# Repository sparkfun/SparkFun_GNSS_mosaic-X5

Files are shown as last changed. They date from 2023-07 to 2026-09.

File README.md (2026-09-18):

SparkFun Tri-band GNSS RTK Breakout - mosaic-X5
========================================

SparkFun Tri-band GNSS RTK Breakout - mosaic-X5 (https://www.sparkfun.com/sparkfun-triband-gnss-rtk-breakout-mosaic-x5.html)

[*SparkFun Tri-band GNSS RTK Breakout - mosaic-X5 (GPS-23088)*](https://www.sparkfun.com/sparkfun-triband-gnss-rtk-breakout-mosaic-x5.html)

At the heart of the Triband GNSS RTK Breakout is [Septentrio](https://www.septentrio.com/en)'s mosaic-X5, a compact, low power, multi-band, multi-constellation, high-precision GNSS receiver. The receiver supports the GPS (USA), GLONASS (Russia), Beidou (China), Galileo (Europe), and NavIC (India) constellations, including regional systems *(i.e. SBAS and QZSS)*. With its [**Real Time Kinematics**](https://learn.sparkfun.com/tutorials/813) (RTK) capabilities, the module can achieve a horizontal accuracy of 6mm (~0.25in), vertical accuracy of 1cm (~0.4in) using RTK, and timing precision of 5ns (5 billionths of a second). It also features Septentrio's unique [AIM+ technology](https://www.septentrio.com/en/learn-more/advanced-positioning-technology/aim-jamming-protection) for interference mitigation and anti-spoofing, ensuring best-in-class reliability and scalable position accuracy.

The mosaic-X5 is a sophisticated chip running an internal web server that can be accessed through the USB interface with a standard browser using a Linux/Windows computer. Septentrio also provides dozens of [video tutorials](https://www.youtube.com/@SeptentrioGNSS/videos) to guide users through the configuration settings of their GNSS receivers utilizing the web interface.

Beyond the capabilities of the mosaic-X5 module, this board is seamless to operate with no programming skills required. Gone are the times when a microcontroller was required to interface with the GNSS receiver and log data to an SD card and when users had to carry around an SD card reader to extract the data from the SD card. The mosaic-X5 Triband GNSS RTK Breakout can start/stop logging data or mount/unmount the SD card, without a single line of code, just utilizing a simple button. For the users who prefer a command-line interface, Septentrio has you covered. Users can still control and configure the mosaic-X5 module through a CLI, which is useful for scenarios such as production line testing *(in fact, that is how we tested this board)*.

This breakout board is a perfect middle ground for users who would like to integrate the mosaic-X5 module into a project/enclosure with access to a majority of the module's available pins, similar to Septentrio's developer kit, but in the smaller form factor of their evaluation kit. Or maybe... you just needed a PPS output at a 3.3V logic level. *Please, check out our [hookup guide](https://docs.sparkfun.com/SparkFun_GNSS_mosaic-X5) for more details on the capabilities of this board (that we couldn't fit in this product description).*

Documentation
--------------

- **[Hookup Guide (mkdocs)](http://docs.sparkfun.com/SparkFun_GNSS_mosaic-X5/)** - Hookup guide for the mosaic-X5 GNSS Breakout hosted by GitHub pages.<br>
   

Repository Contents
-------------------

- **[/docs](/docs/)** - Online documentation files
  - [assets](/docs/assets/) - Assets files
    - [board_files](/docs/assets/board_files/) - Files for the product design
      - [Eagle design files](/docs/assets/board_files/eagle_files.zip) (.zip)
      - [Schematic](/docs/assets/board_files/schematic.pdf) (.pdf)
      - [Dimensions](/docs/assets/board_files/dimensions.pdf) (.pdf)
    - [component_documentation](/docs/assets/component_documentation/) - Datasheets for hardware components
    - [img/hookup_guide/](/docs/assets/img/hookup_guide/) - Images for hookup guide documentation
- **[/Hardware](/Hardware/)** - Eagle design files (.brd, .sch)
  - **[/Production](/Production/)** - Production files

Product Variants
----------------

- mosaic-X5:
  - [GPS-23088](https://www.sparkfun.com/sparkfun-triband-gnss-rtk-breakout-mosaic-x5.html) - Triband GNSS RTK Breakout - mosaic-X5
  - [SXM-E](https://www.sparkpnt.com/products/sparkpnt-sxm-e-cors) - RTK mosaic-X5
  - [GPS-24903](https://www.sparkfun.com/sparkpnt-rtk-facet-mosaic-l-band.html) - SparkPNT RTK Facet mosaic L-Band
  - Flex Modules:
    - [GPS-28138](https://www.sparkfun.com/sparkpnt-gnss-flex-module-mosaic-x5.html) - GNSS Flex module - mosaic-X5
    - [GPS-29457](https://www.sparkfun.com/sparkpnt-gnss-flex-module-mosaic-x5-im19-imu.html) - GNSS Flex module - mosaic-X5 & IM19
    - [GPS-28766](https://www.sparkfun.com/sparkfun-gnss-flex-phat-mosaic-x5.html) - GNSS Flex pHAT w/ the mosaic-X5 GNSS Flex module
    - [GPS-29889](https://www.sparkfun.com/sparkfun-gnss-flex-phat-mosaic-x5-im19-imu.html) - GNSS Flex pHAT w/ the mosaic-X5 & IM19 GNSS Flex module
- mosaic-G5 P3:
  - [GPS-29208]( - GNSS RTK Breakout - mosaic-G5 P3
  - Flex Modules:
    - [GPS-29209](https://www.sparkfun.com/sparkpnt-gnss-flex-module-mosaic-g5-p3.html) - GNSS Flex module - mosaic-G5 P3
    - [GPS-29363](https://www.sparkfun.com/sparkpnt-gnss-flex-module-mosaic-g5-p3-im19-imu.html) - GNSS Flex module - mosaic-G5 P3 & IM19
    - [GPS-](https://www.sparkfun.com/sparkfun-gnss-flex-phat-mosaic-g5-p3.html) - GNSS Flex pHAT w/ the mosaic-G5 P3 GNSS Flex module
    - [GPS-](https://www.sparkfun.com/sparkfun-gnss-flex-phat-mosaic-g5-p3-im19-imu.html) - GNSS Flex pHAT w/ the mosaic-G5 P3 & IM19 GNSS Flex module
- mosaic-T:
  - [GPS-28731](https://www.sparkfun.com/sparkfun-timing-gnss-breakout-mosaic-t.html) - mosaic-T Timing GNSS Breakout
  - [SXT](https://www.sparkpnt.com/products/sxt-gnssdo) - GNSS Disciplined Oscillator

Version History
---------------

- [v10](https://github.com/sparkfun/SparkFun_GNSS_mosaic-X5/releases/tag/v10) - Initial Release

License Information
-------------------

This product is ***open source***!

Please review the [`LICENSE.md`](./LICENSE.md) file for license information.

If you have any questions or concerns about licensing, please contact technical support on our [SparkFun forums](https://community.sparkfun.com/).

Distributed as-is; no warranty is given.

- Your friends at SparkFun.

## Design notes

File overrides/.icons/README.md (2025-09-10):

.icons directory
====================
This folder should contain branding logos for the product documentation

## General Images
- `sfe.svg` - SparkFun flame logo
- `kicad-primary.svg` - Full KiCad logo

## Directory
- `logo` - Other available logos

## SVG Optimizer
- [Remove meta data from svg](https://jakearchibald.github.io/svgomg/)

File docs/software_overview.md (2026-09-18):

---
icon: fontawesome/solid/computer
---

!!! danger "Important: Read Before Use!"
	!!! warning "ESD Sensitivity"
		The mosaic-X5 module is sensitive to [ESD](https://en.wikipedia.org/wiki/Electrostatic_discharge "Electrostatic Discharge"). Use a proper grounding system to make sure that the working surface and the components are at the same electric potential.

		??? info "ESD Precaution"
			As recommended by the manufacturer, we highly recommend that users take the necessary precautions to avoid damaging their module.

			- The Tri-band GNSS RTK breakout board features ESD protection on the USB-C connector and breakout's I/O:
				- USB data lines
				- I/O PTH pads
				- JST connector's pins
			- The mosaic-X5 module features internal ESD protection to the `ANT_1` antenna input.

			<div class="grid cards" markdown>

			<div markdown>

			<article class="video-500px" style="margin: auto;" markdown>
			<iframe src="https://www.youtube.com/embed/hrL5J6Q5gX8?si=jOPBat8rzMnL7Uz4&amp;start=26;&amp;end=35;" title="Septentrio: Getting Started Video (playback starts at ESD warning)" frameborder="0" allow="accelerometer; autoplay; clipboard-write; encrypted-media; gyroscope; picture-in-picture" allowfullscreen></iframe>
			</article>

			</div>

			-   <a href="https://www.sparkfun.com/ifixit-anti-static-wrist-strap.html">
				<figure markdown>
				Product Thumbnail
				</figure>		

				---

				**iFixit Anti-Static Wrist Strap**<br>
				TOL-25572</a>

			</div>

!!! note
	The mosaic-X5 module has numerous capabilities and a multitude of ways to configure and interface with them. Without regurgitating all the information that is documented in Septentrio's user manuals and videos, we have tried to highlight a good majority of the module's aspects.

	With that said, please feel free to [file an issue](../github/file_issue/#discrepancies-in-the-documentation) if you feel we have missed something that may benefit other users. *(Don't forget to provide us with a link to the documentation and what section the information is located.)*

## RxTools Software Suite

!!! tip
	Even if you aren't necessarily interested it, we highly recommend that users install the [RXTools software suite](https://www.septentrio.com/en/products/gps-gnss-receiver-software/rxtools) before plugging in their board. For Windows PCs, it also includes the USB driver for the module that enables the Ethernet-over-USB support and virtual `COM` ports.

Users should install the [RXTools software suite](https://www.septentrio.com/en/products/gps-gnss-receiver-software/rxtools) on their computer to interact with the mosaic-X5 module through the USB interface. The software package includes the USB-IP driver[^1] necessary to recognize the board as an ethernet device on Windows PCs (1).
{ .annotate }

1. On Linux, the standard Linux CDC-ACM driver is suitable.

[^1]: On Linux, the standard Linux CDC-ACM driver is suitable.

<article style="text-align: center;" markdown>
[:octicons-download-16:{ .heart } Download the RxTools Software from Septentrio](https://www.septentrio.com/en/products/gps-gnss-receiver-software/rxtools){ .md-button .md-button--primary target="blank" }
</article>

??? info "System Requirements[^2]"

	=== "Operating Systems"
	
		* Windows 7
		* Windows 8
		* Windows 10
		* Fedora 23 *(or later)* using Qt technology.
			* The standalone tools (except `bin2asc`) will run on older distributions.
	
	=== "Hardware Requirements"
		The minimal hardware requirements *(1Hz update[^3])*:
	
		* CPU: 1 GHz processor
		* RAM: 1 GB RAM
		* Screen Resolution: 1024×768 or higher resolution

	[^2]: The system requirements and installation instructions are from the RxTools *v22.1.0* user manual. This information may change in later iterations of the software suite. Please refer to the user manual *(of the version you are utilizing)* for the most accurate information.
	[^3]: Higher data rates will require higher CPU speed and more memory capacity.

??? info "Installation Instructions[^2]"

	=== "Windows"
		Users can install RxTools software suite by running the installation executable[^4](1), located in the `RxTools\windows` directory of the downloaded `*.zip` file[^5]. During the installation process, users will be notified if a previous version of RxTools is already installed then that the previous version will be uninstalled. Next, users will need to provide an installation directory for the RxTools software suite. Users will then select which of the following applications[^6] are installed:
		{ .annotate }

		1. For RxTools v22.1.0, the installation filename is `RxTools_22_1_0_Installer.exe` for Windows PCs.

		<!-- Create Break from Annotation (list won't render without comment)-->

		<div class="grid" markdown>

		<div markdown>

		* RxControl
		* SBF Converter
		* SBF Analyzer
		* RxLogger

		</div>

		<div markdown>

		* RxUpgrade
		* RxDownload
		* RxPlanner

		</div>

		<div markdown>

		* Data Link
		* RxAssistant
		* RxLauncher

		</div>

		</div>

	=== "Linux[^1]"
		!!! warning
			It is recommended that users **<span style="color:red">NOT</span>** install RxControl as `root`, for security reasons and to avoid installation overwrites of other system settings. To make RxTools available to more than one user, provide a shared installation directory.

		Users can install RxTools software suite by running the installation binary[^4](1), located in the `RxTools/linux-i386/` directory of the downloaded `*.zip` file[^5]. During the installation, users will be prompted for an installation directory. If there are any previous installations of RxControl, please use a different directory to avoid conflicts.
		{ .annotate }

		1. For RxTools v22.1.0, the installation filename is `RxTools_22_1_0_Installer.bin` for Linux.

		??? info "Permission Settings"
			Once installed, users may need to reconfigure their permission settings:

			<div class="annotate" markdown>

			* RxTools will need rights to access the `/dev/ttyS*` serial ports.

				* To access the serial ports, users must be part of the `uucp` and `lock` groups (1). This can be configured by editing the `/etc/group`[^7] file and adding the username to the lines defining the `uucp` group and the `lock` group.

					For example, when adding the user `jsmith` to the `uucp` group, users would modify the `/etc/group` file as shown below:

					```bash
					{--uucp:x:14:uucp--} # (2)!
					{++uucp:x:14:uucp,jsmith++} # (3)!
					```

				* On Linux machine administered centrally on a local network, ask your system administrator to be included in the `uucp` and `lock` groups.
			* RxTools also needs read/write (`rw`) access(4) to the `/dev/ttyS*` serial ports.

				* Users can change the permissions with the `chmod`[^8] command:

					```bash
					chmod 660 /dev/ttyS<add port> # (5)!>
					```

			</div>

			1. On most Linux operating systems, the `/dev/ttyS*` devices are owned by `root` and belong to the `uucp` group with read/write (`rw`) access. Additionally, the devices are normally locked by writing a file in the `/var/lock/` directory, with the same permissions.
			2. Remove
			3. Replace with this line
			4. By default, users will normally have read/write (`rw`) access to the `/dev/ttyS*` serial ports.
			5. where users must specify the port number<br>*e.g. `/dev/ttyS0` might be port `COM1`*

			!!! note
				In order for these changes to take effect, users must update their environment by logging out and back in.

				Be aware that the X-session has to be restarted as well. On most systems, this can be done by pressing the key combination ++ctrl++ + ++alt++ + ++backspace++

		??? info "64-bit OS"
			In order to run the RxTools on a 64-bit Linux operating system, users might to install the 32-bit version of the `C` standard library.

			* For Fedora installations, this is the `glibc.i686` package.
			* The equivalent for Debian(/Ubuntu) installations is the `ia32-libs` package.

	[^4]: Users will need administrative privileges to install the RxTools software.
	[^5]: Users may need to extract the RxTools installation files from the downloaded, compressed file.
	[^6]: Please see the release notes for the issues and limitations of the RxTools applications.
	[^7]: Requires c privileges.
	[^8]: Changing these permissions also requires `root` privileges.

## USB Driver
=== "Windows"
	If users haven't already installed the [RxTools software suite](https://www.septentrio.com/en/products/gps-gnss-receiver-software/rxtools) on their Windows PC, they will need to install the USB driver[^1] necessary to recognize and interact with the mosaic-X5 module through the USB interface.

	A Windows USB driver for the mosaic-X5 can be installed through two methods:

	<div class="annotate" markdown>

	* RxTools Software Suite (1)
	* mosaic-X5 GNSS Receiver Module (2)

	</div>

	1. The driver is installed during the installation process.
	2. The installation file for the Windows USB driver will be available from the mass-storage device when the board is initially connected to the computer.

	Once installed, the driver emulates two virtual serial ports, which can be accessed as standard `COM` ports to the receiver.

	??? tip "Terminal Emulators"
		Most [terminal emulation programs](https://learn.sparkfun.com/tutorials/112) will not make a distinction between virtual or native COM ports. However, for virtual serial ports, the port settings *(i.e. baudrate, etc.)* are not relevant and the default configuration be used in the terminal emulation program. However, for the physical/native `COM` ports will have the following default setting:

		* Baudrate: 115200bps
		* Data Bits: 8
		* Parity: No
		* Stop Bits: 1
		* Flow Control: None

	??? tip "Having Trouble?"
		For users who are having trouble installing the USB driver, we have an archived version *(v3.0.2[^9])* of the installation file. Users can download [**version 3.0.2**](./assets/component_documentation/driver/USB_driver_3_0_2_Installer.exe) of the driver, by clicking on the button below.

		[^9]:
			For the latest USB driver from Septentrio, please install their driver through the [RxTools software suite](../rxtools).<br>
			*This is driver version, was archived at the time that this guide was written. Please do not request for the file to be updated.*

		<article style="text-align: center;" markdown>
		[:octicons-download-16:{ .heart } Download USB Driver *(v3.0.2)*](./assets/component_documentation/driver/USB_driver_3_0_2_Installer.exe){ .md-button .md-button--primary target="blank" }
		</article>

=== "Linux"
	On Linux, the standard Linux CDC-ACM driver is suitable.

## Web Interface
With the USB driver installed, the mosaic-X5 module supports Ethernet-over-USB. The default IP address allocated for the Ethernet-over-USB interface is `192.168.3.1`. This IP can be entered in any browser to open a connection to the receiver's Web Interface as shown below.

<div class="grid" markdown>

<div markdown>

<figure markdown>
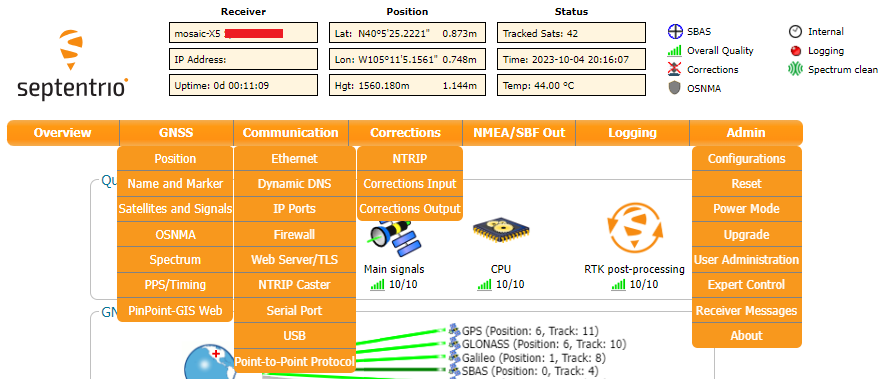
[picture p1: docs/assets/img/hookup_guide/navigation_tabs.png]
navigation tabs in the web interface

<figcaption markdown>All the drop-down navigation tabs in the web interface.</figcaption>
</figure>

</div>

<div markdown>

<article class="video-500px" style="margin: auto;" markdown>
<iframe src="https://www.youtube.com/embed/hrL5J6Q5gX8" title="Septentrio: Getting started with the Septentrio mosaic receiver module" frameborder="0" allow="accelerometer; autoplay; clipboard-write; encrypted-media; gyroscope; picture-in-picture" allowfullscreen></iframe>
</article>

</div>

</div>

!!! info
	The default IP address cannot be changed; this feature is only to be used when a single receiver is connected to your computer.

??? failure "Invalid IP Address *(WiFi Only)*"
	[One of the documentation pages on Septentrio's website](https://customersupport.septentrio.com/s/article/What-is-the-default-IP-address-to-connect-via-WiFi), specifies a default IP address of `192.168.20.1` for the web interface. However, that address is for a WiFi enabled product and cannot be used with this product.

## Arduino Library
The [Eridano-Septentrio Arduino Library](https://github.com/septentrio-gnss/Eridano) can be installed from the library manager in the Arduino IDE by searching for:

	Eridano-Septentrio Arduino Library

<div class="grid" markdown>

<div markdown>

<figure markdown>
Library listed in the library manager of the Arduino IDE Click to enlarge
<figcaption markdown>Eridano-Septentrio Arduino Library in the library manager of the Arduino IDE.</figcaption>
</figure>

</div>

<div markdown>

!!! tip "Manually Download the Arduino Library"
	For users who would like to manually download and install the library, the `*.zip` file can be accessed from the [GitHub repository](https://github.com/septentrio-gnss/Eridano) or downloaded by clicking the button below.

	<article style="text-align: center;" markdown>
	[:octicons-download-16:{ .heart } Download the Arduino Library](https://github.com/septentrio-gnss/Eridano/archive/refs/heads/main.zip){ .md-button .md-button--primary }
	</article>

</div>

</div>

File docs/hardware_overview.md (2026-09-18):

---
icon: material/cog
---

!!! danger "Important: Read Before Use!"
	!!! warning "ESD Sensitivity"
		The mosaic-X5 module is sensitive to [ESD](https://en.wikipedia.org/wiki/Electrostatic_discharge "Electrostatic Discharge"). Use a proper grounding system to make sure that the working surface and the components are at the same electric potential.

		??? info "ESD Precaution"
			As recommended by the manufacturer, we highly recommend that users take the necessary precautions to avoid damaging their module.

			- The Tri-band GNSS RTK breakout board features ESD protection on the USB-C connector and breakout's I/O:
				- USB data lines
				- I/O PTH pads
				- JST connector's pins
			- The mosaic-X5 module features internal ESD protection to the `ANT_1` antenna input.

			<div class="grid cards" markdown>

			<div markdown>

			<article class="video-500px" style="margin: auto;" markdown>
			<iframe src="https://www.youtube.com/embed/hrL5J6Q5gX8?si=jOPBat8rzMnL7Uz4&amp;start=26;&amp;end=35;" title="Septentrio: Getting Started Video (playback starts at ESD warning)" frameborder="0" allow="accelerometer; autoplay; clipboard-write; encrypted-media; gyroscope; picture-in-picture" allowfullscreen></iframe>
			</article>

			</div>

			-   <a href="https://www.sparkfun.com/ifixit-anti-static-wrist-strap.html">
				<figure markdown>
				Product Thumbnail
				</figure>		

				---

				**iFixit Anti-Static Wrist Strap**<br>
				TOL-25572</a>

			</div>

	!!! warning "Active Antenna"
		Never inject an external DC voltage into the SMA connector for the GPS antenna, as it may damage the mosaic-X5 module. For instance, when using a splitter to distribute the antenna signal to several GNSS receivers, make sure that no more than one output of the splitter passes DC. Use [DC-blocks](https://en.wikipedia.org/wiki/DC_block) otherwise.

		??? info
			A 3 - 5.5V DC voltage can be applied to the main antenna from the `VANT` pin, obviating the need for an external antenna supply or [bias-tee](https://en.wikipedia.org/wiki/Bias_tee).

## Board Dimensions
The board dimensions are illustrated in the drawing below; the listed measurements are in inches.

<figure markdown>
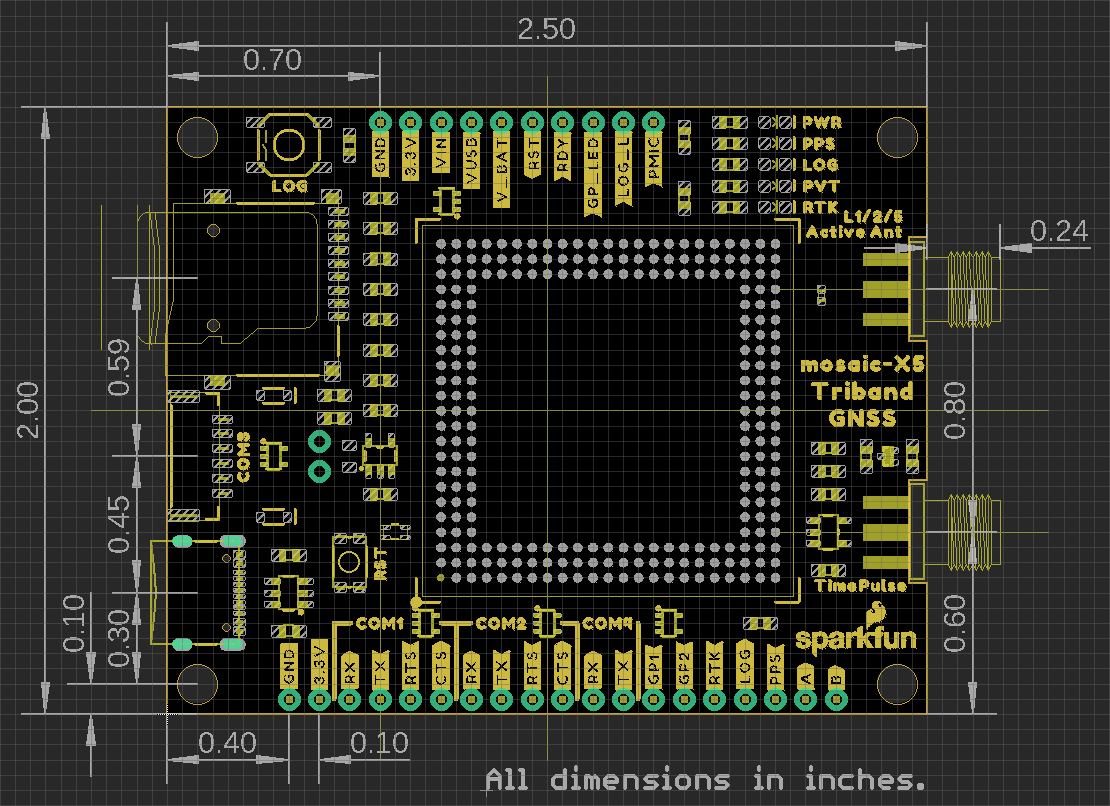
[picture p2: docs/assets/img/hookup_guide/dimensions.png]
Board Dimensions

<figcaption markdown>[Board dimensions (PDF)](./assets/board_files/dimensions.pdf) for the Tri-band GNSS RTK breakout board, in inches.</figcaption>
</figure>

??? tip "Need more measurements?"
	For more information about the board's dimensions, users can download the [eagle files](./assets/board_files/eagle_files.zip) for the board. These files can be opened in Eagle and additional measurements can be made with the dimensions tool.

	??? info ":octicons-download-16:{ .heart } Eagle - Free Download!"
		Eagle is a [CAD]("computer-aided design") program for electronics that is free to use for hobbyists and students. However, it does require an account registration to utilize the software.

		<article style="text-align: center;" markdown>
		[Download from<br>:autodesk-primary:{ .autodesk }](https://www.autodesk.com/products/eagle/free-download "Go to downloads page"){ .md-button .md-button--primary width="250px" }
		</article>
	
	??? info ":straight_ruler: Dimensions Tool"
		This video from Autodesk demonstrates how to utilize the dimensions tool in Eagle, to include additional measurements:

		<article style="text-align: center;" markdown>
		<div class="video-500px" style="margin: auto;" markdown>
		<iframe src="https://www.youtube.com/embed/dZLNd1FtNB8" title="EAGLE Dimension Tool" frameborder="0" allow="accelerometer; autoplay; clipboard-write; encrypted-media; gyroscope; picture-in-picture" allowfullscreen></iframe>
		</div>
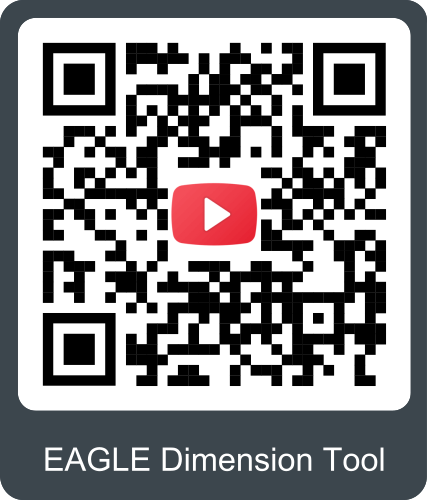
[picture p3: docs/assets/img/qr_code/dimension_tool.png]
QR code to play video
		
		</article>

## USB-C Connector
The USB connector is provided to power and interface with the mosaic-X5 GNSS receiver. For most users, it will be the primary method for communicating with the mosaic-X5 module.

<div class="grid" markdown>

<figure markdown>
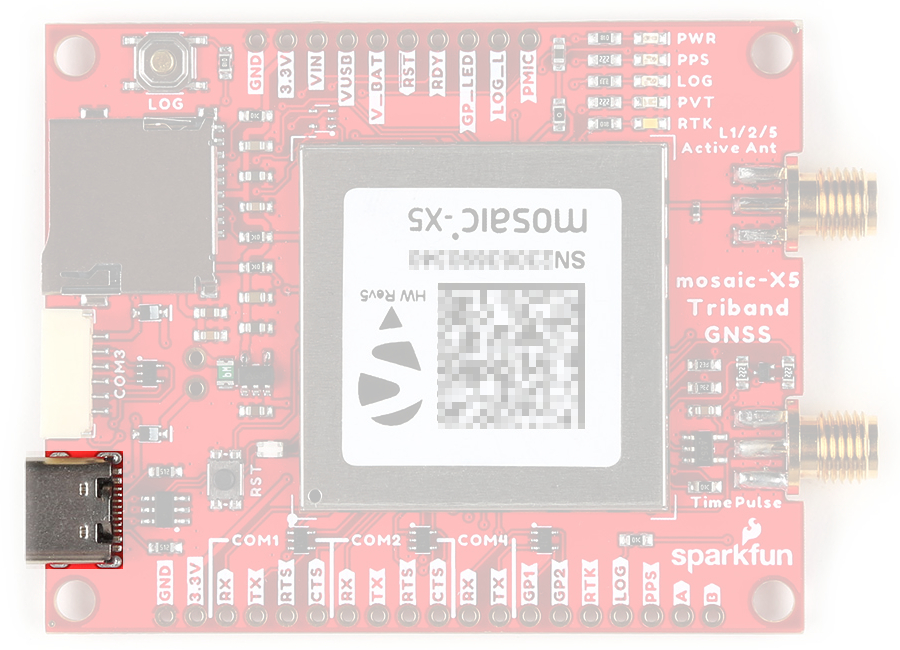
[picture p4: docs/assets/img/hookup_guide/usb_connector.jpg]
USB-C Connector

<figcaption markdown>USB-C connector on the Tri-band GNSS RTK breakout board.</figcaption>
</figure>

<div markdown>

!!! bug "Test Pads"
	We accidentally mislabeled the test pads underneath the USB-C connector. The silkscreen for the `D+` and `D-` signal lines are reversed.

	<figure markdown>
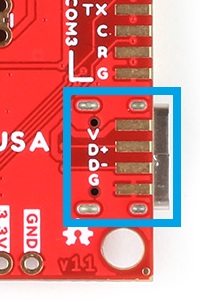
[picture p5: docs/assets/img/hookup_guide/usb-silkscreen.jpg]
USB Silkscreen
	
	<figcaption markdown>The silkscreen for the USB interface on the Tri-band GNSS RTK breakout board.</figcaption>
	</figure>

</div>

</div>

## Power
The Tri-band GNSS RTK breakout board only requires **5V** to power all of the board's components. The simplest method to power the board is through the USB-C connector. Alternatively, the board can be converted to utilize **3.3V** for low power applications.

<figure markdown>
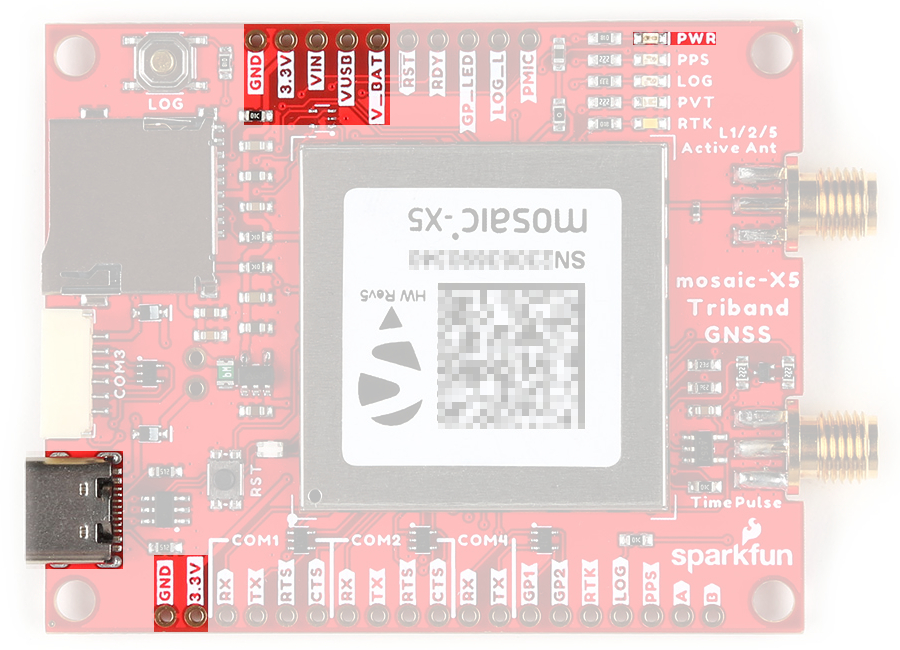
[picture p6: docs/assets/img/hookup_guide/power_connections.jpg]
Power connections

<figcaption markdown>Tri-band GNSS RTK breakout board's power connections.</figcaption>
</figure>

Below, is a general summary of the power circuitry on the board, broken out as [PTH](https://en.wikipedia.org/wiki/Through-hole_technology "Plated Through Holes") pins:

<div class="annotate" markdown>

* **`VUSB`** - The voltage from the USB-C connector, usually **5V**.
	* Input Voltage Range: 4.4 - 5.5 V
	* Power source for the entire board.
		* Powers the 3.3V voltage regulator (AP2112) and the active antenna preamplifier for the mosaic-X5 module. (1)
		* This pin powers the integrated PHY of the mosaic-X5 module's USB interface.
	* Features ESD protection	and a thermal fuse.
* **`VIN`** - Alternate input supply voltage for the board.
	* Alternative power supply input for the board, excluding the integrated PHY of the USB interface.
	* Power source for the entire board.
		* Powers the 3.3V voltage regulator (AP2112) and the active antenna preamplifier for the mosaic-X5 module. (2)
	* Features a thermal fuse.
* **`3.3V`** - Provides a regulated 3.3V from [AP2112](./assets/component_documentation/AP2112.pdf) using the power from the `VIN` or `VUSB` (5V) inputs.
	* Input Voltage Range: 3.135 - 3.465 V
	* The **3.3V** AP2112 LDO regulator can source up to 600mA.
		* Used to power the mosaic-X5 module, SD card slot, and the power LED.
		* The active antenna preamplifier (3) for the mosaic-X5 module can be alternatively powered with 3.3V *(see the **[Jumpers](#jumpers)** and **[mosaic-X5](#mosaic-X5)** sections)*.
* **`V_BATT`** - *Always-on* power supply
	* Input Voltage Range: 3.135 - 3.465 V
	* Tied to `3.3V` *(see the **[Jumpers](#jumpers)** section)*.
		* Used to power the module in **Standby** mode.
* **`GND`** - The common ground or the 0V reference for the voltage supplies.

</div>

1. * While the [AP2112](./assets/component_documentation/AP2112.pdf) LDO regulator has an input voltage range of 2.5 - 6V, a minimum supply voltage of **3.5V** is recommended for a 3.3V output.
	* A 3 - 5.5V DC voltage can be applied to the main antenna from the `VANT` pin, obviating the need for an external antenna supply or [bias-tee](https://en.wikipedia.org/wiki/Bias_tee).
2. * While the [AP2112](./assets/component_documentation/AP2112.pdf) LDO regulator has an input voltage range of 2.5 - 6V, users should supply:

		* A minimum of **3.5V** for a 3.3V output from the regulator
		* A maximum of **5.5V** as not to exceed the electrical limitations of the mosaic-X5 module

	* A 3 - 5.5V DC voltage can be applied to the main antenna from the `VANT` pin, obviating the need for an external antenna supply or [bias-tee](https://en.wikipedia.org/wiki/Bias_tee).

3. A 3 - 5.5V DC voltage can be applied to the main antenna from the `VANT` pin, obviating the need for an external antenna supply or [bias-tee](https://en.wikipedia.org/wiki/Bias_tee).

??? tip "`VIN` Input Voltage"
	While the [AP2112](./assets/component_documentation/AP2112.pdf) LDO regulator has an input voltage range of 2.5 - 6V, users should supply:

	* A minimum of **3.5V** for a 3.3V output from the regulator
	* A maximum of **5.5V** as not to exceed the electrical limitations of the mosaic-X5 module

	However, users are able to bypass the electrical limitations of the mosaic-X5 module and power the board with up to 6V. Users just need to modify the `ANT_V` jumper *(see the **[Jumpers](#jumpers)** section)* to the `3V3` pad.

??? tip "`MEAS` Pins"
	These pins can be used to measure the current being drawn through the USB connector or `VUSB`/`VIN` pins *(see the **[Jumpers](#jumpers)** section)*.

??? tip "JST Connector"
	The `V` pin of the JST connector is designed for an input voltage to `VIN`. By default, it does not operate as a voltage output.
	
	!!! warning "Bypass - Reverse Current Protection Diode"
		!!! danger "Danger - Proceed at Your Own Risk!"
			By bypassing the reverse current protection diode, users should take precautions to ensure that they do not provide an input voltage to the JST connector, when the board is connected to their computer. Otherwise, it may result in damage to the computer's USB bus.

		To enable an output voltage on the JST connector, users will need to bypass the protection diode that prevents reverse current to the USB-C connector. This can be done by jumping the `VUSB` and `VIN` pins together.

		Once jumpered, when the board is powered through the USB-C connector, the `V` pin of the JST connector will provide an output voltage from the USB-C connector.

!!! info
	For more details, users can reference the [schematic](./assets/board_files/schematic.pdf) and the datasheets of the individual components on the board.

### Power Modes
The mosaic-X5 module operates in three different power states.

<div class="annotate" markdown>

* Off - The module is completely turned off
	* When transitioning to the **Off** state from **Active**, recent data may not be lost and not logged to the external SD card
* Standby - The module is in a low-power consumption mode (1)
	* The module power consumption in standby is <5mW
	* The `PMIC_ON_REQ` pin is driven `LOW`
	* The `MODULE_RDY` pin is in a `LOW`
	* Monitors the state of the `ONOFF` pin *(Not available)*
* Active - The module is operating with all functions active
	* On power up, the module restarts in the configuration stored in the boot configuration file
	* The `PMIC_ON_REQ` pin is driven `HIGH`
	* The `MODULE_RDY` pin is in a `HIGH` (2)

</div>

1. Essentially, the same state as **Off**; except in the transition to the **Standby** mode, before the module shuts down:
	* All logging tasks are terminated
	* The SD card is unmounted
	* The `PMIC_ON_REQ` pin is driven `LOW`
1. Level becomes `HIGH` about 300ms after powering up, reset, or waking up from standby

!!! info
	By default, the board is hardwired to operate only in the **Active** and **Off** modes.

	*For more information on the power management of the mosaic-X5 module, please refer to sections **3.4**, **3.5**, **4.1**, and **4.13** of the [hardware manual](./assets/component_documentation/mosaic_hardware_manual_v1.11.0.pdf).*

??? Tip "Enabling **Standby** Mode"
	Users can enable **Standby** mode on the mosaic-X5, by modifying the `V_BATT` jumper *(see the **[Jumpers](#jumpers)** section)* and providing an external power source for the `V_BATT` pin *(3.3V)*. However, because the `ONOFF` pin isn't exposed users will need to power cycle the board to return to the **Active** state.

??? tip "Drive Current - `PMIC_ON_REQ`/`MODULE_RDY`"
	The drive current on the `PMIC_ON_REQ` and `MODULE_RDY` pins is low. Enough to be read by a digital pin on a microcontroller, but not high enough to drive an LED.

### Power Consumption
The power consumption of the mosaic-X5 module depends on the GNSS signals enabled and the positioning mode. The table below, lists the average power consumption for common configurations. The current listed, is based on a supply voltage of 3.3V.

<article style="text-align: center;" markdown>

| GNSS Signals | Positioning Mode | Power (mW) | Current (mA) |
| :--- | :--- | :---: | :---: |
| GPS L1 C/A | Stand-Alone (1Hz) | 550 | 167 |
| GPS L1/L2 | RTK (1Hz) | 670 | 203 |
| GPS/GLONASS L1/L2 | RTK (1Hz) | 695 | 211 |
| GPS/GLONASS L1/L2+GALILEO L1/E5a +BeiDou B1C/B2a | RTK (1Hz) | 850 | 258 |
| GPS/GLONASS L1/L2+GALILEO L1/E5a +BeiDou B1C/B2a | RTK (100 Hz) | 930 | 282 |
| GPS/GLONASS L1/L2 + L-band | PPP (1Hz) | 760 | 230 |
| All signals from all GNSS constellations | Static (1Hz) | 910 | 276 |
| All signals from all GNSS constellations +L-band | Static(1Hz) | 980 | 297 |
| All signals from all GNSS constellations +L-band | Static (100Hz) | 1080 | 327 |

*Source: [mosaic-X5 Hardware Manual](./assets/component_documentation/mosaic_hardware_manual_v1.11.0.pdf)*
</article>

## :fontawesome-solid-microchip:&nbsp; mosaic-X5
The centerpiece of the Tri-band GNSS RTK breakout board, is the [mosaic-X5 module](./assets/component_documentation/mosaic_hardware_manual_v1.11.0.pdf) from [Septentrio](https://www.septentrio.com/en). Their mosaic modules are low-power, multi-band, multi-constellation GNSS receivers capable of delivering centimeter-level precision at high update rates. The modules also feature Septentrio's unique [AIM+ technology](https://www.septentrio.com/en/learn-more/advanced-positioning-technology/aim-resilient-and-secure-gnss/gps-receivers) for interference mitigation and anti-spoofing, which ensures their best-in-class reliability and scalable position accuracy.

<div class="grid cards" markdown>

<div markdown>

<article class="video-500px" style="margin: auto;" markdown>
<iframe src="https://www.youtube.com/embed/Co8hrVeklAA" title="Septentrio: Mosaic - GNSS / GPS module receiver range" frameborder="0" allow="accelerometer; autoplay; clipboard-write; encrypted-media; gyroscope; picture-in-picture" allowfullscreen></iframe>
</article>

</div>

-   <figure markdown>
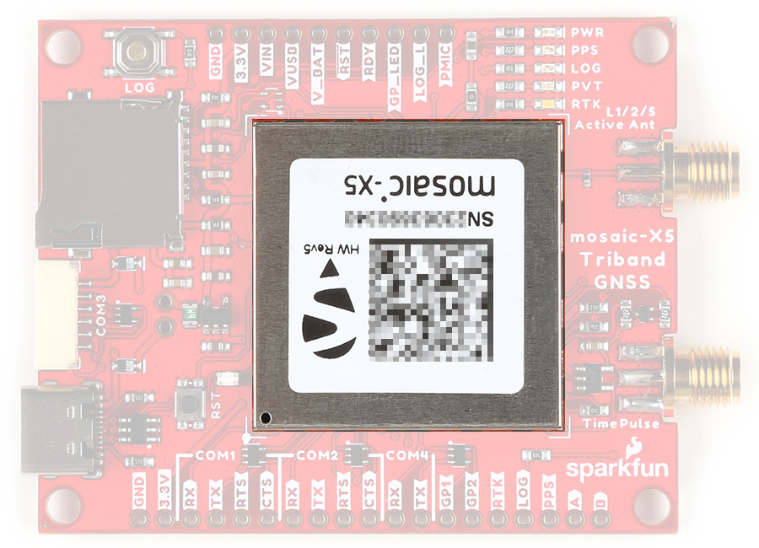
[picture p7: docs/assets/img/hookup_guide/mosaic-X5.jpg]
mosaic-X5 module
	
	<figcaption markdown>The mosaic-X5 module on the Tri-band GNSS RTK breakout board.</figcaption>
	</figure>

</div>

<div class="grid" markdown>

<div markdown>

**Features:**

* Operating Voltage: **3.135 - 3.465V**
* Operating Temperature: -40 - 85&deg;C
* GNSS Support
	* GPS: L1C/A, L1PY, L2C, L2P, L5
	* GLONASS: L1CA, L2CA, L2P, L3 CDMA
	* Beidou: B1I, B1C, B2a, B2b, B2I, B3
	* Galileo: E1, E5a, E5b, E5 AltBoc, E6
	* QZSS: L1C/A, L1 C/B, L2C, L5
	* Navic: L5
	* SBAS: Egnos, WA
* Antenna Specifications
	* Preamplification Range: 15-50dB
	* Bias Voltage: 3.0 - 5.5V
	* 448 Hardware Channels
* Update Rate: 100Hz
* Latency: < 10ms

</div>

<div markdown>

<br>

* Time to Fix
	* Cold Start: < 45s
	* Warm: < 20s
	* Reacquisition: 1s
* Timing Precision: 5ns
* Position Accuracy

	<article style="text-align: center;" markdown>

	| Correction | Horizontal                             | Vertical                     |
	| :--------- | :------------------------------------: | :--------------------------: |
	| RTK        | **0.6cm** *(&plusmn;0.5ppm)*<br>~0.25" | 1cm *(&plusmn;1ppm)*<br>~.4" |
	| DGNSS      | 40cm<br>~1.3'                          | 70cm<br>~2.3'                |
	| SBAS       | 60cm<br>~2'                            | 80cm<br>~2.6'                |
	| Standalone | 1.2m<br>~4'                            | 1.9m<br>~6.2'                |

	</article>

</div>

</div>

!!! info
	The mosaic-X5 has three power modes: **Active**, **Standby**, and **Off** *(see the **[Power Modes](#power-modes)** section)*.

### Frequency Bands
The mosaic modules are multi-band, multi-constellation GNSS receivers. Below, are charts illustrating the frequency bands utilized by all the global navigation satellite systems and the ones supported by the mosaic-X5 module.

<figure markdown>
Supported frequency bands
<figcaption markdown>The frequency bands supported by the mosaic-X5 GNSS receiver.</figcaption>
</figure>

<figure markdown>
GNSS frequency bands (https://www.tallysman.com/app/uploads/2021/07/Tallysman-GNSS-Frequencies-v8.0_Chart-1-1024x425.png "Click to enlarge")
<figcaption markdown>Frequency bands of the global navigation satellite systems. (Source: [Tallysman](https://www.tallysman.com/gnss-constellations-radio-frequencies-and-signals/))</figcaption>
</figure>

!!! info
	For a comparison of the frequency bands supported by the mosaic modules, refer to section **3.1** of the [hardware manual](./assets/component_documentation/mosaic_hardware_manual_v1.11.0.pdf).

	??? info "What are Frequency Bands?"
		A [frequency band](https://en.wikipedia.org/wiki/Frequency_band) is a section of the [electromagnetic spectrum](https://en.wikipedia.org/wiki/Electromagnetic_spectrum), usually denoted by the range of its upper and lower limits. In the [radio spectrum](https://en.wikipedia.org/wiki/Radio_spectrum), these frequency bands are usually regulated by region, often through a government entity. This regulation prevents the interference of RF communication; and often includes major penalties for any interference with critical infrastructure systems and emergency services.

		<figure markdown>
		GNSS frequency bands (https://gssc.esa.int/navipedia/images/c/cf/GNSS_All_Signals.png "Click to enlarge")
		<figcaption markdown>Frequency bands of the global navigation satellite systems. (Source: [ESA](https://gssc.esa.int/navipedia/index.php?title=File:GNSS_All_Signals.png "European Space Agency"))</figcaption>
		</figure>

		However, if the various GNSS constellations share similar frequency bands, then how do they avoid interfering with one another? Without going too far into detail, the image above illustrates the frequency bands of each system with a few characteristics specific to their signals. Wit these characteristics in mind, along with other factors, the chart can help users to visualize how multiple GNSS constellations might co-exist with each other.

		For more information, users may find these articles of interest:

		* [GNSS signal](https://gssc.esa.int/navipedia/index.php/GNSS_signal)
		* [GPS Signal Plan](https://gssc.esa.int/navipedia/index.php?title=GPS_Signal_Plan)
		* [GLONASS Signal Plan](https://gssc.esa.int/navipedia/index.php?title=GLONASS_Signal_Plan)
		* [GALILEO Signal Plan](https://gssc.esa.int/navipedia/index.php?title=GALILEO_Signal_Plan)

### Position Accuracy
<div class="grid" markdown>

<div markdown>

The accuracy of the position reported from the mosaic-X5 module, can be improved based upon the correction method being employed. Currently, [RTK](https://en.wikipedia.org/wiki/Real-time_kinematic_positioning "Real-Time Kinematic") corrections provide the highest level of accuracy; however, users should be aware of certain limitations of the system:

* RTK technique requires real-time correction data from a reference station or network of base stations.
	* RTK corrections are signal specific *(i.e. an RTK network might provide corrections on only `E5b` and not `E5a`)*.
* The range of the base stations will vary based upon the RTK method being employed.
* The reliability of RTK corrections are inherently reduced in [multipath environments](https://en.wikipedia.org/wiki/Multipath_propagation). However, with Septentrio's multipath mitigation technology ([APME+](https://www.septentrio.com/en/learn-more/Advanced-positioning-technology/gnss-technology/multipath-mitigation-technology "A-Posteriori Multipath Estimation")) on the mosaic-X5, these errors are significantly reduced when compared to multipath mitigation techniques that modify the correlators in the tracking channels.

</div>

<div markdown>

<article style="text-align: center;" markdown>

| Correction | Horizontal | Vertical |
| :--- | :---: | :---: |
| [RTK](https://en.wikipedia.org/wiki/Real-time_kinematic_positioning "Real-Time Kinematic") | **0.6cm** *(&plusmn;0.5ppm)*<br>~0.25" | 1cm *(&plusmn;1ppm)*<br>~.4" |
| [DGNSS](https://en.wikipedia.org/wiki/Differential_GPS "Differential GNSS") | 40cm<br>~1.3' | 70cm<br>~2.3' |
| [SBAS](https://en.wikipedia.org/wiki/GNSS_augmentation "Satellite-Based Augmentation System") | 60cm<br>~2' | 80cm<br>~2.6' |
| Standalone | 1.2m<br>~4' | 1.9m<br>~6.2' |

</article>

</div>

</div>

??? info "RTK Corrections"
	To understand how RTK works, users will need a more fundamental understanding of the signal error sources.

	<div class="grid cards" markdown align="center">

	-   <a href="https://www.sparkfun.com/news/7533">
		<figure markdown>
		Tutorial Thumbnail
		</figure>

		---

		**Real-Time Kinematics Explained**</a>

	-   <a href="https://www.sparkfun.com/news/7138">
		<figure markdown>
		Tutorial Thumbnail
		</figure>

		---

		**What is Correction Data?**</a>

	-   <a href="https://www.septentrio.com/en/learn-more/insights/gnss-corrections-demystified">
		<figure markdown>
		Tutorial Thumbnail
		</figure>

		---

		**GNSS Corrections Demystified**</a>

	</div>

!!! tip
	For the best performance, we highly recommend that users configure the module to utilize/provide RTK corrections with a compatible L1/L2/L5 (tri-band) GNSS antenna and utilize a low-loss cable.

### Peripherals and I/O Pins
The mosaic-X5 features several peripherals and I/O pins. Some of these are broken out as pins on the Tri-band GNSS RTK breakout board; whereas, others are broken out to their specific interface *(i.e. &micro;SD Card slot, USB connector, etc.)*. Additionally, some of their connections are tied to other components on the board.

<div class="grid" markdown>

<div markdown>

<figure markdown>
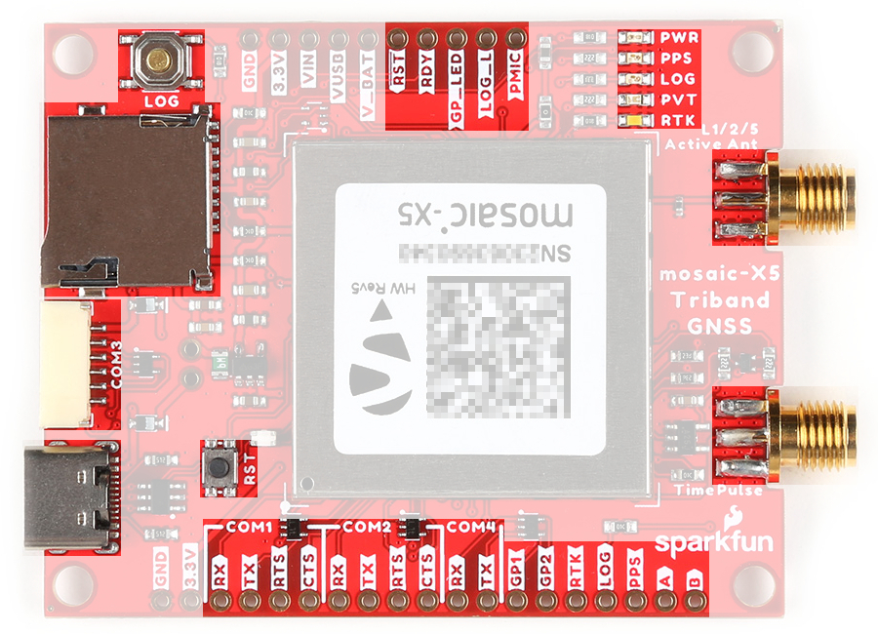
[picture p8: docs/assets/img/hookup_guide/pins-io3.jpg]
Peripherals and I/O pins

<figcaption markdown>The peripherals and I/O pins on the Tri-band GNSS RTK breakout board.</figcaption>
</figure>

</div>

<article class="annotate" markdown>
**Interfaces:**

- 4x UART (LVTTL, up to 4 Mbps)
- ~~Ethernet (RMII/MDIO), 10/100 Mbps~~(1)
- USB device (2.0, HS)
- SDIO (mass storage)
- 2x GPIO user programmable
- 2x Event markers
- 1x Configurable PPS out

</article>

1. Not available on the Tri-band GNSS RTK breakout board.

</div>

=== "USB"
	For most users, this will be the primary interface for the mosaic-X5 module.

	<figure markdown>
	USB interface
	<figcaption markdown>USB-C connector on the Tri-band GNSS RTK breakout board.</figcaption>
	</figure>

	<div class="annotate" markdown>

	* When a module is initially connected to a computer, the board will initialize as a USB mass storage device.
		* For Windows PCs, the USB driver (1) can be installed from the mass storage device or the RxTools software suite.
		* When the SD card is mounted, this drive will contain the contents of the SD card that is inserted on the board.
	* Once the USB driver is installed:
		* Two virtual `COM` ports are emulated, which can be used as standard `COM` ports to access the receiver.
		* This interface will support Ethernet-over-USB.
			* By default, the receiver is not allowed to access the Internet over USB.
			* The IP address allocated to the Ethernet-over-USB interface is `192.168.3.1`.
				* The IP address cannot be changed; therefore, only single receiver should be connected to your computer at a time.

	</div>

	1. On Linux, the standard Linux CDC-ACM driver is suitable.

=== "UARTs"
	The mosaic-X5 has four UARTs that are organized into separate `COM` ports. The operation for each of these ports can be configured separately.

	<figure markdown>
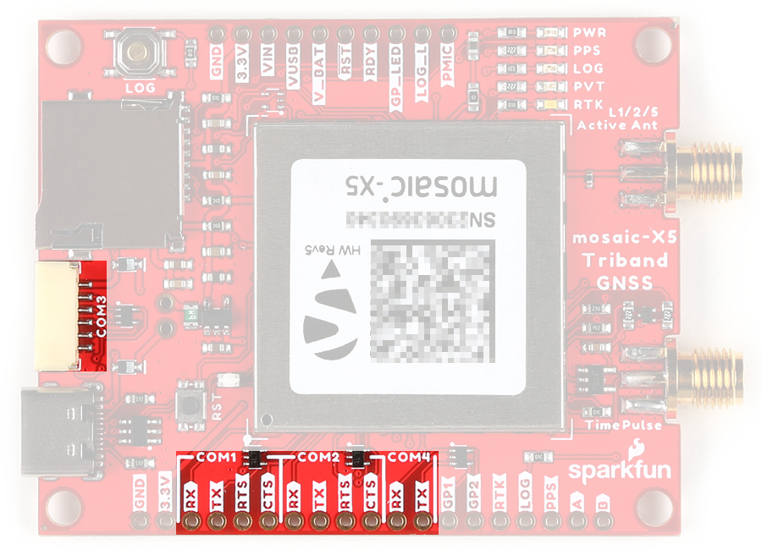
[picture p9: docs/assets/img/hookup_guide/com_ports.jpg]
UART interface
	
	<figcaption markdown>The `COM` ports on the Tri-band GNSS RTK breakout board.</figcaption>
	</figure>

	<div class="annotate" markdown>
	
	* `COM` ports 1-3 feature flow control pins, which are disabled by default.
	* `COM3` is available through the JST connector(1), but the pins can also be accessed from the pads on the bottom of the board.
	* These ports also support a point-to-point protocol server, by which it can accept TCP/IP connections over a serial link.

	</div>

	1. <div class="grid" markdown>

		<a href="https://www.sparkfun.com/breadboard-to-jst-ghr-06v-cable-6-pin-x-1-25mm-pitch.html">
		<figure markdown>
		Product Thumbnail
		</figure>

		---

		**Breadboard to JST-GHR-06V Cable - 6-Pin x 1.25mm Pitch**<br>
		CAB-18079</a>

		</div>

	!!! info
		By default, the `COM` ports will be configured with the following settings:

		* Baudrate: 115200bps
		* Data Bits: 8
		* Parity: No
		* Stop Bits: 1
		* Flow Control: None

	??? tip "Pin Connections"
		When connecting to the board's UART pins, the pins should be connected based upon the flow of their data. For example, when utilizing the [Telemetry Radio](https://www.sparkfun.com/sik-telemetry-radio-v3-915mhz-100mw.html) or the [LoRaSerial Kit](https://www.sparkfun.com/sparkfun-loraserial-kit-915mhz-enclosed.html):

		<figure markdown>
		Flow Control (https://docs.sparkfun.com/SparkFun_LoRaSerial/img/SAMD21%20Flow%20control.png "Click to enlarge")
		<figcaption markdown>Connection of the UART pins from the [LoRaSerial radio](https://www.sparkfun.com/sparkfun-loraserial-kit-915mhz-enclosed.html) to a host system, like the Tri-band GNSS RTK breakout board.</figcaption>
		</figure>

=== "Antenna"
	Users will need to connect a compatible GPS antenna to the `L1/2/5 ActiveAnt` SMA connector. The type of antenna used with the mosaic-X5 module affects the overall accuracy of the positions calculated by the GNSS receiver.

	* An active antenna often features a [LNA](https://en.wikipedia.org/wiki/Low-noise_amplifier "low-noise amplifier"). This allows the module to boost the signal received by the GNSS module without degrading the [SNR](https://en.wikipedia.org/wiki/Signal-to-noise_ratio Signal-to-noise ratio).
	* The more bands an antenna supports, the greater the performance.
		* Faster acquisition time.
		* Access and support for the `L5` GPS band can potentially mitigate multi-path errors.
		* Supporting more frequency bands, allows a GNSS receiver to be less susceptible to jamming and spoofing.

	!!! tip
		For the best performance, we recommend users choose a compatible L1/L2/L5 (tri-band) GNSS antenna and utilize a low-loss cable.

	There are some key parameters related to an antenna that can make or break the signal reception from the satellites. These include the operation frequency, gain, polarization, efficiency and overall loss.

	<figure markdown>
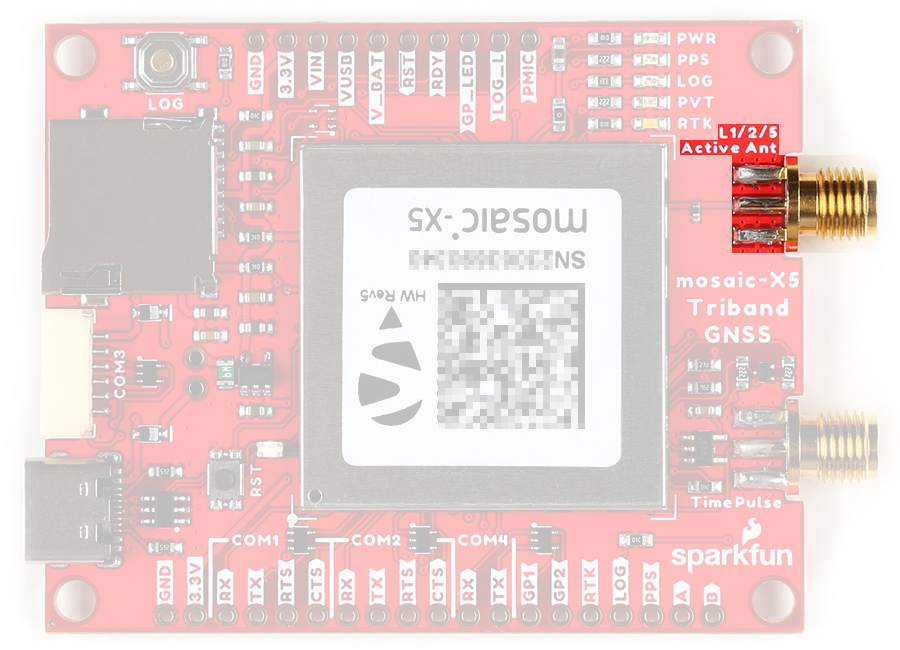
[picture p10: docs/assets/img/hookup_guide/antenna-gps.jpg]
GPS antenna input
	
	<figcaption markdown>The SMA connector to attach a GPS antenna to the Tri-band GNSS RTK breakout board.</figcaption>
	</figure>

	!!! info
		The `VANT` pin provides external power for an active antenna. By default, this supply voltage is configured at **5V** *(see the **[Jumpers](#jumpers)** section)*.

		!!! danger
			Never inject an external DC voltage into the SMA connector for the GPS antenna, as it may damage the mosaic-X5 module. For instance, when using a splitter to distribute the antenna signal to several GNSS receivers, make sure that no more than one output of the splitter passes DC. Use [DC-blocks](https://en.wikipedia.org/wiki/DC_block) otherwise.

=== "PPS Output"
	From the module, the [PPS](https://en.wikipedia.org/wiki/Pulse-per-second_signal "Pulse Per Second") output signal's logic-level is 1.8V. However, for the convenience of users, we have added a buffer and bumped up the signal's logic-level to 3.3V on the Tri-band GNSS RTK breakout. This 3.3V signal output can be access through the SMA connector and the `PPS` pin. The signal is also connected to the `PPS` LED, to be used as a visual indicator.

	<figure markdown>
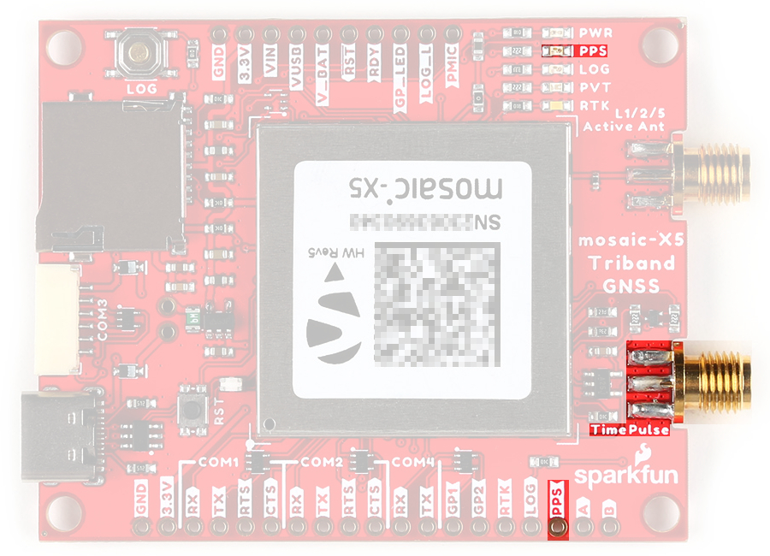
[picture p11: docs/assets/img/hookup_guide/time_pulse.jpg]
I/O for PPS signal
	
	<figcaption markdown>The `PPS` signal's outputs on the Tri-band GNSS RTK breakout board.</figcaption>
	</figure>

	??? tip "Jumpers"
		*See the **[Jumpers](#jumpers)** section for more details.*

		* There is a jumper attached to the `PPS` pin. When cut, it disconnects the pin from the PPS signal.
		* There is a jumper attaches to the `PPS` LED. For low power applications, the jumper can be cut to disable the `PPS` LED.

	??? tip "Use Case"
		* Users could use this signal in conjunction with the event pins to synchronize two mosaic-X5 modules with each other.
		* Users could use this signal to create their own **Stratum 0** source for the [NTP](https://en.wikipedia.org/wiki/Network_Time_Protocol "Network Time Protocol") on a primary time server.

=== "Data Logging"
	The data logging functionality of the board can be configured through the software/web interfaces or through the use of the ++"LOG"++ button or `LOG` pin (1). Data logging activity will be indicated by the `LOG` status LED (2).
	{ .annotate }

	1.	The ++"LOG"++ button and `LOG` pin are connected to the same active-high, input of the mosaic-X5. Pressing the button or pulling the pin low will toggle the data logging feature. Whereas, holding them for more than 5 seconds will mount/unmount the SD card *(see the [**Log Button**](#log-button) section)*.
	2.	See the [**SD Card Slot**](#sd-card-slot) section

	<div class="grid" markdown>

	<div markdown>
	
	<figure markdown>
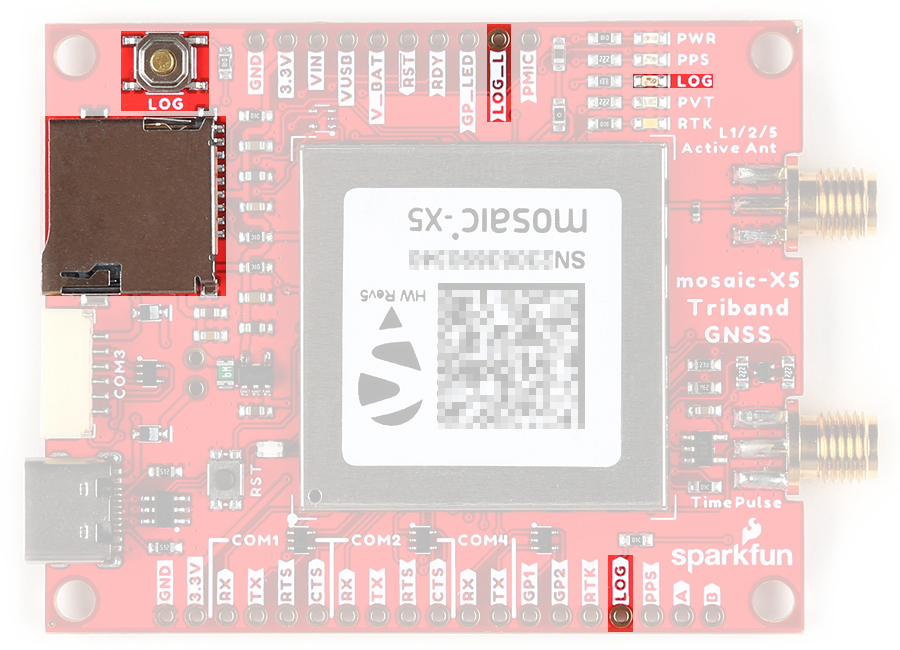
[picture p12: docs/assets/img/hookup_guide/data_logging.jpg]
Data logging components
	
	<figcaption markdown>The data logging peripherals on the Tri-band GNSS RTK breakout board.</figcaption>
	</figure>

	</div>

	<div markdown>

	* Button
		* ++"LOG"++ - Connected to the `LOG` pin
	* Pins
		* `LOG` - Connected to the ++"LOG"++ button
		* `LOG_L` - Connected to the `LOG` LED
		* &micro;SD Card Slot - Connected to the SDIO pins
	* LED
		* `LOG` - Connected to the `LOG_L` pin

	</div>

	</div>

=== "LED Pins"
	The mosaic-X5 module features two general purpose, output LED pins. These pins have a maximum output current of 10 mA and output impedance of 20&ohm;. In addition, to these pins, there are several status LEDs on the board *(see the [**Status LEDs**](#status-leds) section)*.

	* The general purpose LED pins are connected to the `RTK` and `PVT` LEDs; and respectively, the `RTK` and `GP_LED` pins.
	* The PPS output signal is connected to the `PPS` pin, `PPS` LED, and `TimePulse` SMA connector.
	* The `LOG_L` pin is connected to the `LOG` LED.

	<figure markdown>
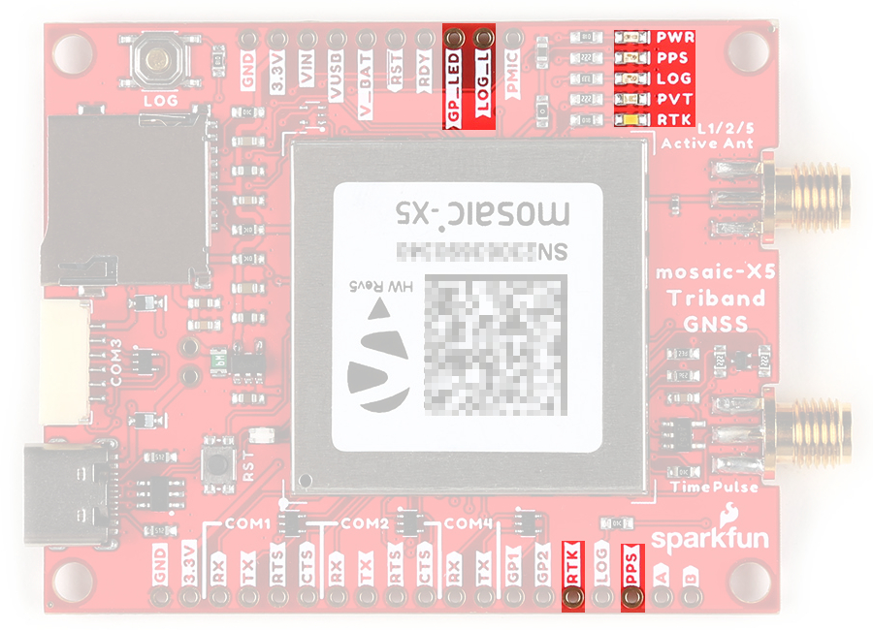
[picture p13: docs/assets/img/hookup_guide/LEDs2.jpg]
LED pins
	
	<figcaption markdown>The LED pins on the Tri-band GNSS RTK breakout board.</figcaption>
	</figure>

	!!! info
		See the [**Status LEDs**](#status-leds) section.

=== "GPx Pins"
	The mosaic-X5 module features two general purpose, output pins. These pins can drive a maximum current of 10mA.

	<figure markdown>
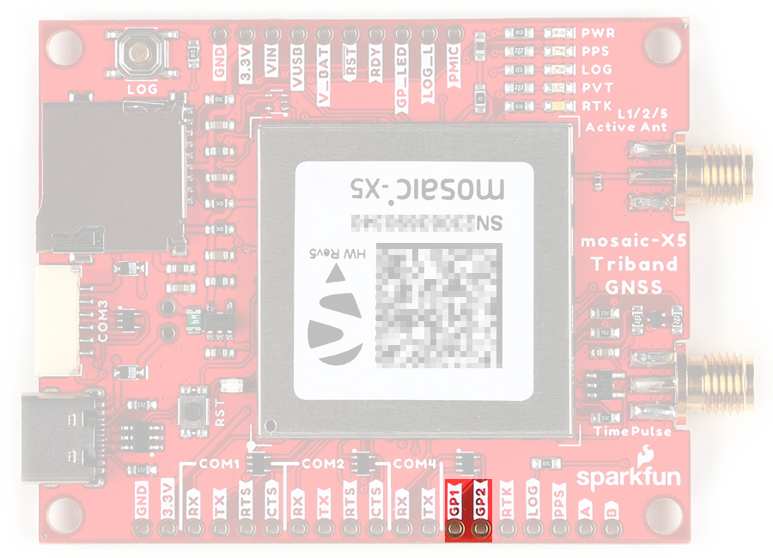
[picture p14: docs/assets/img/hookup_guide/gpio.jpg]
	
	<figcaption markdown>The `GPx` pins on the Tri-band GNSS RTK breakout board.</figcaption>
	</figure>

=== "Event Pins"
	The mosaic-X5 module features two general purpose, event input pins. These pins can be used to time tag external events with a time resolution of 20ns.

	<figure markdown>
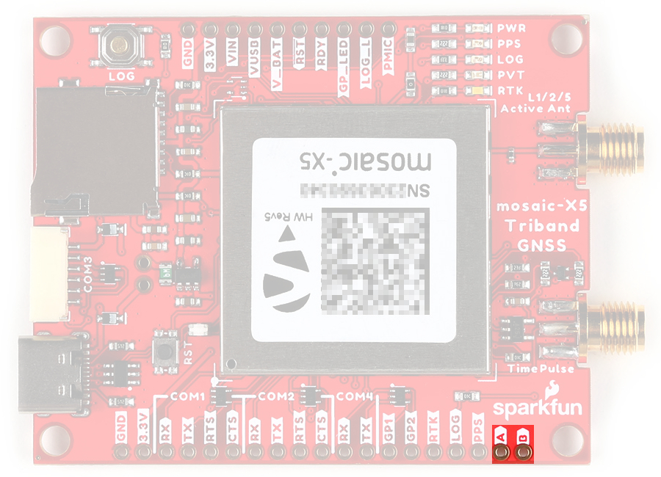
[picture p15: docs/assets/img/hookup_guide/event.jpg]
	
	<figcaption markdown>The event pins on the Tri-band GNSS RTK breakout board.</figcaption>
	</figure>

	??? tip
		For example, these pins can be used in conjunction with the PPS output signal for time syncing.

=== "Other Pins"

	<div class="grid" markdown>

	<div markdown>

	=== "`PMIC` Pin"
		The state of `PMIC` pin indicates when the subsystems are energized and ready *(see the [**Power Modes**](#power-modes) section)*. It can be used as a power switch to drive external power to the antenna (`VANT`) *(see the [**Jumpers**](#jumpers) section)*.

		<figure markdown>
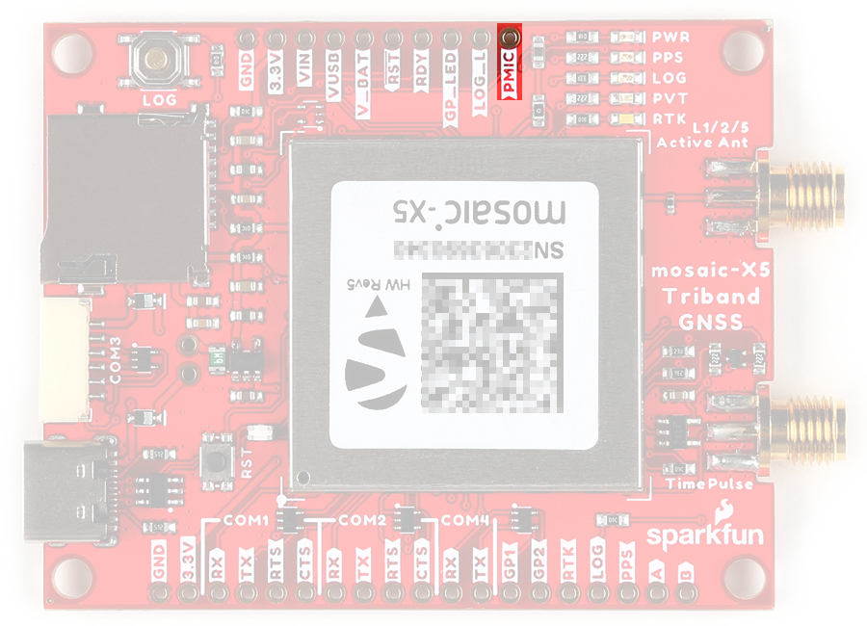
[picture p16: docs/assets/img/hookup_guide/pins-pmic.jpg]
		
		<figcaption markdown>The JST connector on the Tri-band GNSS RTK breakout board.</figcaption>
		</figure>

	</div>

	<div markdown>

	=== "`RDY` Pin"
		The `RDY` pin indicates the operational mode of the mosaic-X5 module *(see the [**Power Modes**](#power-modes) section)*. The level is high when module is operating, and low when in standby or reset.

		<figure markdown>
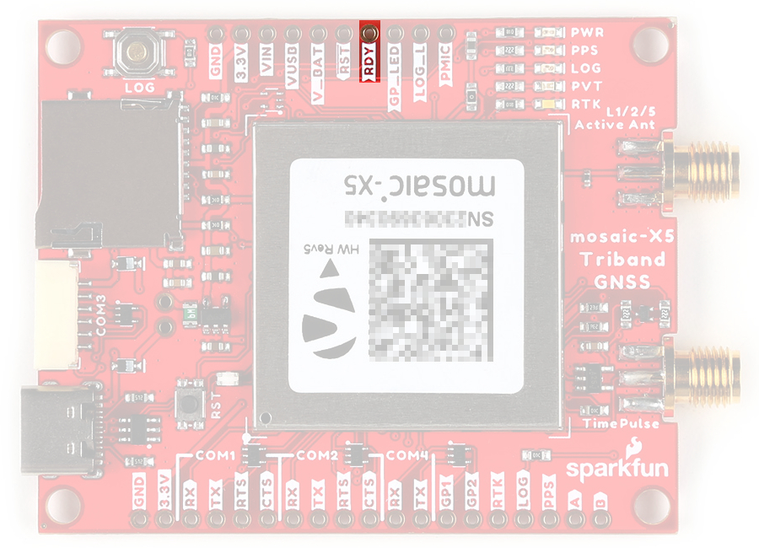
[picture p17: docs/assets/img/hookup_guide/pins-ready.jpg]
JST pins
		
		<figcaption markdown>The pin connections of the JST connector on the Tri-band GNSS RTK breakout board.</figcaption>
		</figure>

	</div>

	</div>

## SMA Connectors
There are two SMA connectors on the Tri-band GNSS RTK breakout board.

<div class="grid" markdown>

<div markdown>

=== "`L1/2/5`<br>`ActiveAnt`"

	The `L1/2/5` `ActiveAnt` connector is an input for the GPS antenna *(see the **[Antenna](#antenna)** section)*. The connector also provides active power at **5V** *(see the **[Jumpers](#jumpers)** section)*.

	<figure markdown>
	JST pins
	<figcaption markdown>The pin connections of the JST connector on the Tri-band GNSS RTK breakout board.</figcaption>
	</figure>

</div>

<div markdown>

=== "<br>`TimePulse`"

	The `TimePulse` connector provides a PPS output signal *(see the **[PPS Output](#pps-output)** section)*.

	<figure markdown>
	JST connector
	<figcaption markdown>The JST connector on the Tri-band GNSS RTK breakout board.</figcaption>
	</figure>

</div>

</div>

## JST Connector
The Tri-band GNSS RTK breakout features a 6-pin [JST GH connector](./assets/component_documentation/JST-GH_datasheet.pdf), which is polarized and locking. Users can access the `COM3` port of the mosaic-X5 module, through the JST connector with our [breadboard cable](https://www.sparkfun.com/breadboard-to-jst-ghr-06v-cable-6-pin-x-1-25mm-pitch.html)(1).
{ .annotate }

1. <div class="grid" markdown>

	<a href="https://www.sparkfun.com/breadboard-to-jst-ghr-06v-cable-6-pin-x-1-25mm-pitch.html">
	<figure markdown>
	Product Thumbnail
	</figure>

	---

	**Breadboard to JST-GHR-06V Cable - 6-Pin x 1.25mm Pitch**<br>
	CAB-18079</a>

	</div>

<div class="grid" markdown>

<figure markdown>
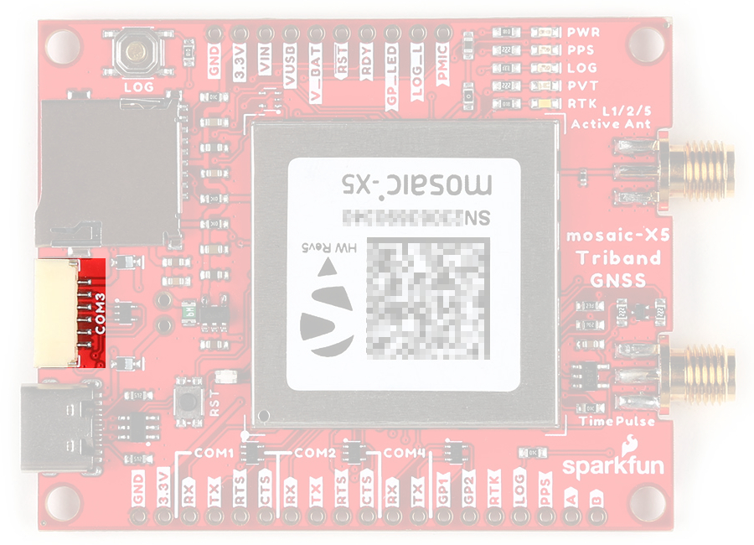
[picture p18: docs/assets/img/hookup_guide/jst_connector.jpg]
JST connector

<figcaption markdown>The JST connector on the Tri-band GNSS RTK breakout board.</figcaption>
</figure>

<figure markdown>
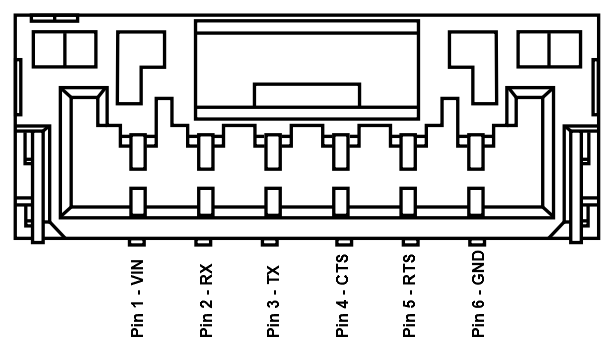
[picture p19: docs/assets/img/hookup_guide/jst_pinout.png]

<figcaption markdown>The pin connections of the JST connector on the Tri-band GNSS RTK breakout board.</figcaption>
</figure>

</div>

??? tip "Pin Connections"
	When connecting to the board's UART pins, the pins should be connected based upon the flow of their data. For example, when utilizing the [Telemetry Radio](https://www.sparkfun.com/sik-telemetry-radio-v3-915mhz-100mw.html) or the [LoRaSerial Kit](https://www.sparkfun.com/sparkfun-loraserial-kit-915mhz-enclosed.html):

	<figure markdown>
	Flow Control (https://docs.sparkfun.com/SparkFun_LoRaSerial/img/SAMD21%20Flow%20control.png "Click to enlarge")
	<figcaption markdown>Connection of the UART pins from the [LoRaSerial radio](https://www.sparkfun.com/sparkfun-loraserial-kit-915mhz-enclosed.html) to a host system, like the Tri-band GNSS RTK breakout board.</figcaption>
	</figure>

!!! warning "`V` Pin"
	By default, the power pin *(i.e. `V` or Pin 1)* of the JST connector is connected to `VIN` and configured as a power input. The board can be modified to configure that pin as a power output; however, the modification would bypass some of the safety features of the board *(see the [**Power**](#power) section)*.

## SD Card Slot
The &micro;SD card slot allows users easily log and store data on the board.

<figure markdown>
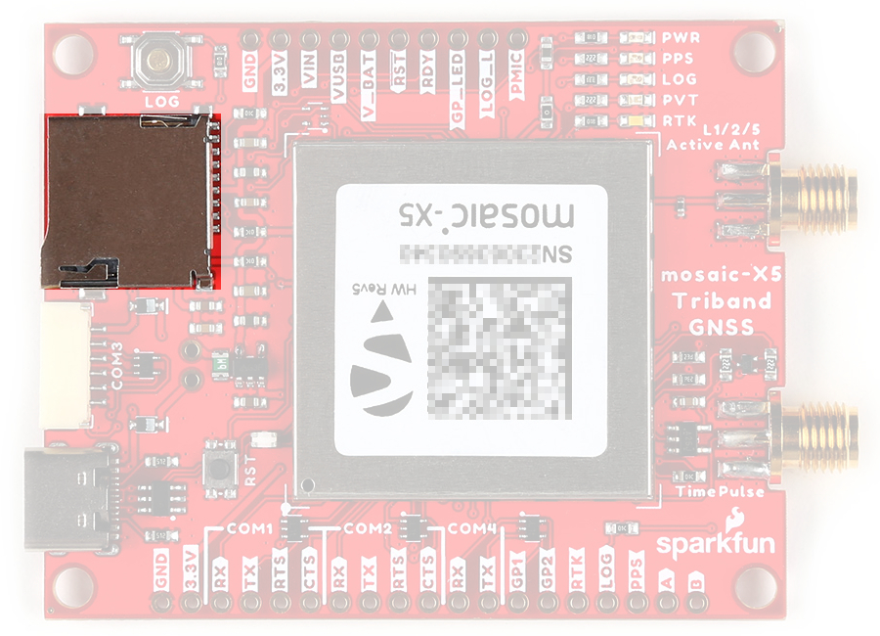
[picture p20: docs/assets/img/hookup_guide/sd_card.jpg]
SD card slot

<figcaption markdown>The &micro;SD card slot on the Tri-band GNSS RTK breakout board.</figcaption>
</figure>

!!! success "Initial Configuration"
	Before data logging can occur, it is necessary to create a *logging stream* from the **Logging** tab of the web interface or using the **RxTools** software suite. Streams can contain NMEA or SBF (Septentrio Binary Format) data; SBF can contain RTCM and/or RINEX. *(see the [Data Logging](../web_interface/#data-logging) section)*

!!! info "SD Card Specifications"
	The mosaic-X5 module is only compatible with SD cards of up to 32GB, formatted with a `FAT32` file system.

!!! info "Standby Mode"
	When Standby mode is initialized, the module terminates all running processes and unmounts the external SD card to avoid any log file corruption *(see the **[Power Modes](#power-modes)** section)*.

??? tip "++"LOG"++ Button"
	Data logging can be controlled with the ++"LOG"++ button *(see the [**Log Button**](#log-button) section)*.

	* Pressing the ++"LOG"++ button *(< 5s)* toggles data logging to the SD card on and off.
	* Holding the ++"LOG"++ button for more than 5 seconds *(> 5s)* and then releasing it, will force the board to:
		* Unmount the SD card if it was mounted
		* Mount the SD card if it was unmounted

??? tip "`LOG` Status LED"
	The SD card mount status is indicated on the `LOG` LED and`LOG_L` pin *(see the [**Status LEDs**](#status-leds) section)*.

	<article style="text-align: center;" markdown>

	| LED      | Pin    | Status                           |
	|:-------: | :----: | :------------------------------- |
	| Off      | Low    | SD card not present or unmounted |
	| On       | High   | SD card present and mounted      |
	| Blinking | Pulses | Data logging activity            |

	</article>

## Status LEDs
There are five status LEDs on the TMC6300 motor driver:

* `PWR` - Power *(Red)*
	* Turns on once power is supplied through the USB-C connector or `VIN` connections
* `PPS` - Pulse-Per-Second *(Yellow)*
	* Indicates when there is a pulse-per-second signal *(see the **[PPS Output](#pps-output)** section)*
* `LOG` - Data Logging *(Green)*
	* Indicates data logging activity *(see the **[SD Card Slot](#sd-card-slot)** section)*
		* Off - SD card not present or unmounted
		* On - SD card present and mounted
		* Blinking - Data logging activity
* `PVT` - Position/Velocity/Time Solution *(Blue)*
	* Turns on when a [PVT]("Position, Velocity, and Time") solution is available
* `RTK` - [RTK](https://en.wikipedia.org/wiki/Real-time_kinematic_positioning "Real-Time Kinematic") Mode *(White)*
	* Controlled through `GPIO 02`

<figure markdown>
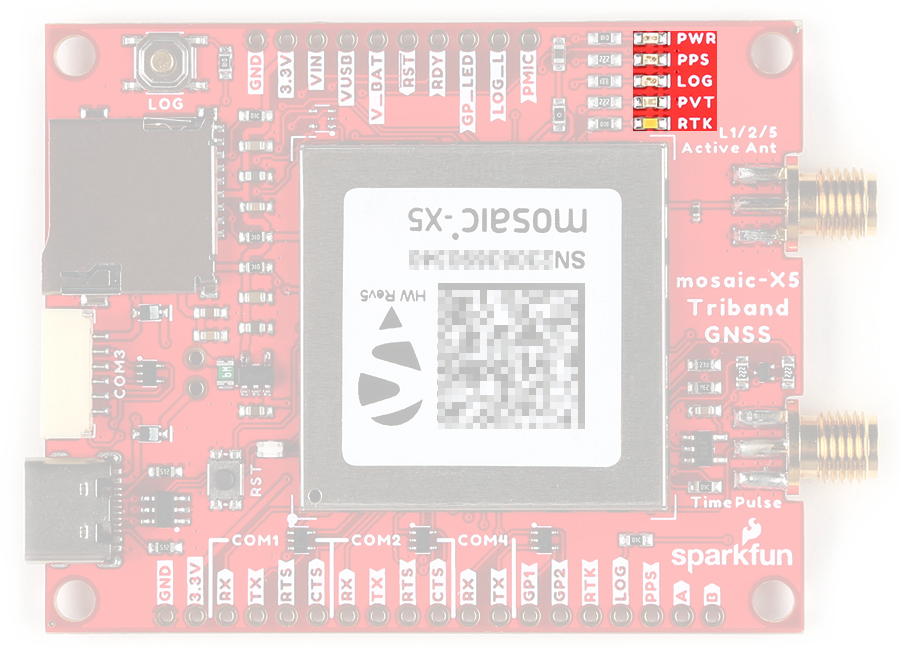
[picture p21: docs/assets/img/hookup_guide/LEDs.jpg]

<figcaption markdown>The status indicator LEDs on the Tri-band GNSS RTK breakout board.</figcaption>
</figure>

## Buttons
There are two buttons on Tri-band GNSS RTK breakout board: ++"RST"++ and ++"LOG"++ buttons.

<figure markdown>
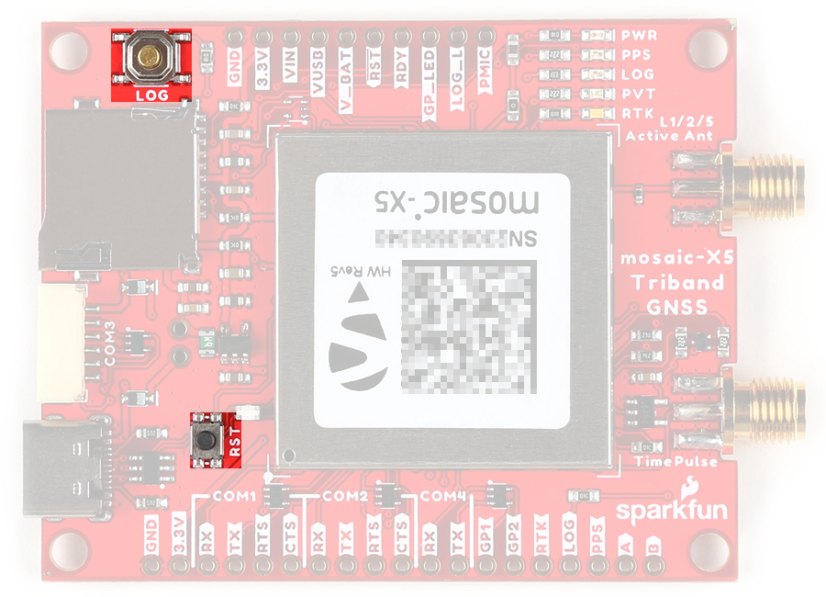
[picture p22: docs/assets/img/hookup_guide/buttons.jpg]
Buttons

<figcaption markdown>Buttons on the Tri-band GNSS RTK breakout board.</figcaption>
</figure>

### Reset Button
The ++"RST"++ *(reset)* button allows users to reset the mosaic-X5 module without unplugging the board.

<figure markdown>
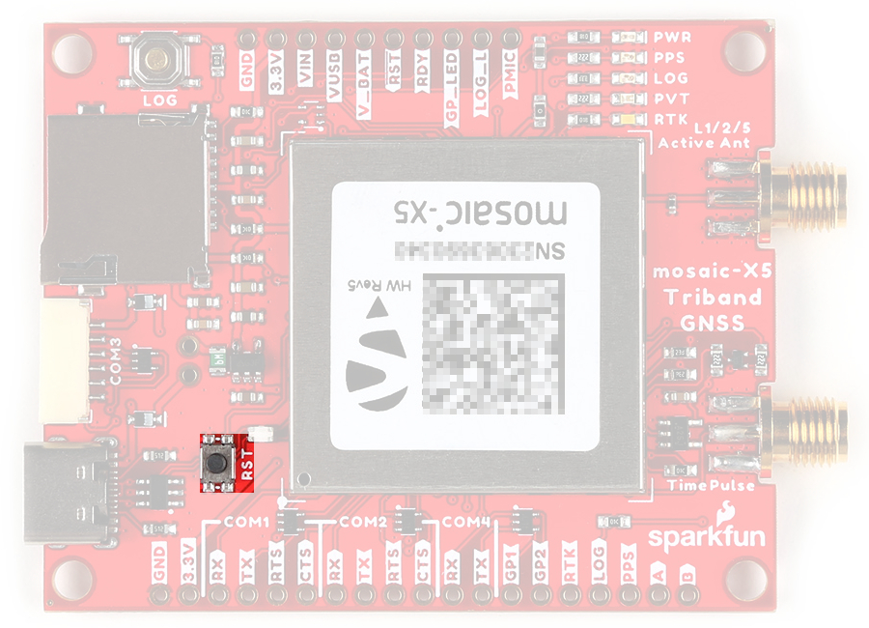
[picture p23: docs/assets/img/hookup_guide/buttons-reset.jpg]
Reset Button

<figcaption markdown>++"RST"++ button on the Tri-band GNSS RTK breakout board.</figcaption>
</figure>

### Log Button
The ++"LOG"++ button allows users easily control the data logging feature and the &micro;SD card, without having to configure the module.

* Pressing the ++"LOG"++ button *(< 5s)* toggles data logging to the SD card on and off.
* Holding the ++"LOG"++ button for more than 5 seconds *(> 5s)* and then releasing it, will force the board to:
	* Unmount the SD card if it was mounted
	* Mount the SD card if it was unmounted

??? tip "SD Card Status"
	The SD card mount status is indicated on the `LOG` LED and`LOG_L` pin *(see the [**Status LEDs**](#status-leds) section)*.

	<article style="text-align: center;" markdown>

	| LED      | Pin    | Status                           |
	|:-------: | :----: | :------------------------------- |
	| Off      | Low    | SD card not present or unmounted |
	| On       | High   | SD card present and mounted      |
	| Blinking | Pulses | Data logging activity            |

	</article>

<figure markdown>
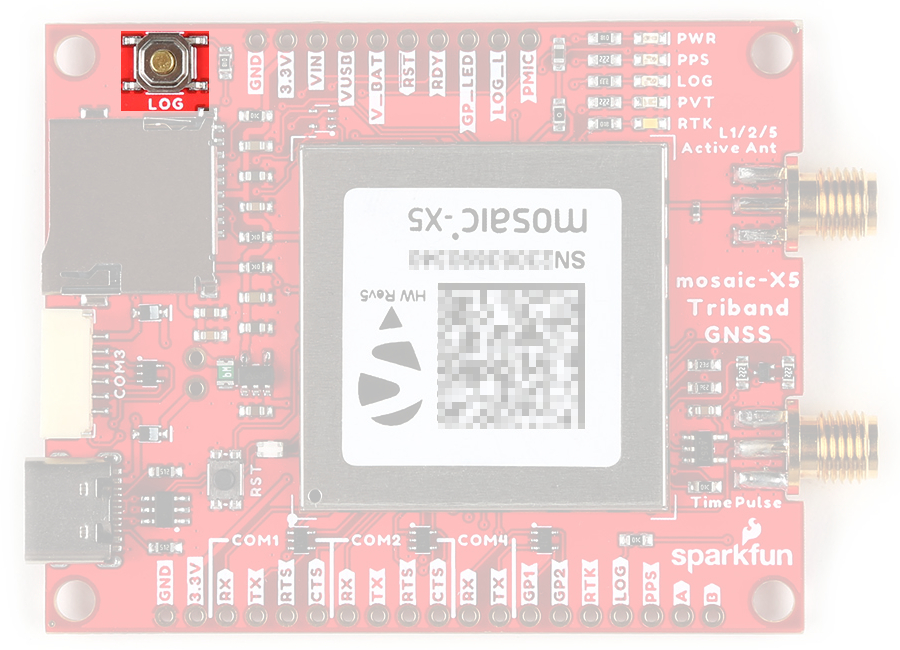
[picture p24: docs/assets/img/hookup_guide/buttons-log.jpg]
LOG button

<figcaption markdown>The ++"LOG"++ button on the Tri-band GNSS RTK breakout board.</figcaption>
</figure>

## Jumpers

??? note "Never modified a jumper before?"
	Check out our <a href="https://learn.sparkfun.com/tutorials/664">Jumper Pads and PCB Traces tutorial</a> for a quick introduction!

	<div class="grid cards" markdown align="center">

	-   <a href="https://learn.sparkfun.com/tutorials/664">
		<figure markdown>
		Tutorial thumbnail
		</figure>

		---
		
		**How to Work with Jumper Pads and PCB Traces**</a>

	</div>

There are nine jumpers on the back of the board that can be used to easily modify the hardware connections on the board.

<figure markdown>
Jumpers
<figcaption markdown>The jumpers on the back of the Tri-band GNSS RTK breakout board.</figcaption>
</figure>

=== "Power"

	**`MEAS`**

	:   This jumper can be cut and used to measure the current consumption of the board from the `VUSB` and/or `VIN` power supply inputs.

	**`V_BATT`**

	:   This jumper can be cut to disconnect the `VBATT` pin from the 3.3V output of the AP2112 LDO regulator.

		!!! info
			The `VBATT` pin is the power input for the mosaic-X5 module, when it is in **Standby** mode. Therefore, it also determines the power state of the mosaic-X5 module, when power is disconnected from the `VUSB` and `VIN` inputs.

			* By default, the jumper connected and the `VBATT` pin is powered at 3.3V. When the primary power is disconnected, the mosaic-X5 module will enter **Standby** mode.
			* If cut, the `VBATT` pin will be disconnected from the 3.3V output of the AP2112 LDO regulator. When the primary power is disconnected the `VUSB` and `VIN` inputs, the mosaic-X5 module will shut off.

	**`ANT_V`**

	:   This jumper can be modified to control the output voltage of the active antenna connection.

		!!! info
			By default, the middle pad is connected to the `5V` pad, which draws power from the `VUSB` and/or `VIN` inputs.

			Users can modify the jumper, to configure the output voltage of the active antenna connection to 3.3V, by cutting the jumper and connecting the middle pad to the `3V3` pad.

=== "LED Power"

	There are five jumpers that control power to the status LEDs on the board.

	!!! info
		By default, all the jumpers are connected, to power the status LEDs. For low power applications, users can cut the jumpers to disconnect power from each of the LEDs.

	* **`PWR_LED`** - This jumper can be cut to remove power from the red, power LED.
	* **`PPS_LED`** - This jumper can be cut to remove power from the yellow LED, which is connected to the [PPS](https://en.wikipedia.org/wiki/Pulse-per-second_signal "Pulse Per Second") signal.
	* **`LOG_LED`** - This jumper can be cut to remove power from the green LED, which indicates if data is being logged to the SD card.
	* **`GP_LED`** - This jumper can be cut to remove power from the blue LED that is connected to the general purpose pins.
	* **`RTK_LED`** - This jumper can be cut to remove power from the white LED, indicating RTK corrections.

=== "PPS Signal"

	The jumper next to the [`PPS`](https://en.wikipedia.org/wiki/Pulse-per-second_signal "Pulse Per Second") pin can be cut to disconnect the pulse per second signal from the [PTH](https://en.wikipedia.org/wiki/Through-hole_technology "Plated Through Holes") pin.

	!!! info
		By default, [PPS](https://en.wikipedia.org/wiki/Pulse-per-second_signal "Pulse Per Second") signal is connected to the `PPS` pin.

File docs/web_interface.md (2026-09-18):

---
icon: material/web
---

!!! danger "Important: Read Before Use!"
	!!! warning "ESD Sensitivity"
		The mosaic-X5 module is sensitive to [ESD](https://en.wikipedia.org/wiki/Electrostatic_discharge "Electrostatic Discharge"). Use a proper grounding system to make sure that the working surface and the components are at the same electric potential.

		??? info "ESD Precaution"
			As recommended by the manufacturer, we highly recommend that users take the necessary precautions to avoid damaging their module.

			- The Tri-band GNSS RTK breakout board features ESD protection on the USB-C connector and breakout's I/O:
				- USB data lines
				- I/O PTH pads
				- JST connector's pins
			- The mosaic-X5 module features internal ESD protection to the `ANT_1` antenna input.

			<div class="grid cards" markdown>

			<div markdown>

			<article class="video-500px" style="margin: auto;" markdown>
			<iframe src="https://www.youtube.com/embed/hrL5J6Q5gX8?si=jOPBat8rzMnL7Uz4&amp;start=26;&amp;end=35;" title="Septentrio: Getting Started Video (playback starts at ESD warning)" frameborder="0" allow="accelerometer; autoplay; clipboard-write; encrypted-media; gyroscope; picture-in-picture" allowfullscreen></iframe>
			</article>

			</div>

			-   <a href="https://www.sparkfun.com/ifixit-anti-static-wrist-strap.html">
				<figure markdown>
				Product Thumbnail
				</figure>		

				---

				**iFixit Anti-Static Wrist Strap**<br>
				TOL-25572</a>

			</div>

!!! note
	The mosaic-X5 module has numerous capabilities and a multitude of ways to configure and interface with them. Without regurgitating all the information that is documented in Septentrio's user manuals and videos, we have tried to highlight a good majority of the module's aspects.

	With that said, please feel free to [file an issue](../github/file_issue/#discrepancies-in-the-documentation) if you feel we have missed something that may benefit other users. *(Don't forget to provide us with a link to the documentation and what section the information is located.)*

## USB Driver
=== "Windows"
	If users haven't already installed the [RxTools software suite](https://www.septentrio.com/en/products/gps-gnss-receiver-software/rxtools) on their Windows PC, they will need to install the USB driver[^1] necessary to recognize and interact with the mosaic-X5 module through the USB interface.

	[^1]: On Linux, the standard Linux CDC-ACM driver is suitable.

	A Windows USB driver for the mosaic-X5 can be installed through two methods:

	<div class="annotate" markdown>

	* RxTools Software Suite (1)
	* mosaic-X5 GNSS Receiver Module (2)

	</div>

	1. The driver is installed during the installation process.
	2. The installation file for the Windows USB driver will be available from the mass-storage device when the board is initially connected to the computer.

	Once installed, the driver emulates two virtual serial ports, which can be accessed as standard `COM` ports to the receiver.

	??? tip "Terminal Emulators"
		Most [terminal emulation programs](https://learn.sparkfun.com/tutorials/112) will not make a distinction between virtual or native COM ports. However, for virtual serial ports, the port settings *(i.e. baudrate, etc.)* are not relevant and the default configuration be used in the terminal emulation program. However, for the physical/native `COM` ports will have the following default setting:

		* Baudrate: 115200bps
		* Data Bits: 8
		* Parity: No
		* Stop Bits: 1
		* Flow Control: None

	??? tip "Having Trouble?"
		For users who are having trouble installing the USB driver, we have an archived version *(v3.0.2[^2])* of the installation file. Users can download [**version 3.0.2**](./assets/component_documentation/driver/USB_driver_3_0_2_Installer.exe) of the driver, by clicking on the button below.

		[^2]:
			For the latest USB driver from Septentrio, please install their driver through the [RxTools software suite](../rxtools).<br>
			*This is driver version, was archived at the time that this guide was written. Please do not request for the file to be updated.*

		<article style="text-align: center;" markdown>
		[:octicons-download-16:{ .heart } Download USB Driver *(v3.0.2)*](./assets/component_documentation/driver/USB_driver_3_0_2_Installer.exe){ .md-button .md-button--primary target="blank" }
		</article>

=== "Linux"
	On Linux, the standard Linux CDC-ACM driver is suitable.

## Web Interface
With the USB driver installed, the mosaic-X5 module supports Ethernet-over-USB. The default IP address allocated for the Ethernet-over-USB interface is `192.168.3.1`. This IP can be entered in any browser to open a connection to the receiver's Web Interface as shown below.

<div class="grid" markdown>

<div markdown>

<figure markdown>
navigation tabs in the web interface
<figcaption markdown>All the drop-down navigation tabs in the web interface.</figcaption>
</figure>

</div>

<div markdown>

<article class="video-500px" style="margin: auto;" markdown>
<iframe src="https://www.youtube.com/embed/hrL5J6Q5gX8" title="Septentrio: Getting started with the Septentrio mosaic receiver module" frameborder="0" allow="accelerometer; autoplay; clipboard-write; encrypted-media; gyroscope; picture-in-picture" allowfullscreen></iframe>
</article>

</div>

</div>

!!! info
	The default IP address cannot be changed; this feature is only to be used when a single receiver is connected to your computer.

??? failure "Invalid IP Address *(WiFi Only)*"
	[One of the documentation pages on Septentrio's website](https://customersupport.septentrio.com/s/article/What-is-the-default-IP-address-to-connect-via-WiFi), specifies a default IP address of `192.168.20.1` for the web interface. However, that address is for a WiFi enabled product and cannot be used with this product.

### Update the Module's Firmware
!!! info "Latest Firmware"
	For the latest firmware released by Septentrio, please visit their [product page](https://www.septentrio.com/en/products/gps/gnss-receiver-modules/mosaic-x5#resources) for the mosaic-X5 module.

<div class="grid cards" markdown>

-   To check for the latest firmware published by Septentrio, please visit their [product page](https://www.septentrio.com/en/products/gps/gnss-receiver-modules/mosaic-x5#resources) for the mosaic-X5 module. Users can click on the button below, to be redirected to the latest firmware for the mosaic-X5.

	<article style="text-align: center;" markdown>
	[:septentrio-logo: Find the Latest Firmware](https://www.septentrio.com/en/products/gps/gnss-receiver-modules/mosaic-x5#resources){ .md-button .md-button--primary target="blank" }
	</article>

-   Currently, at the time that this board was released, the firmware for the mosaic-X5 module was *v4.15.0*[^4]. Users can download [**version 4.15.0**](./assets/component_documentation/firmware/mosaic-X5_fwp_4.15.0.zip) of the firmware, by clicking on the button below.

	[^4]:
		For the latest firmware published by Septentrio, please visit their [product page](https://www.septentrio.com/en/products/gps/gnss-receiver-modules/mosaic-x5#resources).<br>
		*This is firmware version, was archived at the time that this guide was written. Please do not request for the file to be updated; instead visit the product page to download the latest firmware.*

	<article style="text-align: center;" markdown>
	[:octicons-download-16:{ .heart } Download Firmware *(v4.15.0)*](./assets/component_documentation/firmware/mosaic-X5_fwp_4.15.0.zip){ .md-button .md-button--primary target="blank" }
	</article>

</div>

<div class="grid" markdown>

<div markdown>

<article class="video-500px" style="margin: auto;" markdown>
<iframe src="https://www.youtube.com/embed/bp8kNbzMl_c" title="Septentrio: How to upgrade the firmware of a Septentrio receiver" frameborder="0" allow="accelerometer; autoplay; clipboard-write; encrypted-media; gyroscope; picture-in-picture" allowfullscreen></iframe>
</article>

</div>

</div>

### GPS Data
Besides logging data with just the ++"LOG"++ button, users can configure/enable the output of data streams through the `COM` ports and data logging to the SD card through the web interface or RxTools software suite. The videos below illustrate how these features can be operated through the web interface.

<div class="grid" markdown>

<div markdown>

#### Data Logging

This video illustrates how users can configure the settings for data logging to the SD card.

<article class="video-500px" style="margin: auto;" markdown>
<iframe src="https://www.youtube.com/embed/Y9tvOebnoxk" title="Septentrio: How to log data to the SD card of the Septentrio mosaic receiver module" frameborder="0" allow="accelerometer; autoplay; clipboard-write; encrypted-media; gyroscope; picture-in-picture" allowfullscreen></iframe>
</article>

</div>

<div markdown>

#### Stream Data

This video illustrates how users can configure and enable a data stream through a TCP/IP connection.

<article class="video-500px" style="margin: auto;" markdown>
<iframe src="https://www.youtube.com/embed/ArtePkC58-o" title="Septentrio: How to output NMEA data on the Septentrio mosaic receiver module" frameborder="0" allow="accelerometer; autoplay; clipboard-write; encrypted-media; gyroscope; picture-in-picture" allowfullscreen></iframe>
</article>

</div>

</div>

??? info "Related Video"
	While this instructional video is for a different product line, the information, for the most part, is still relevant.

	<article class="video-500px" style="margin: auto;" markdown>
	<iframe src="https://www.youtube.com/embed/vU6iwJ-ac6A" title="Septentrio: How to log and stream data in NMEA OR SBF format for GNSS/INS receivers" frameborder="0" allow="accelerometer; autoplay; clipboard-write; encrypted-media; gyroscope; picture-in-picture" allowfullscreen></iframe>
	</article>

### RTK Corrections

<div class="grid" markdown>

<div markdown>
For users with multiple RTK capable GNSS receivers, users can configure their mosaic-X5 as a rover or base station.

<article class="video-500px" style="margin: auto;" markdown>
<iframe src="https://www.youtube.com/embed/UVUVXpA8rB4" title="Septentrio: How to receive corrections over an IP connection" frameborder="0" allow="accelerometer; autoplay; clipboard-write; encrypted-media; gyroscope; picture-in-picture" allowfullscreen></iframe>
</article>

</div>

<div markdown>
Without having to setup a personal base station, users can receive RTK corrections through the internet from 3rd-party services.

<article class="video-500px" style="margin: auto;" markdown>
<iframe src="https://www.youtube.com/embed/aAPoRpSR0tY" title="Septentrio: How to receive corrections via NTRIP on the Septentrio mosaic receiver module" frameborder="0" allow="accelerometer; autoplay; clipboard-write; encrypted-media; gyroscope; picture-in-picture" allowfullscreen></iframe>
</article>

</div>

</div>

#### Sharing Internet Access
By default, the mosaic-X5 GNSS receiver is not configured to access the internet through the USB interface. In order to receive or cast RTK corrections to/from a RTK network, such as NTRIP, users will need to enable capability.

* Users will need to use the web interface or RxTool software suite to enable the `Outgoing Internet Access Over USB` from the **Communication** > **USB** drop-down menu of the navigation tabs.
* This also requires users to allowing Internet sharing through on their computer as well. The procedure to do so depends on your operating system.
	* On a Windows PC, users must enable `Allow other network users to connect through this computer's Internet connection`, through the properties option of the network adapter with internet access.
	* On a Linux computer, users will likely need to configure a [network bridge](https://en.wikipedia.org/wiki/Network_bridge).

<div class="grid" markdown>

<div markdown>

<article class="video-500px" style="margin: auto;" markdown>
<iframe src="https://www.youtube.com/embed/bUt8cL9Ue1Y" title="Septentrio: Share internet connection with your GNSS / GPS receiver over USB" frameborder="0" allow="accelerometer; autoplay; clipboard-write; encrypted-media; gyroscope; picture-in-picture" allowfullscreen></iframe>
</article>

</div>

</div>

!!! info "New IP Address"
	Once a network bridge is enabled, the receiver will receive its IP address from the computer's DHCP server. Depending on the routing table, the module may no longer be reachable at its default IP address *(`192.168.3.1`)*.

### Enable the L5 Band
The mosaic-X5 is capable of utilizing the `L5` frequency band. However, within the GPS network, the `L5` service isn't completely operational and is currently marked as `unhealthy`. Users will need to configure the mosaic-X5 to enable the `L5` frequency band.

From the **Admin** tab, navigate through the drop-down menu to **Admin** > **Expert Control** > **Control Panel** > **Navigation** > **Receiver Operation** > **Masks**. Find the **Health Masks** box, and configure the `Discard unhealthy satellites` feature to `off` for both the **Tracking** and **PVT** options.

<figure markdown>
L5 Configuration - Step 1
<figcaption markdown>Configuring the `Discard unhealthy satellites` feature to `off`.</figcaption>
</figure>

!!! note
	Make sure to click ++"OK"++ button at the bottom of each page, to save and update the current configuration. Also, the save it to boot option will enable the configuration to persist through power cycles.

From the **Navigation** tab, navigate through the drop-down menu to **Navigation** > **Advance User Settings** > **Tracking** > **Signal Tracking**. Find the **Signal Tracking** box, then enable the `GPSL5` option.

<figure markdown>
L5 Configuration - Step 2
<figcaption markdown>Enabling signal tracking of the `L5` frequency band for the GPS constellation.</figcaption>
</figure>

??? tip "Click ++"OK"++"
	Don't forget to click ++"OK"++ button at the bottom of the page to save and update the current configuration.

Again in the **Navigation** tab, navigate to **Navigation** > **Advance User Settings** > **PVT** > **Signal Usage**. Enable the `GPSL5` option in both **Signals enabled in the PVT** and **Signals enabled in the navigation data decoder** sections.

<figure markdown>
L5 Configuration - Step 3
<figcaption markdown>Enabling signal usage of the `L5` frequency band for the GPS constellation.</figcaption>
</figure>

??? tip "Click ++"OK"++"
	Don't forget to click ++"OK"++ button at the bottom of the page to save and update the current configuration.

### More Videos
Users can find other instructional videos on [Septentrio's YouTube Channel](https://www.youtube.com/channel/UCrA9wMw1y1f-KeOnnhq4lrA/). Feel free to check out their playlists as well:

* [Getting Started](https://www.youtube.com/playlist?list=PLUxLg2_PvvdE0e2i2std6XyPnF6UdecAD)
* [How to *(Videos)* ](https://www.youtube.com/playlist?list=PLUxLg2_PvvdHZ73CnfhS7ZePIIIUR7bON)

??? note "Other Videos"

	<div class="grid" align="center" markdown>

	<div markdown>

	<article class="video-300px" style="margin: auto;" markdown>
	<iframe src="https://www.youtube.com/embed/j_zHbl99FsI" title="Septentrio: How to reset a receiver" frameborder="0" allow="accelerometer; autoplay; clipboard-write; encrypted-media; gyroscope; picture-in-picture" allowfullscreen></iframe>
	</article>

	</div>

	<div markdown>

	<article class="video-300px" style="margin: auto;" markdown>
	<iframe src="https://www.youtube.com/embed/D-iqzQnDbWw" title="Septentrio: How to copy the configuration from one to another receiver" frameborder="0" allow="accelerometer; autoplay; clipboard-write; encrypted-media; gyroscope; picture-in-picture" allowfullscreen></iframe>
	</article>

	</div>

	<div markdown>

	<article class="video-300px" style="margin: auto;" markdown>
	<iframe src="https://www.youtube.com/embed/2XizOW3Dzzk" title="Septentrio: How to monitor the CPU of a Septentrio receiver" frameborder="0" allow="accelerometer; autoplay; clipboard-write; encrypted-media; gyroscope; picture-in-picture" allowfullscreen></iframe>
	</article>

	</div>

	<div markdown>

	<article class="video-300px" style="margin: auto;" markdown>
	<iframe src="https://www.youtube.com/embed/9qN6b1JC3uE" title="Septentrio: How to generate and save a diagnostic report of a Septentrio receiver" frameborder="0" allow="accelerometer; autoplay; clipboard-write; encrypted-media; gyroscope; picture-in-picture" allowfullscreen></iframe>
	</article>

	</div>

	<div markdown>

	<article class="video-300px" style="margin: auto;" markdown>
	<iframe src="https://www.youtube.com/embed/WU8MYrDALsE" title="Septentrio: How to log SBF data for support for Septentrio's GNSS/ GPS receivers" frameborder="0" allow="accelerometer; autoplay; clipboard-write; encrypted-media; gyroscope; picture-in-picture" allowfullscreen></iframe>
	</article>

	</div>

	<div markdown>

	<article class="video-300px" style="margin: auto;" markdown>
	<iframe src="https://www.youtube.com/embed/lAP3TXz0ZL8" title="Septentrio: How to set up the PX4 Pixhawk and the Septentrio mosaic-go GNSS receiver Instruction video" frameborder="0" allow="accelerometer; autoplay; clipboard-write; encrypted-media; gyroscope; picture-in-picture" allowfullscreen></iframe>
	</article>

	</div>

	<div markdown>

	<article class="video-300px" style="margin: auto;" markdown>
	<iframe src="https://www.youtube.com/embed/OdGE7bXgJck" title="Septentrio: How to set up ArduPilot with Septentrio AsteRx GNSS receiver + RIB and Pixhawk" frameborder="0" allow="accelerometer; autoplay; clipboard-write; encrypted-media; gyroscope; picture-in-picture" allowfullscreen></iframe>
	</article>

	</div>

	<div markdown>

	<article class="video-300px" style="margin: auto;" markdown>
	<iframe src="https://www.youtube.com/embed/SzI0skGHKEw" title="Septentrio: Anti-jamming feature test-run" frameborder="0" allow="accelerometer; autoplay; clipboard-write; encrypted-media; gyroscope; picture-in-picture" allowfullscreen></iframe>
	</article>

	</div>

	<div markdown>

	<article class="video-300px" style="margin: auto;" markdown>
	<iframe src="https://www.youtube.com/embed/H6uVVEJ5U5w" title="Septentrio: How to activate Wideband Interference Mitigation" frameborder="0" allow="accelerometer; autoplay; clipboard-write; encrypted-media; gyroscope; picture-in-picture" allowfullscreen></iframe>
	</article>

	</div>

	<div markdown>

	<article class="video-300px" style="margin: auto;" markdown>
	<iframe src="https://www.youtube.com/embed/Ib_B_KcfmPs" title="Septentrio: How to use the spectrum plot" frameborder="0" allow="accelerometer; autoplay; clipboard-write; encrypted-media; gyroscope; picture-in-picture" allowfullscreen></iframe>
	</article>

	</div>

	</div>

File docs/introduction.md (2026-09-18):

---
icon: material/book-open-page-variant
---

!!! danger
	!!! warning "ESD Sensitivity"
		The mosaic-X5 module is sensitive to [ESD](https://en.wikipedia.org/wiki/Electrostatic_discharge "Electrostatic Discharge"). Use a proper grounding system to make sure that the working surface and the components are at the same electric potential.

		??? info "ESD Precaution"
			As recommended by the manufacturer, we highly recommend that users take the necessary precautions to avoid damaging their module.

			- The Tri-band GNSS RTK breakout board features ESD protection on the USB-C connector and breakout's I/O:
				- USB data lines
				- I/O PTH pads
				- JST connector's pins
			- The mosaic-X5 module features internal ESD protection to the `ANT_1` antenna input.

			<div class="grid cards" markdown>

			<div markdown>

			<article class="video-500px" style="margin: auto;" markdown>
			<iframe src="https://www.youtube.com/embed/hrL5J6Q5gX8?si=jOPBat8rzMnL7Uz4&amp;start=26;&amp;end=35;" title="Septentrio: Getting Started Video (playback starts at ESD warning)" frameborder="0" allow="accelerometer; autoplay; clipboard-write; encrypted-media; gyroscope; picture-in-picture" allowfullscreen></iframe>
			</article>

			</div>

			-   <a href="https://www.sparkfun.com/ifixit-anti-static-wrist-strap.html">
				<figure markdown>
				Product Thumbnail
				</figure>		

				---

				**iFixit Anti-Static Wrist Strap**<br>
				TOL-25572</a>

			</div>

	!!! warning "Active Antenna"
		Never inject an external DC voltage into the SMA connector for the GPS antenna, as it may damage the mosaic-X5 module. For instance, when using a splitter to distribute the antenna signal to several GNSS receivers, make sure that no more than one output of the splitter passes DC. Use [DC-blocks](https://en.wikipedia.org/wiki/DC_block) otherwise.

		??? info
			A 3 - 5.5V DC voltage can be applied to the main antenna from the `VANT` pin, obviating the need for an external antenna supply or [bias-tee](https://en.wikipedia.org/wiki/Bias_tee).

# Introduction
<div class="grid cards desc" markdown>

-   <a href="https://www.sparkfun.com/sparkfun-triband-gnss-rtk-breakout-mosaic-x5.html">
	**mosaic-X5 GNSS Breakout**<br>
	**SKU:** GPS-23088

	---

	<figure markdown>
	Product Thumbnail
	</figure></a>

	<article style="text-align: center;" markdown>

	<article class="video-500px" style="margin: auto;" markdown>
	<iframe src="https://www.youtube.com/embed/TSkIvtaVZc0" title="Product Showcase: SparkFun Tri-band GNSS RTK Breakout - mosaic-X5" frameborder="0" allow="accelerometer; autoplay; clipboard-write; encrypted-media; gyroscope; picture-in-picture" allowfullscreen></iframe>
	</article>
	QR code to play video

	[Purchase from SparkFun :fontawesome-solid-cart-plus:{ .heart }](https://www.sparkfun.com/sparkfun-triband-gnss-rtk-breakout-mosaic-x5.html){ .md-button .md-button--primary }
	QR code to product page
	</article>

-   At the heart of the Triband GNSS RTK Breakout is [Septentrio](https://www.septentrio.com/en)'s mosaic-X5, their most compact, ultra-low power, multi-band, multi-constellation, high-precision GNSS receiver. The receiver supports the GPS (USA), GLONASS (Russia), Beidou (China), Galileo (Europe), and NavIC (India) constellations, including regional systems *(i.e. SBAS and QZSS)*. With its [**Real Time Kinematics**](https://learn.sparkfun.com/tutorials/813) (RTK) capabilities, the module can achieve a horizontal accuracy of 6mm (~0.25in), vertical accuracy of 1cm (~0.4in) using RTK, and timing precision of 5ns (5 billionths of a second). It also features Septentrio's unique [AIM+ technology](https://www.septentrio.com/en/learn-more/advanced-positioning-technology/aim-jamming-protection) for interference mitigation and anti-spoofing, ensuring best-in-class reliability and scalable position accuracy.

	The mosaic-X5 is a sophisticated chip running an internal web server that can be accessed through the USB interface with a standard browser using a Linux/Windows computer. Septentrio also provides dozens of [video tutorials](https://www.youtube.com/@SeptentrioGNSS/videos) to guide users through the configuration settings of their GNSS receivers utilizing the web interface.

	Beyond the capabilities of the mosaic-X5 module, this board is seamless to operate with no programming skills required. Gone are the times when a microcontroller was required to interface with the GNSS receiver and log data to an SD card. The mosaic-X5 Triband GNSS RTK Breakout can start/stop logging data, without a single line of code, just utilizing a simple button.

	This breakout board is a perfect middle ground for users who would like to integrate the mosaic-X5 module into a project/enclosure with access to a majority of the module's available pins, similar to Septentrio's developer kit, but in the smaller form factor of their evaluation kit. Or maybe... you just needed a PPS output at a 3.3V logic level. *Please, check out the rest ouf our guide for more details on the capabilities of this board (that we couldn't fit in this product description).*

</div>

??? danger "Important: Read Before Use!"
	!!! warning "ESD Sensitivity"
		The mosaic-X5 module is sensitive to [ESD](https://en.wikipedia.org/wiki/Electrostatic_discharge "Electrostatic Discharge"). Use a proper grounding system to make sure that the working surface and the components are at the same electric potential.

		??? info "ESD Precaution"
			As recommended by the manufacturer, we highly recommend that users take the necessary precautions to avoid damaging their module.

			- The Tri-band GNSS RTK breakout board features ESD protection on the USB-C connector and breakout's I/O:
				- USB data lines
				- I/O PTH pads
				- JST connector's pins
			- The mosaic-X5 module features internal ESD protection to the `ANT_1` antenna input.

			<div class="grid cards" markdown>

			<div markdown>

			<article class="video-500px" style="margin: auto;" markdown>
			<iframe src="https://www.youtube.com/embed/hrL5J6Q5gX8?si=jOPBat8rzMnL7Uz4&amp;start=26;&amp;end=35;" title="Septentrio: Getting Started Video (playback starts at ESD warning)" frameborder="0" allow="accelerometer; autoplay; clipboard-write; encrypted-media; gyroscope; picture-in-picture" allowfullscreen></iframe>
			</article>

			</div>

			-   <a href="https://www.sparkfun.com/ifixit-anti-static-wrist-strap.html">
				<figure markdown>
				Product Thumbnail
				</figure>		

				---

				**iFixit Anti-Static Wrist Strap**<br>
				TOL-25572</a>

			</div>

	!!! warning "Active Antenna"
		Never inject an external DC voltage into the SMA connector for the GPS antenna, as it may damage the mosaic-X5 module. For instance, when using a splitter to distribute the antenna signal to several GNSS receivers, make sure that no more than one output of the splitter passes DC. Use [DC-blocks](https://en.wikipedia.org/wiki/DC_block) otherwise.

		??? info
			A 3 - 5.5V DC voltage can be applied to the main antenna from the `VANT` pin, obviating the need for an external antenna supply or [bias-tee](https://en.wikipedia.org/wiki/Bias_tee).

??? question "Product Comparison"
	Below is a simple comparison table between our breakout board and Septentrio's development and evaluation kits:

	<div class="annotate" markdown align="center">
	<table markdown>
	<tr markdown>
	<td></td>
	<th markdown style="text-align:center">
		mosaic-X5 Development Kit<br>
		<hr>
		<figure markdown>
		Product Thumbnail
		</figure>
	</th>
	<th markdown style="text-align:center">
		mosaic-go Evaluation Kit<br>
		<hr>
		<figure markdown>
		Product Thumbnail
		</figure>
	</th>
	<th markdown style="text-align:center">
		mosaic-X5 GNSS Breakout<br>
		<hr>
		<figure markdown>
		Product Thumbnail
		</figure>
	</th>
	<th markdown style="text-align:center">
		RTK mosaic-X5<br>
		<hr>
		<figure markdown>
		Product Thumbnail
		</figure>
	</th>
	<th markdown style="text-align:center">
		mosaic-X5 Flex Module<br>
		<hr>
		<figure markdown>
		Product Thumbnail
		</figure>
	</th>
	<th markdown style="text-align:center">
		SparkPNT RTK Facet mosaic<br>
		<hr>
		<figure markdown>
		Product Thumbnail
		</figure>
	</th>
	</tr>
	<tr>
		<td style="vertical-align:middle;">GNSS Antenna</td>
		<td style="text-align:center; vertical-align:middle;">Dual</td>
		<td style="text-align:center">
			Single (mosaic-X5)<br>
			Dual (mosaic-H)
		</td>
		<td style="text-align:center; vertical-align:middle;">Single</td>
		<td style="text-align:center; vertical-align:middle;">Single</td>
		<td style="text-align:center; vertical-align:middle;">Single</td>
		<td style="text-align:center; vertical-align:middle;">Integrated</td>
	</tr>
	<tr>
		<td>USB Connector</td>
		<td style="text-align:center">micro-B</td>
		<td style="text-align:center">micro-B</td>
		<td style="text-align:center">Type-C</td>
		<td style="text-align:center">Type-C</td>
		<td style="text-align:center">N/A*</td>
		<td style="text-align:center">Type-C</td>
	</tr>
	<tr>
		<td style="vertical-align:middle;">Ethernet</td>
		<td style="text-align:center; vertical-align:middle;">
			Yes<br>
			<i>10/100 Base-T</i>
		</td>
		<td style="text-align:center; vertical-align:middle;">No</td>
		<td style="text-align:center; vertical-align:middle;">No</td>
		<td style="text-align:center">
			Yes<br>
			<i>10/100 Base-T</i>
		</td>
		<td style="text-align:center; vertical-align:middle;">2x10 Header*</td>
		<td style="text-align:center; vertical-align:middle;">No</td>
	</tr>
	<tr>
		<td style="vertical-align:middle;">WiFi</td>
		<td style="text-align:center; vertical-align:middle;">No</td>
		<td style="text-align:center; vertical-align:middle;">No</td>
		<td style="text-align:center; vertical-align:middle;">No</td>
		<td style="text-align:center">
			Yes - Network Bridge<br>
			<i>10 Base-T</i>
		</td>
		<td style="text-align:center; vertical-align:middle;">No</td>
		<td style="text-align:center">
			Yes - Network Bridge<br>
			<i>10 Base-T</i>
		</td>
	</tr>
	<tr>
		<td style="vertical-align:middle;">COM Ports</td>
		<td style="text-align:center">4</td>
		<td style="text-align:center">2</td>
		<td style="text-align:center">4</td>
		<td style="text-align:center">
			1 - mosaic-X5<br>
			1 - ESP32
		</td>
		<td style="text-align:center">4</td>
		<td style="text-align:center">
			1 - mosaic-X5<br>
			1 - ESP32
		</td>
	</tr>
	<tr>
		<td>&micro;SD Card Slot</td>
		<td style="text-align:center">Yes</td>
		<td style="text-align:center">Yes</td>
		<td style="text-align:center">Yes</td>
		<td style="text-align:center">Yes</td>
		<td style="text-align:center">2x10 Header*</td>
		<td style="text-align:center">Yes</td>
	</tr>
	<tr>
		<td style="vertical-align:middle;">Reset/Log Buttons</td>
		<td style="text-align:center; vertical-align:middle;">Yes</td>
		<td style="text-align:center; vertical-align:middle;">No*</td>
		<td style="text-align:center; vertical-align:middle;">Yes</td>
		<td style="text-align:center; vertical-align:middle;">Yes</td>
		<td style="text-align:center; vertical-align:middle;">No</td>
		<td style="text-align:center; vertical-align:middle;">Yes</td>
	</tr>
	<tr>
		<td style="vertical-align:middle;">Logic-Level</td>
		<td style="text-align:center">
			1.8V<br>
			3.3V
		</td>
		<td style="text-align:center; vertical-align:middle;">3.3V</td>
		<td style="text-align:center; vertical-align:middle;">3.3V</td>
		<td style="text-align:center">
			3.3V<br>
			5V
		</td>
		<td style="text-align:center; vertical-align:middle;">3.3V</td>
		<td style="text-align:center; vertical-align:middle;">3.3V</td>
	</tr>
	<tr>
		<td>PPS Signal</td>
		<td style="text-align:center">Header Pin</td>
		<td style="text-align:center">6-Pin JST Connector</td>
		<td style="text-align:center">SMA Connector</td>
		<td style="text-align:center">Screw Terminal</td>
		<td style="text-align:center">2x10 Header*</td>
		<td style="text-align:center">No</td>
	</tr>
	<tr>
		<td>Enclosure Material</td>
		<td style="text-align:center; vertical-align:middle;">N/A</td>
		<td style="text-align:center; vertical-align:middle;">Metal</td>
		<td style="text-align:center; vertical-align:middle;">N/A</td>
		<td style="text-align:center; vertical-align:middle;">Aluminum</td>
		<td style="text-align:center; vertical-align:middle;">N/A</td>
		<td style="text-align:center; vertical-align:middle;">Plastic</td>
	</tr>
	<tr>
		<td style="vertical-align:middle;">Dimensions</td>
		<td style="text-align:center; vertical-align:middle;">N/A</td>
		<td style="text-align:center; vertical-align:middle;">71 x 59 x 12mm ± 1mm</td>
		<td style="text-align:center; vertical-align:middle;">70.9 x 50.8 x 8mm</td>
		<td style="text-align:center">
			180.6 x 101.8 x 41mm<br>
			<i>Enclosure Only</i>
		</td>
		<td style="text-align:center; vertical-align:middle;"></td>
		<td style="text-align:center; vertical-align:middle;"></td>
	</tr>
	<tr>
		<td style="vertical-align:middle;">Weight</td>
		<td style="text-align:center; vertical-align:middle;">N/A</td>
		<td style="text-align:center; vertical-align:middle;">58g  ± 1g</td>
		<td style="text-align:center; vertical-align:middle;">22.6g</td>
		<td style="text-align:center">
			415.15g<br>
			<i>Enclosure Only</i>
		</td>
		<td style="text-align:center; vertical-align:middle;"></td>
		<td style="text-align:center; vertical-align:middle;"></td>
	</tr>
	
	</table>
	
	</div>

	!!! note "mosaic-go Evaluation Kit"
		The reset pin is exposed on 4-pin JST connector and the log pin is connected to the latch pin of the SD card slot.

	!!! note "mosaic-5 Flex Module"
		SparkPNT GNSS Flex modules are modular, *plug-in* boards that utilize a *carrier* board to access the pins of the GNSS Flex headers.

## :fontawesome-solid-list-check:&nbsp;Required Materials
To get started, users will need a few items. Now some users may already have a few of these items, feel free to modify your cart accordingly.

<div class="annotate" markdown>

* Computer with an operating system (OS) that is compatible with all the software installation requirements (1)

	!!! warning "Software Compatibility"
		The [RxTools software suite](https://www.septentrio.com/en/products/gps-gnss-receiver-software/rxtools) from Septentrio, automatically installs the required USB-over-Ethernet driver and provides users with an interface for the receiver configuration, monitoring, data logging, and analysis. However, it only appears to be available for Windows and Linux operating systems.

* [USB 3.1 Cable A to C - 3 Foot](https://www.sparkfun.com/usb-3-1-cable-a-to-c-3-foot.html) - Used to interface with the mosaic-X5 GNSS Breakout (2)
* [SparkFun Tri-band GNSS RTK Breakout - mosaic-X5](https://www.sparkfun.com/sparkfun-triband-gnss-rtk-breakout-mosaic-x5.html) (3)
* [GNSS Multi-Band L1/L2/L5 Surveying Antenna](https://www.sparkfun.com/gnss-multi-band-l1-l2-l5-surveying-antenna-tnc-spk6618h.html)
	* [SMA Male to TNC Male Cable](https://www.sparkfun.com/reinforced-interface-cable-sma-male-to-tnc-male-10m.html)
	* [Antenna Mount](https://www.sparkfun.com/gnss-magnetic-antenna-mount-5-8-11-tpi.html)

</div>

1. A list of the compatible GNSS receiver software, is provided on the [Septentrio website](https://www.septentrio.com/en/products/gps-gnss-receiver-software).
2. If your computer doesn't have a USB-A slot, then choose an appropriate cable or adapter.
3. For the best performance, use a compatible L1/L2/L5 GNSS antenna.

<div class="grid cards" markdown>

-   <a href="https://www.sparkfun.com/usb-3-1-cable-a-to-c-3-foot.html">
	<figure markdown>
	USB 3.1 Cable A to C - 3 Foot
	</figure>

	---

	**USB 3.1 Cable A to C - 3 Foot**<br>
	CAB-14743</a>

-   <a href="https://www.sparkfun.com/sparkfun-triband-gnss-rtk-breakout-mosaic-x5.html">
	<figure markdown>
	Product Thumbnail
	</figure>

	---

	**mosaic-X5 (Tri-band + RTK) GNSS Breakout**<br>
	GPS-23088</a>

-   <a href="https://www.sparkfun.com/gnss-multi-band-l1-l2-l5-surveying-antenna-tnc-spk6618h.html">
	<figure markdown>
	Product Thumbnail
	</figure>		

	---

	**GNSS Multi-Band L1/L2/L5 Surveying Antenna - TNC (SPK6618H)**<br>
	GPS-21801</a>

-   <a href="https://www.sparkfun.com/reinforced-interface-cable-sma-male-to-tnc-male-10m.html">
	<figure markdown>
	Product Thumbnail
	</figure>

	---

	**Reinforced Interface Cable - SMA Male to TNC Male (10m)**<br>
	CAB-21740</a>

-   <a href="https://www.sparkfun.com/gnss-magnetic-antenna-mount-5-8-11-tpi.html">
	<figure markdown>
	Product Thumbnail
	</figure>		

	---

	**GNSS Magnetic Antenna Mount - 5/8" 11-TPI**<br>
	PRT-21257</a>

</div>

!!! danger "ESD Protection"
	The Septentrio mosaic-X5 module is sensitive to [ESD](https://en.wikipedia.org/wiki/Electrostatic_discharge "Electrostatic Discharge"). Use a proper grounding system to make sure that the working surface and the components are at the same electric potential.

	<div class="grid cards" markdown>

	<div markdown>

	<article class="video-300px" style="margin: auto;" markdown>
	<iframe src="https://www.youtube.com/embed/hrL5J6Q5gX8?si=jOPBat8rzMnL7Uz4&amp;start=26;&amp;end=35;" title="Septentrio: Getting Started Video (playback starts at ESD warning)" frameborder="0" allow="accelerometer; autoplay; clipboard-write; encrypted-media; gyroscope; picture-in-picture" allowfullscreen></iframe>
	</article>

	!!! warning
		As recommended by the manufacturer, we highly recommend that users take the necessary precautions to avoid damaging their module.

	</div>

	-   <a href="https://www.sparkfun.com/ifixit-anti-static-wrist-strap.html">
		<figure markdown>
		Product Thumbnail
		</figure>		

		---

		**iFixit Anti-Static Wrist Strap**<br>
		TOL-25572</a>

	</div>

??? note "Antennas & Accessories"
	For the best performance, we recommend users choose a compatible L1/L2/L5 (tri-band) GNSS antenna and utilize a low-loss cable. For additional options, please check out the [GPS Antenna](https://www.sparkfun.com/categories/18) category of our product catalog.

	=== "L5 Antennas"
	
		<div class="grid cards" markdown>

		-   <a href="https://www.sparkfun.com/gnss-multi-band-l1-l2-l5-surveying-antenna-tnc-spk6618h.html">
			<figure markdown>
			Product Thumbnail
			</figure>		

			---

			**GNSS Multi-Band L1/L2/L5 Surveying Antenna - TNC (SPK6618H)**<br>
			GPS-21801</a>

			??? info "Adapter Cable"
				For our TNC antennas, users will need a TNC to SMA adapter cable.
		
				<div class="grid cards" markdown>
		
				-   <a href="https://www.sparkfun.com/reinforced-interface-cable-sma-male-to-tnc-male-300mm.html">
					<figure markdown>
					Product Thumbnail
					</figure>
		
					---
		
					**Reinforced Interface Cable - SMA Male to TNC Male (300mm)**<br>
					CAB-21739</a>
		
				-   <a href="https://www.sparkfun.com/reinforced-interface-cable-sma-male-to-tnc-male-10m.html">
					<figure markdown>
					Product Thumbnail
					</figure>
		
					---
		
					**Reinforced Interface Cable - SMA Male to TNC Male (10m)**<br>
					CAB-21740</a>
		
				</div>

		-   <a href="https://www.sparkfun.com/gnss-multi-band-magnetic-mount-antenna-5m-sma.html">
			<figure markdown>
			Product Thumbnail
			</figure>

			---

			**GNSS Multi-Band Magnetic Mount Antenna - 5m (SMA)**<br>
			GPS-15192</a>

			??? info "Kit Version"
				We also offer this product in a kit, which includes a ground plate and USB-C cable.

				<div class="grid cards col-1" markdown>

				-   <a href="https://www.sparkfun.com/sparkfun-gnss-rtk-accessory-kit.html">
					<figure markdown>
					Product Thumbnail
					</figure>		

					---

					**SparkFun GNSS-RTK Accessory Kit**<br>
					KIT-18293</a>

				</div>

		-   <a href="https://www.sparkfun.com/magmax2-active-multiband-gnss-magnetic-mount-antenna-aa-200.html">
			<figure markdown>
			Product Thumbnail
			</figure>

			---

			**MagmaX2 Active Multiband GNSS Magnetic Mount Antenna - AA.200**<br>
			GPS-17108</a>

		</div>

	=== "Mounting Hardware"

		<div class="grid cards" markdown>

		-   <a href="https://www.sparkfun.com/gnss-magnetic-antenna-mount-5-8-11-tpi.html">
			<figure markdown>
			Product Thumbnail
			</figure>		

			---

			**GNSS Magnetic Antenna Mount - 5/8" 11-TPI**<br>
			PRT-21257</a>

			!!! info "5/8"-11 TPI"
				This product is meant to be used with our surveying antennas. To mount those antennas to a camera tripod, check out our [tripod adapter](https://www.sparkfun.com/antenna-thread-adapter-1-4in-to-5-8in.html).

		-   <a href="https://www.sparkfun.com/gnss-antenna-mounting-hardware-kit.html">
			<figure markdown>
			Product Thumbnail
			</figure>		

			---

			**GNSS Antenna Mounting Hardware Kit**<br>
			KIT-22197</a>

			!!! info "5/8"-11 TPI"
				This product is meant to be used with our surveying antennas. To mount those antennas to a camera tripod, check out our [tripod adapter](https://www.sparkfun.com/antenna-thread-adapter-1-4in-to-5-8in.html).

		-   <a href="https://www.sparkfun.com/gps-antenna-ground-plate.html">
			<figure markdown>
			Product Thumbnail
			</figure>		

			---

			**GPS Antenna Ground Plate**<br>
			GPS-17519</a>

			!!! info "1/4"-20 TPI"
				This product is meant to be used with our magnetic antennas and a camera tripod with a standard ¼"-20 UNC camera mounting screw.

		</div>

??? note "Data Logging"
	The Septentrio mosaic-X5 module is capable of logging data to an &micro;SD card. Please check out the [memory cards and accessories](https://www.sparkfun.com/categories/351) in our product catalog.

	<div class="grid cards" markdown>

	-   <a href="https://www.sparkfun.com/microsd-card-1gb-class-4.html">
		<figure markdown>
		Product Thumbnail
		</figure>		

		---

		**microSD Card - 1GB (Class 4)**<br>
		COM-15107</a>

	-   <a href="https://www.sparkfun.com/microsd-card-adapter-usb-a.html">
		<figure markdown>
		Product Thumbnail
		</figure>		

		---

		**MicroSD Card Adapter - USB A**<br>
		COM-26322</a>

	</div>

??? note "JST Cable & Transceivers"
	In remote applications, users may need to utilize one of our radio transceivers for RTK correction data. Users may also find our breadboard cable convenient for connecting your module to a development board.

	<div class="grid cards" markdown>

	-   <a href="https://www.sparkfun.com/sik-telemetry-radio-v3-915mhz-100mw.html">
		<figure markdown>
		Product Thumbnail
		</figure>

		---

		**SiK Telemetry Radio V3 - 915MHz, 100mW**<br>
		WRL-19032</a>

	-   <a href="https://www.sparkfun.com/sparkfun-loraserial-kit-915mhz-enclosed.html">
		<figure markdown>
		Product Thumbnail
		</figure>

		---

		**SparkFun LoRaSerial Kit - 915MHz (Enclosed)**<br>
		WRL-20029</a>

	-   <a href="https://www.sparkfun.com/breadboard-to-jst-ghr-06v-cable-6-pin-x-1-25mm-pitch.html">
		<figure markdown>
		Product Thumbnail
		</figure>

		---

		**Breadboard to JST-GHR-06V Cable - 6-Pin x 1.25mm Pitch**<br>
		CAB-18079</a>

	-   <a href="https://www.sparkfun.com/breadboard-mini-modular-red.html">
		<figure markdown>
		Product Thumbnail
		</figure>

		---

		**Breadboard - Mini Modular (Red)**<br>
		PRT-12044</a>

	</div>
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

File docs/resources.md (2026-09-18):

## Product Resources

* :sfe: [Product Page](https://www.sparkfun.com/sparkfun-triband-gnss-rtk-breakout-mosaic-x5.html)
* :material-folder-cog: Design Files:
	* :fontawesome-solid-file-pdf: [Board Dimensions](./assets/board_files/dimensions.pdf)
	* :fontawesome-solid-file-pdf: [Schematic](./assets/board_files/schematic.pdf)
	* :material-folder-zip: [Eagle Files](./assets/board_files/eagle_files.zip)
* Component Documentation
	* :fontawesome-solid-file-pdf: [mosaic-X5 Datasheet](./assets/component_documentation/mosaic_hardware_manual_v1.11.0.pdf)
		* :fontawesome-solid-file-pdf: [mosaic-X5 Brochure](./assets/component_documentation/Septentrio_mosaic-X5_LR.pdf)
		* :fontawesome-solid-file-pdf: [Firmware Manual *(v4.15.0)*](./assets/component_documentation/firmware/mosaic-X5_Firmware_v4.15.0_Reference_Guide.pdf)
	* :fontawesome-solid-file-pdf: [JST-GH Connector Datasheet](./assets/component_documentation/JST-GH_datasheet.pdf)
	* :fontawesome-solid-file-pdf: [AP2112 Datasheet](./assets/component_documentation/AP2112.pdf)
	* :fontawesome-solid-file-pdf: [PESDxL4 Datasheet](./assets/component_documentation/PESDXL4UF_G_W.pdf)
	* :fontawesome-solid-file-pdf: [RFCMF1220100M4T Datasheet](./assets/component_documentation/watcs00941_1-2271498.pdf)
* :material-youtube: [SFE Product Showcase](https://youtu.be/TSkIvtaVZc0)
* :material-github: [Hardware Repo](https://github.com/sparkfun/SparkFun_GNSS_mosaic-X5)

### Additional Resources

* :material-account-supervisor: [SparkFun Technical Assistance](https://www.sparkfun.com/technical_assistance)

## 🏭&nbsp;Manufacturer's Resources
Septentrio also provides great resources for the mossaic-X5 GNSS receiver module:

* [mosaic-X5 Product Page](https://www.septentrio.com/en/products/gps/gnss-receiver-modules/mosaic-x5)
* :material-youtube: [Septentrio YouTube Channel](https://www.youtube.com/channel/UCrA9wMw1y1f-KeOnnhq4lrA/feed)
* [Support Page](https://www.septentrio.com/en/support)
	* :material-head-question: [Technical Support Portal](https://customersupport.septentrio.com/s/)
		* :material-head-lightbulb: [Knowledge Base](https://customersupport.septentrio.com/s/topiccatalog)
	* [Learn More](https://www.septentrio.com/en/learn-more)
		* [Webinars](https://www.septentrio.com/en/learn-more/webinars)
		* [Technical Papers](https://www.septentrio.com/en/learn-more/technical-papers)
		* [Insights](https://www.septentrio.com/en/learn-more/insights) *(Case Studies and Technical Articles)*
		* [Community](https://www.septentrio.com/en/learn-more/community)
		* [Agnostic Corrections Program](https://www.septentrio.com/en/products/correction-services/precise-point-positioning-services-land/agnostic-corrections-program-gnss-correction-services)
* [JammerTest 2023 - Anti-Jamming and Anti-Spoofing Performance](https://www.septentrio.com/en/learn-more/insights/most-resilient-gnss-receiver-results-jammertest-norway)

<article style="text-align: center;" markdown>
QR code to the hookup guide
</article>

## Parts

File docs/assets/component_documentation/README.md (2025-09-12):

component_documentation directory
====================

A copy of the datasheets, user manuals, programming guides, etc. of the major electrical components on the board.

* [APA2112 Datasheet](AP2112.pdf) (PDF)
* [mosaic-X5 Datasheet](mosaic_hardware_manual_v1.11.0.pdf) (PDF)
	* [Brochure](Septentrio_mosaic-X5_LR.pdf) (PDF)
	* [Schematic: Development Kit](mowi_schematic_MERGED.pdf) (PDF)
* [PESDXL4UG Datasheet](PESDXL4UF_G_W.pdf) (PDF)
* [RFCMF1220100M4T Datasheet](watcs00941_1-2271498.pdf) (PDF)

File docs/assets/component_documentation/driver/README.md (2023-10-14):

driver directory
====================

A copy of the USB driver from the module.

* [USB Driver](USB_driver_3_0_2_Installer.exe) (EXE)

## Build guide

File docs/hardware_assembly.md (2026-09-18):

---
icon: material/tools
---

!!! danger "Important: Read Before Use!"
	!!! warning "ESD Sensitivity"
		The mosaic-X5 module is sensitive to [ESD](https://en.wikipedia.org/wiki/Electrostatic_discharge "Electrostatic Discharge"). Use a proper grounding system to make sure that the working surface and the components are at the same electric potential.

		??? info "ESD Precaution"
			As recommended by the manufacturer, we highly recommend that users take the necessary precautions to avoid damaging their module.

			- The Tri-band GNSS RTK breakout board features ESD protection on the USB-C connector and breakout's I/O:
				- USB data lines
				- I/O PTH pads
				- JST connector's pins
			- The mosaic-X5 module features internal ESD protection to the `ANT_1` antenna input.

			<div class="grid cards" markdown>

			<div markdown>

			<article class="video-500px" style="margin: auto;" markdown>
			<iframe src="https://www.youtube.com/embed/hrL5J6Q5gX8?si=jOPBat8rzMnL7Uz4&amp;start=26;&amp;end=35;" title="Septentrio: Getting Started Video (playback starts at ESD warning)" frameborder="0" allow="accelerometer; autoplay; clipboard-write; encrypted-media; gyroscope; picture-in-picture" allowfullscreen></iframe>
			</article>

			</div>

			-   <a href="https://www.sparkfun.com/ifixit-anti-static-wrist-strap.html">
				<figure markdown>
				Product Thumbnail
				</figure>		

				---

				**iFixit Anti-Static Wrist Strap**<br>
				TOL-25572</a>

			</div>

	!!! warning "Active Antenna"
		Never inject an external DC voltage into the SMA connector for the GPS antenna, as it may damage the mosaic-X5 module. For instance, when using a splitter to distribute the antenna signal to several GNSS receivers, make sure that no more than one output of the splitter passes DC. Use [DC-blocks](https://en.wikipedia.org/wiki/DC_block) otherwise.

		??? info
			A 3 - 5.5V DC voltage can be applied to the main antenna from the `VANT` pin, obviating the need for an external antenna supply or [bias-tee](https://en.wikipedia.org/wiki/Bias_tee).

## USB Programming
The USB connection is utilized for programming and serial communication. Users only need to plug their Tri-band GNSS RTK breakout board into a computer using a USB-C cable.

<figure markdown>
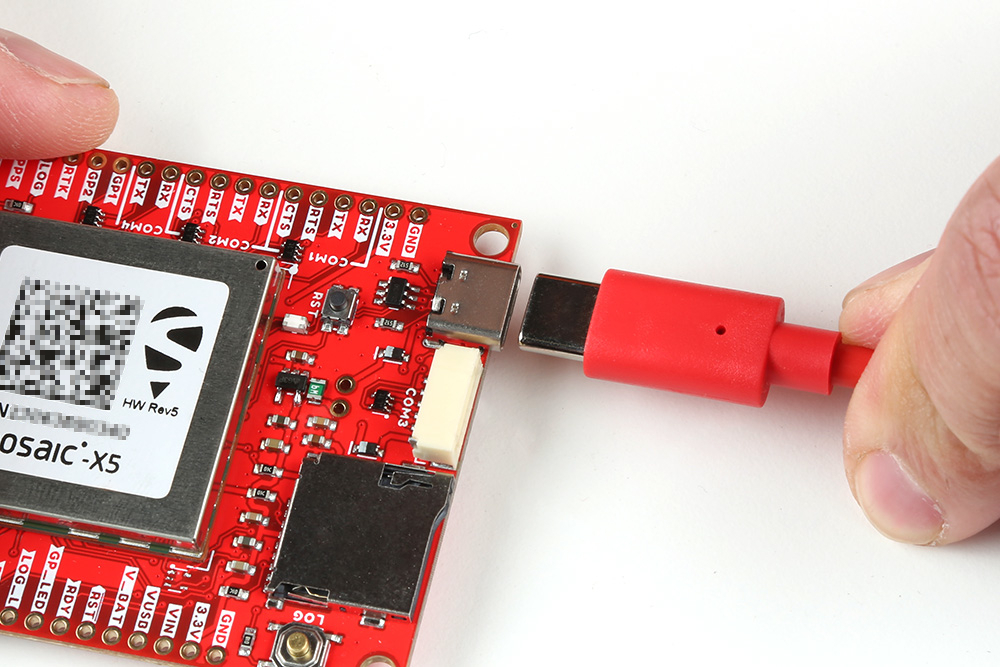
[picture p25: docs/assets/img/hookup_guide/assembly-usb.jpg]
Tri-band GNSS RTK breakout board USB connection

<figcaption markdown>The Tri-band GNSS RTK breakout board with USB-C cable being attached.</figcaption>
</figure>

## GPS Antenna
In order to receive [GNSS](https://en.wikipedia.org/wiki/Satellite_navigation "Global Navigation Satellite System") signals, users will need to connect a compatible antenna. For the best performance, we recommend users choose an active, L1/L2/L5 (tri-band) GNSS antenna and utilize a low-loss cable.

<figure markdown>
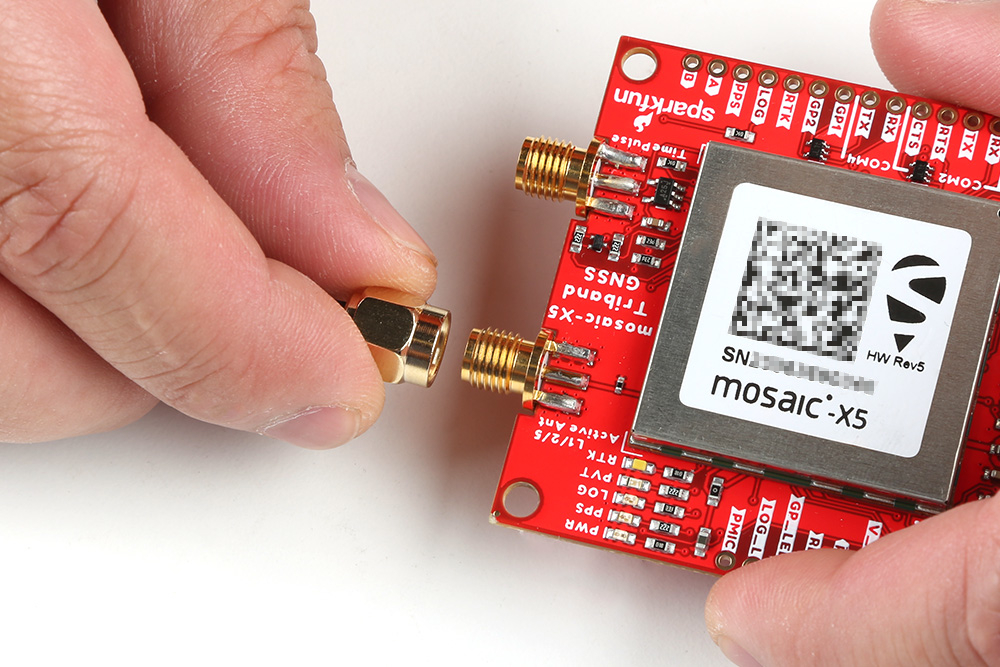
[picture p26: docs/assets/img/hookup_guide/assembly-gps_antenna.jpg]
Tri-band GNSS RTK breakout board antenna connector

<figcaption markdown>Attaching a GPS antenna to the SMA connector on the Tri-band GNSS RTK breakout board.</figcaption>
</figure>

## SD Card
An &micro;SD card slot is available for users to log and store data, locally on the board. Users, will need to insert a compatible SD card and configure the mosaic-X5 module for data logging.

<figure markdown>
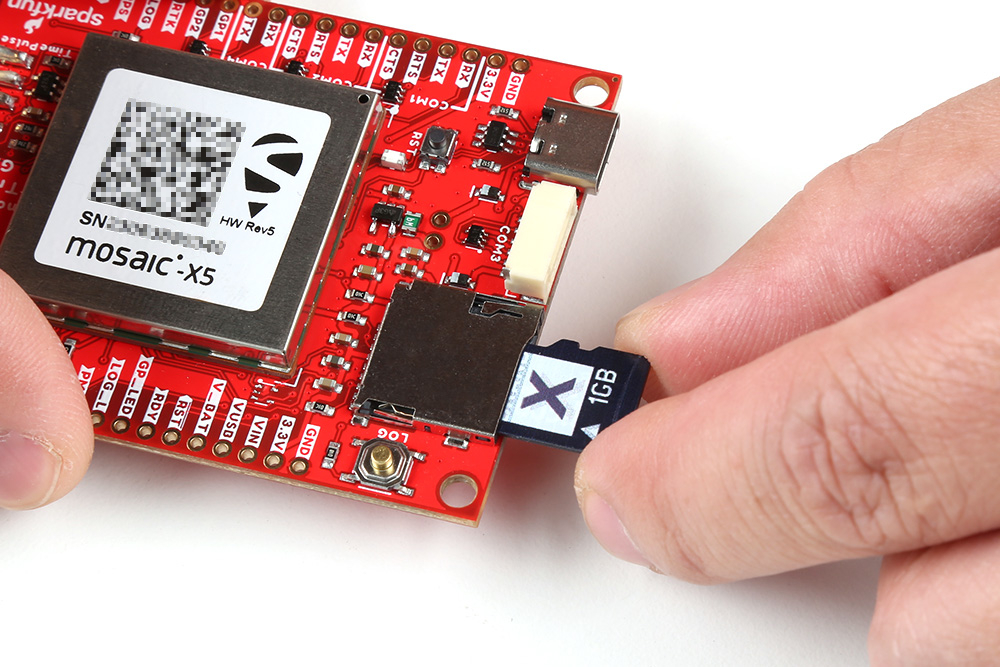
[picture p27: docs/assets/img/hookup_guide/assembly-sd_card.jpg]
Tri-band GNSS RTK breakout board SC card slot

<figcaption markdown>Inserting an SD card into the Tri-band GNSS RTK breakout board.</figcaption>
</figure>

??? tip
	There are multiple ways to configure and enable data logging to an SD card. However, the simplest method is with the ++"LOG"++ button.

	* Pressing the ++"LOG"++ button *(< 5s)* toggles data logging to the SD card on and off.
	* Holding the ++"LOG"++ button for more than 5 seconds *(> 5s)* and then releasing it, will force the board to:
		* Unmount the SD card if it was mounted
		* Mount the SD card if it was unmounted

	For more information, please reference the [SD Card Slot](../hardware_overview/#sd-card-slot) section.

## JST Connector
The JST connector on the Tri-band GNSS RTK board, breaks out the `COM3` UART port of the mosaic-X5 module.

<figure markdown>
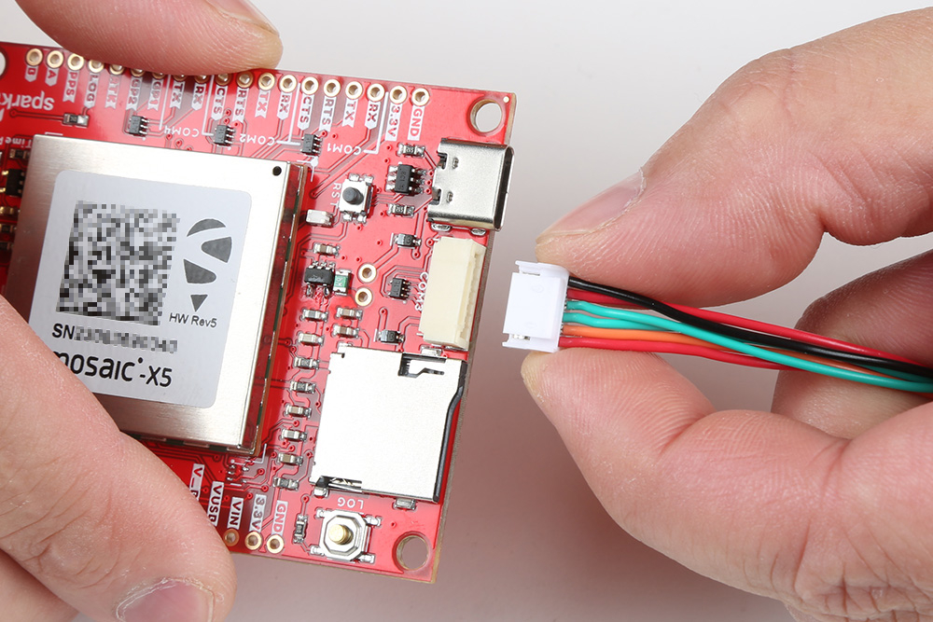
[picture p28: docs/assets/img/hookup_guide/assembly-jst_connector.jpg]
Tri-band GNSS RTK breakout board JST connector

<figcaption markdown>Connecting a cable to the JST connector of the Tri-band GNSS RTK breakout board.</figcaption>
</figure>

!!! tip "Connecting a Radio"
	### Radio Transceivers
	In most circumstances, users will utilize the JST connector to interface with one of our radio transceivers for RTK correction data:

	<div class="grid cards" markdown>

	-   <a href="https://www.sparkfun.com/sik-telemetry-radio-v3-915mhz-100mw.html">
		<figure markdown>
		Product Thumbnail
		</figure>

		---

		**SiK Telemetry Radio V3 - 915MHz, 100mW**<br>
		WRL-19032</a>

	-   <a href="https://www.sparkfun.com/sparkfun-loraserial-kit-915mhz-enclosed.html">
		<figure markdown>
		Product Thumbnail
		</figure>

		---

		**SparkFun LoRaSerial Kit - 915MHz (Enclosed)**<br>
		WRL-20029</a>

	</div>

	??? warning "Pin Connections"
		When connecting the Tri-band GNSS RTK breakout board to one of our radio transceivers, users need to be aware of the pin connections between the products; as their pin layout is mirrored on each connector. Although the labels on each device may vary, their pins will operate exactly the same; with the exception of the input voltage ranges.

		<article style="text-align: center;" markdown>

		<table border="1" markdown>
		<tr>
		<th style="vertical-align:middle;">Pin Number</th>
		<td align="center">
			**1**<br>
			*(Left Side)*
		</td>
		<td align="center">**2**</td>
		<td align="center">**3**</td>
		<td align="center">**4**</td>
		<td align="center">**5**</td>
		<td align="center">
			**6**<br>
			*(Right)*
		</td>
		</tr>
		<tr>
		<th style="vertical-align:middle;">Label</th>
		<td>
			V - Triband<br>
			5V - Radios
		</td>
		<td>
			RX - Triband/SiK<br>
			RXI - LoRaSerial
		</td>
		<td>
			TX - Triband/SiK<br>
			TXO - LoRaSerial
		</td>
		<td>
			C - Triband<br>
			CTS - Radios
		</td>
		<td>
			R - Triband<br>
			RTS - Radios
		</td>
		<td>
			G - Triband<br>
			GND - Radios
		</td>
		</tr>
		<tr>
		<th style="vertical-align:middle;">Function</th>
		<td>
			**Voltage Input**<br>
			- Triband: 3.5 to 5.5V<br>
			- SiK: 5V<br>
			- LoRaSerial: 3.3 to 5V
		</td>
		<td align="center" style="vertical-align:middle;">UART - Receive</td>
		<td align="center" style="vertical-align:middle;">UART - Transmit</td>
		<td align="center" style="vertical-align:middle;">
			Flow Control<br>
			*Clear-to-Send*
		</td>
		<td align="center" style="vertical-align:middle;">
			Flow Control<br>
			*Ready-to-Send*
		</td>
		<td align="center" style="vertical-align:middle;">Ground</td>
		</tr>
		</table>

		</article>

		<!-- Markdown Table (Original)
		| Pin Number | Label              | Function                        |
		| :--------: | :----------------: | :------------------------------ |
		| 1 | V - Triband<br>5V - Radios  | **Voltage Input**<br>- Triband: 3.5 to 5.5V<br>- SiK: 5V<br>- LoRaSerial: 3.3 to 5V |
		| 2 | RX - Triband/SiK<br> RXI - LoRaSerial | UART - Receive        |
		| 3 | TX - Triband/SiK<br> TXO - LoRaSerial | UART - Transmit       |
		| 4 | C - Triband<br>CTS - Radios | Flow Control<br>*Clear-to-Send* |
		| 5 | R - Triband<br>RTS - Radios | Flow Control<br>*Ready-to-Send* |
		| 6 | G - Triband<br>GND - Radios | Ground                          |-->

		#### Pin Connections

		<div class="grid cards" markdown>

		-   When connecting the Tri-band GNSS RTK breakout board to either of the radios, the pin connections should follow the table below. If the flow control is not enabled, the only the `RX`, `TX`, and `GND` pins are utilized.

			<article style="text-align: center;" markdown>

			<table markdown>
			<tr>
			<th>Triband</th>
			<td align="center">RX</td>
			<td align="center">TX</td>
			<td align="center">RTS</td>
			<td align="center">CTS</td>
			<td align="center">GND</td>
			</tr>
			<tr>
			<th>Radio</th>
			<td align="center">TX</td>
			<td align="center">RX</td>
			<td align="center">CTS</td>
			<td align="center">RTS</td>
			<td align="center">GND</td>
			</tr>
			</table>

			</article>

		-   As documented in the [LoRaSerial product manual](https://docs.sparkfun.com/SparkFun_LoRaSerial), the pin connections between a host system *(i.e. Tri-band GNSS RTK breakout board)* and the LoRaSerial Kit radio is outlined in the image below.

			<figure markdown>
			Flow Control (https://docs.sparkfun.com/SparkFun_LoRaSerial/img/SAMD21%20Flow%20control.png "Click to enlarge")
			<figcaption markdown>The `COM` ports on the Tri-band GNSS RTK breakout board.</figcaption>
			</figure>

		</div>

		#### Wiring Connections
		Users have several options for wiring up these two products. Without creating a custom cable assembly, we recommend utilizing our [breadboard cable](https://www.sparkfun.com/breadboard-to-jst-ghr-06v-cable-6-pin-x-1-25mm-pitch-for-loraserial.html) along with any [breadboard](https://www.sparkfun.com/categories/302) or [F/F jumper wires](https://www.sparkfun.com/jumper-wires-premium-6-f-f-pack-of-10.html).

		<div class="grid cards" markdown>
	
		-   <a href="https://www.sparkfun.com/breadboard-to-jst-ghr-06v-cable-6-pin-x-1-25mm-pitch-for-loraserial.html">
			<figure markdown>
			Product Thumbnail
			</figure>
	
			---
	
			**Breadboard to JST-GHR-06V Cable - 6-Pin x 1.25mm Pitch (For LoRaSerial)**<br>
			CAB-23353</a>
	
		-   <a href="https://www.sparkfun.com/breadboard-mini-modular-white.html">
			<figure markdown>
			Product Thumbnail
			</figure>
	
			---
	
			**Breadboard - Mini Modular (White)**<br>
			PRT-12043</a>
	
		</div>

		Following the pin connections, outlined in the [table above](#pin-connections), users can wire up the two devices. In the figures below, a reference diagram for the pin connections of JST connector are provided along with an example setup, using a breadboard. However, users are free to utilize the products/methods that suit their project requirements.

		<div class="grid cards" markdown>

		-   Below if a diagram of the pin connections for the 6-pin JST GH connector on the devices that users can reference without having to pull up the datasheet or product manuals.

			<figure markdown>
			JST pins
			<figcaption markdown>The pin connections of the JST connector on the Tri-band GNSS RTK breakout board.</figcaption>
			</figure>

			!!! warning
				Please remember that the power pin, is a voltage input and should not be utilized to transfer power between the devices. Users should power their devices separately through the USB connectors on the devices.

		-   Below, is an example illustrating the [Tri-band GNSS RTK breakout board](https://www.sparkfun.com/sparkfun-triband-gnss-rtk-breakout-mosaic-x5.html) being connected to the [LoRaSerial Kit - 915MHz](https://www.sparkfun.com/sparkfun-loraserial-kit-915mhz-enclosed.html) utilizing the [breadboard cable](https://www.sparkfun.com/breadboard-to-jst-ghr-06v-cable-6-pin-x-1-25mm-pitch-for-loraserial.html) and [breadboard](https://www.sparkfun.com/breadboard-self-adhesive-white.html).

			<figure markdown>
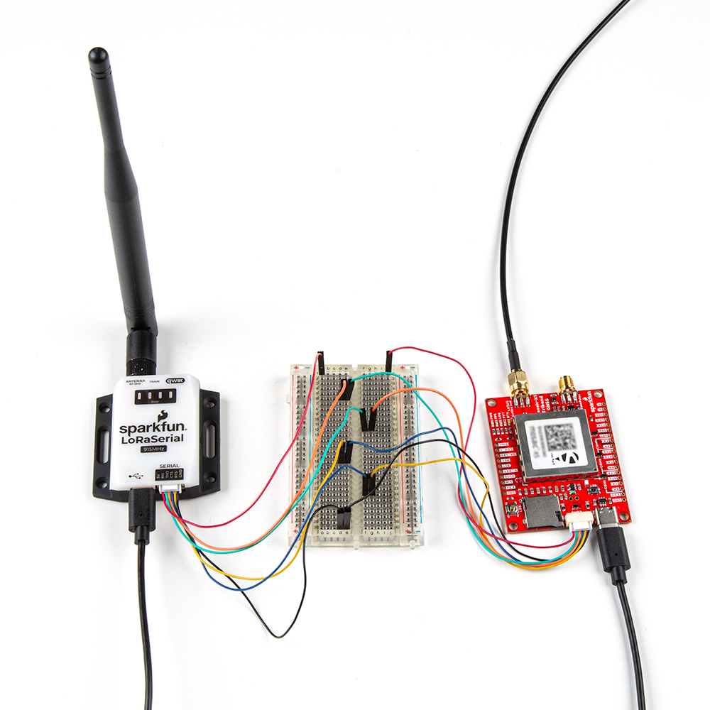
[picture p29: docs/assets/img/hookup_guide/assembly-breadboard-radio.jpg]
			
			<figcaption markdown>The [Tri-band GNSS RTK breakout](https://www.sparkfun.com/sparkfun-triband-gnss-rtk-breakout-mosaic-x5.html) being connected to the [LoRaSerial Kit - 915MHz](https://www.sparkfun.com/sparkfun-loraserial-kit-915mhz-enclosed.html).</figcaption>
			</figure>

			In this example, the devices are being powered separately through their USB ports. This is because the devices power pins are configured as voltage inputs. *(Click the image to enlarge, users will notice that the power pins are not connected together, unlike the other pins.)*

		</div>

		When complete, the setup should appear similar to the figure below.

		??? tip "Pairing Radios"
			By default, the radios in the LoRaSerial Kit - 915MHz are pre-configured for [point-to-point](https://docs.sparkfun.com/SparkFun_LoRaSerial/operating_modes/#point-to-point) communication and a paired with each other. *For instructions on other configurations, please reference the [product manual](https://docs.sparkfun.com/SparkFun_LoRaSerial/) for the LoRaSerial Kit.*

		<figure markdown>
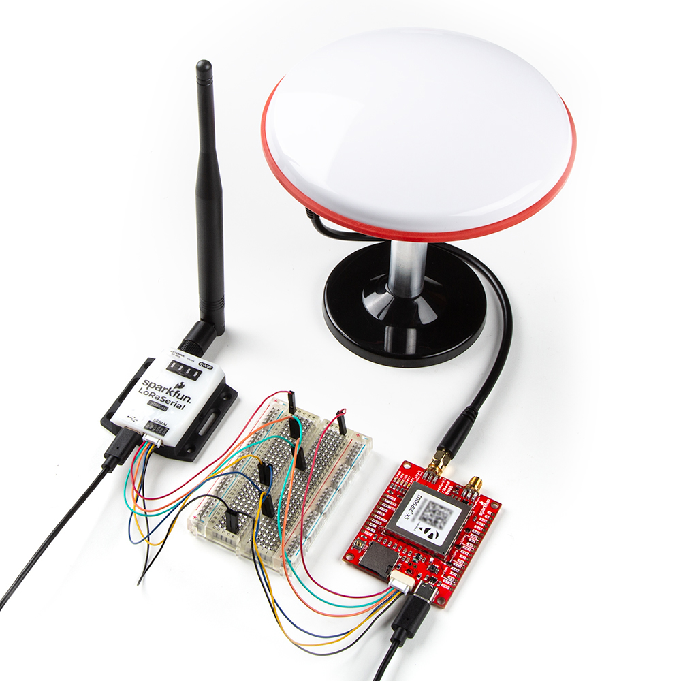
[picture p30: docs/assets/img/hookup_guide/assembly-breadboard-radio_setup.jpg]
		
		<figcaption markdown>The [Tri-band GNSS RTK breakout](https://www.sparkfun.com/sparkfun-triband-gnss-rtk-breakout-mosaic-x5.html) being connected to the [LoRaSerial Kit - 915MHz](https://www.sparkfun.com/sparkfun-loraserial-kit-915mhz-enclosed.html).</figcaption>
		</figure>

		??? info "Custom Crossover Cable"
			Users could potentially create their own custom cable from our existing cable assembly. However, this would require delicate dexterity skills as the plastic pins of the harness's connector easily break. Two cable assemblies are required to create a single custom wiring harness *(i.e. crossover cable)*.

			<div class="grid cards" markdown>

			-   <a href="https://www.sparkfun.com/jst-ghr-04v-to-jst-ghr-06v-cable-1-25mm-pitch.html">
				<figure markdown>
				Product Thumbnail
				</figure>

				---

				**JST-GHR-04V to JST-GHR-06V Cable - 1.25mm pitch**<br>
				CAB-17239</a>

			</div>

			Following the pin connections, outlined in the [table above](#pin-connections), users would rewire the cable assembly. Make sure not to exclude the power pin connection; on both devices, that pin is for an input voltage on the JST connector.

			<div class="grid" markdown>

			<div markdown>

			<figure markdown>
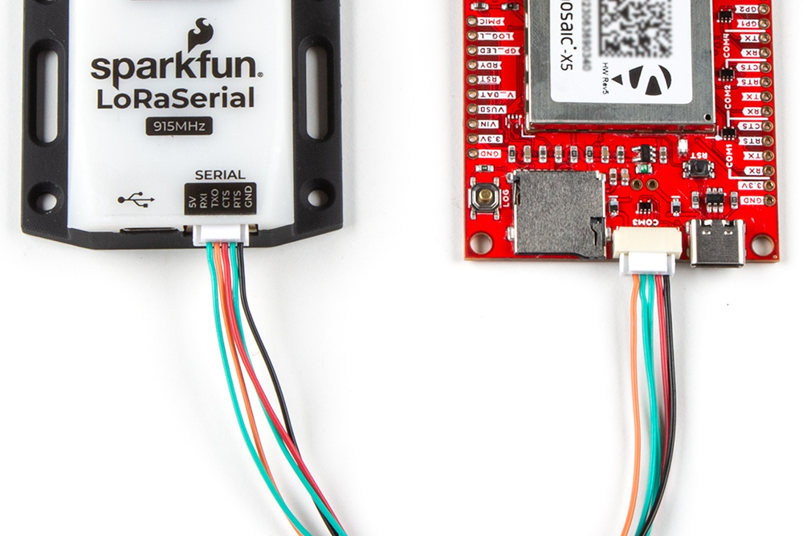
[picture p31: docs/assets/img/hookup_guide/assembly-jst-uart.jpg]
			
			<figcaption markdown>A custom cable assembly connecting the [Tri-band GNSS RTK breakout](https://www.sparkfun.com/sparkfun-triband-gnss-rtk-breakout-mosaic-x5.html) to the [LoRaSerial Kit](https://www.sparkfun.com/sparkfun-loraserial-kit-915mhz-enclosed.html). Notice how the color of the wire swap for the UART and flow control pins between the two connectors (Click to enlarge).</figcaption>
			</figure>

			</div>

			<div markdown>

			<figure markdown>
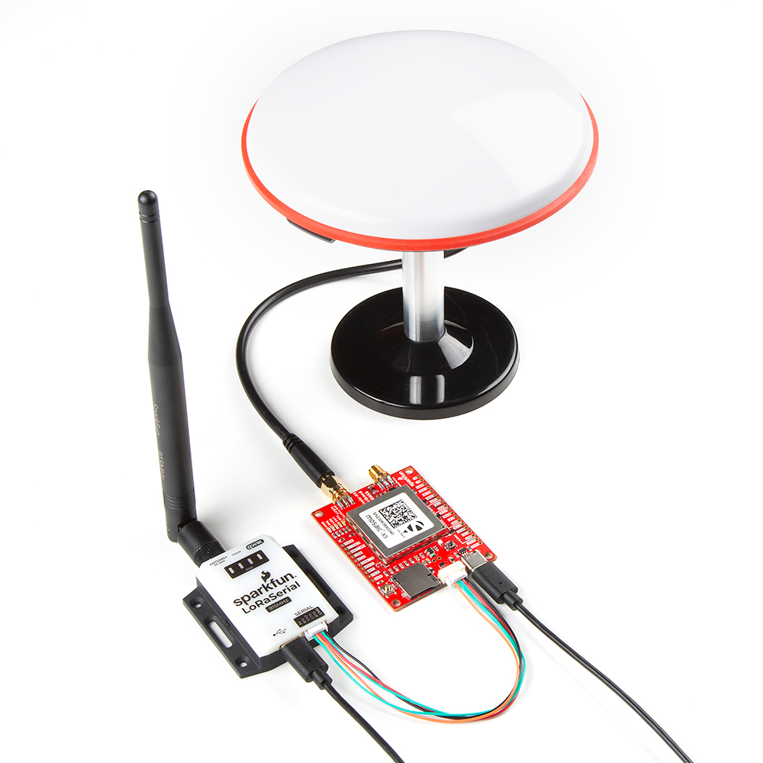
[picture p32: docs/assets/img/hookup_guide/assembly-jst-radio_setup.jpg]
jumper pin modification setup
			
			<figcaption markdown>The same IC-hook modification. The setup is viewed from a different angle w/ the GPS antenna inside the picture frame.</figcaption>
			</figure>

			</div>

			</div>

	??? danger "Enabling a Voltage Output"
		!!! warning "Disclaimer"
			<span style="color:red;" markdown>**Due to the inherent risks of the modifications below, technical assistance will not be provided nor will refunds or returns be authorized for products with the following modifications.**</span>

			By proceeding with the instructions below, users acknowledge that they are purposefully circumventing the reverse current protection diode on the board. By doing so, this can potentially expose their computer and any other devices to be permanently damaged. ***Proceed at your own risk!***

		#### Enable Voltage Output
		While not recommended, because it bypasses the reverse current protection diode, users can enable a voltage output on the JST connector of the Tri-band GNSS RTK breakout board. Below are two different modifications that users could potentially utilize.

		##### Jumper Pin Modification
		The jumper pin modification requires a [header](https://www.sparkfun.com/categories/381) to be soldered to the `VIN` and `VUSB` pins of the Tri-band GNSS RTK breakout board. Then a [2-pin jumper](https://www.sparkfun.com/jumper-2-pin.html) is utilized to bypass the protection diodes between the two pins. The example in the image below, utilizes a simple straight header. When a jumper is placed on the `VIN` and `VUSB` pins, any power that is provided through the USB-C connector of the Tri-band GNSS RTK breakout, will now be connected to the the power pin of the JST connector.

		<div class="grid" markdown>

		<div markdown>

		<figure markdown>
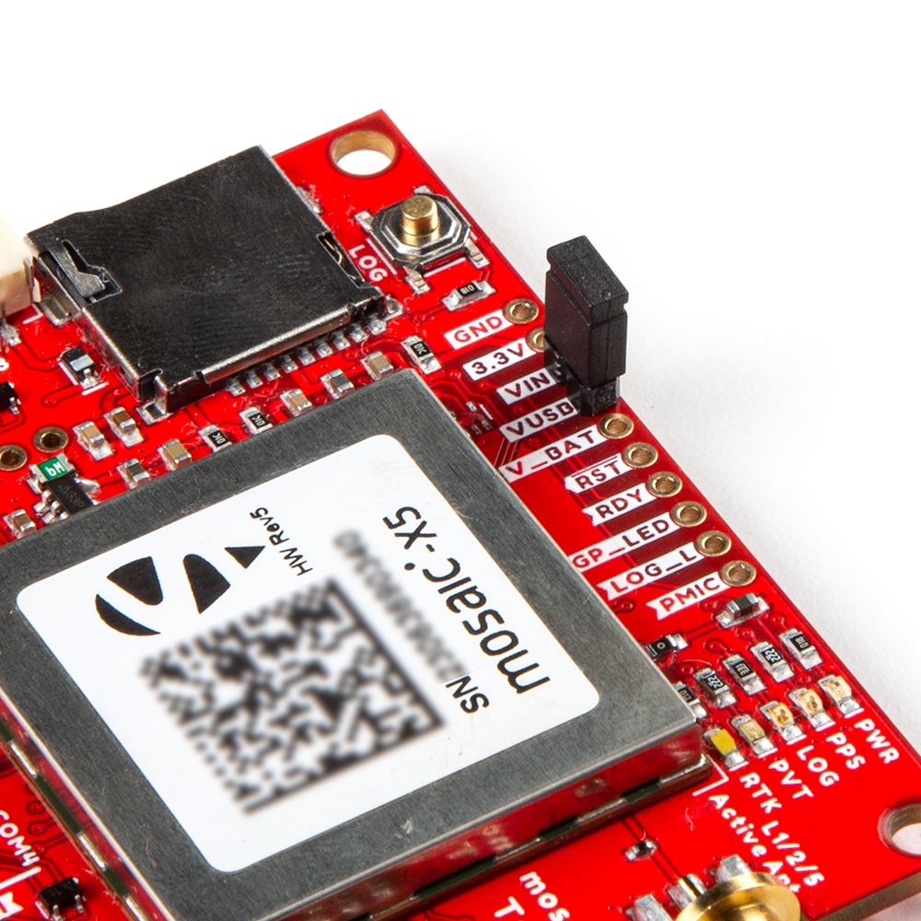
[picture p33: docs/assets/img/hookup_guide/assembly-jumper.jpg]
jumper pin modification
		
		<figcaption markdown>The jumper pin modification that enables a voltage output on the power pin of the JST connector on the Tri-band GNSS RTK breakout board.</figcaption>
		</figure>

		</div>

		<div class="grid cards" markdown>

		-   <a href="https://www.sparkfun.com/straight-header-male-pth-0-1in-40-pin.html">
			<figure markdown>
			Product Thumbnail
			</figure>
	
			---
	
			**Break Away Headers - Straight**<br>
			PRT-00116</a>

		</div>

		<div class="grid cards" markdown>

		-   <a href="https://www.sparkfun.com/jumper-2-pin.html">
			<figure markdown>
			Product Thumbnail
			</figure>
	
			---
	
			**Jumper - 2 Pin**<br>
			PRT-09044</a>

		</div>

		</div>

		##### IC-Hook Modification
		The IC-hook modification utilizes an [IC-hook w/ pigtail](https://www.sparkfun.com/ic-hook-with-pigtail.html) to breakout the `VUSB` pin of the Tri-band GNSS RTK breakout board on a jumper wire.

		<div class="grid" markdown>

		<div class="grid cards" markdown>

		-   <a href="https://www.sparkfun.com/ic-hook-with-pigtail.html">
			<figure markdown>
			Product Thumbnail
			</figure>
	
			---
	
			**IC Hook with Pigtail**<br>
			CAB-09741</a>

		</div>

		<div markdown>

		<figure markdown>
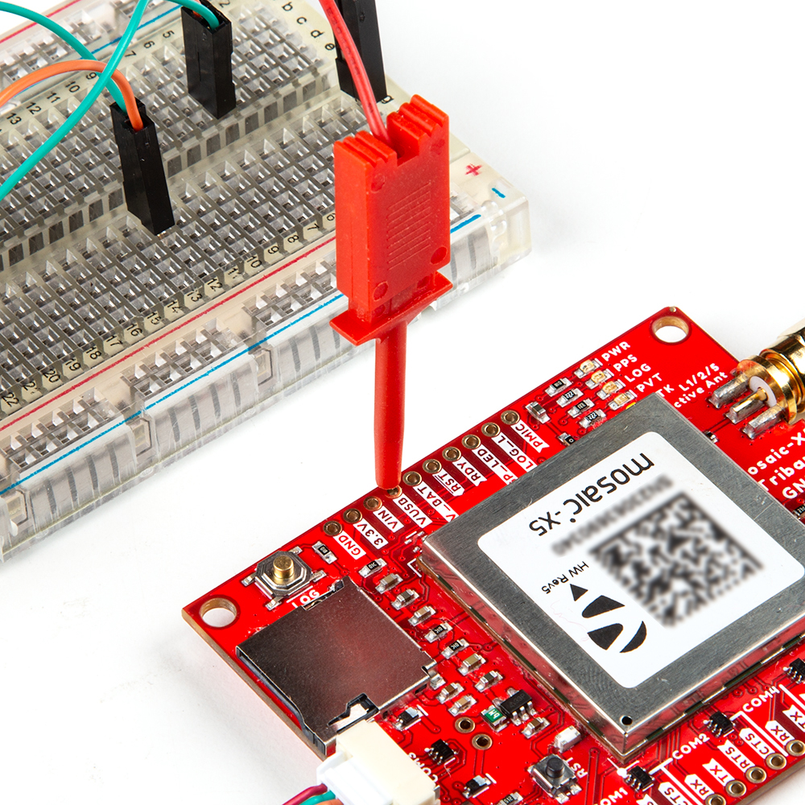
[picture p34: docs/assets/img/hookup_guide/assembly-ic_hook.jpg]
IC-hook modification
		
		<figcaption markdown>The IC-hook modification that provides a voltage output from the `VUSB` pin of the Tri-band GNSS RTK breakout board.</figcaption>
		</figure>

		</div>

		</div>

		In the example displayed below, IC-hook w/ pigtail connects the `VUSB` pin of the Tri-band GNSS RTK breakout directly to the `5V` pin of the LoRaSerial Kit through the breadboard. *(Click the images to enlarge, users will notice that the power pin of the radio is wired directly to the `VUSB` pin of the Tri-band GNSS RTK breakout board.)*

		<div class="grid" markdown>

		<div markdown>

		<figure markdown>
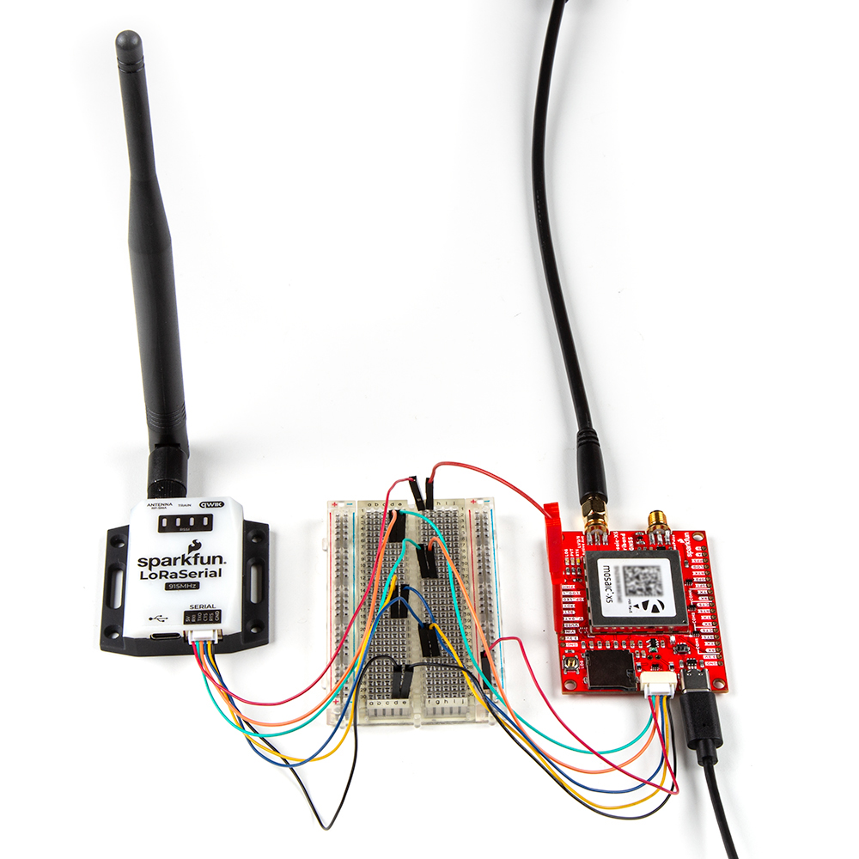
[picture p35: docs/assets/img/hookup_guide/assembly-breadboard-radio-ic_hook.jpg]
		
		<figcaption markdown>The IC-hook modification that provides a voltage output from the `VUSB` pin of the Tri-band GNSS RTK breakout board.</figcaption>
		</figure>

		</div>

		<div markdown>

		<figure markdown>
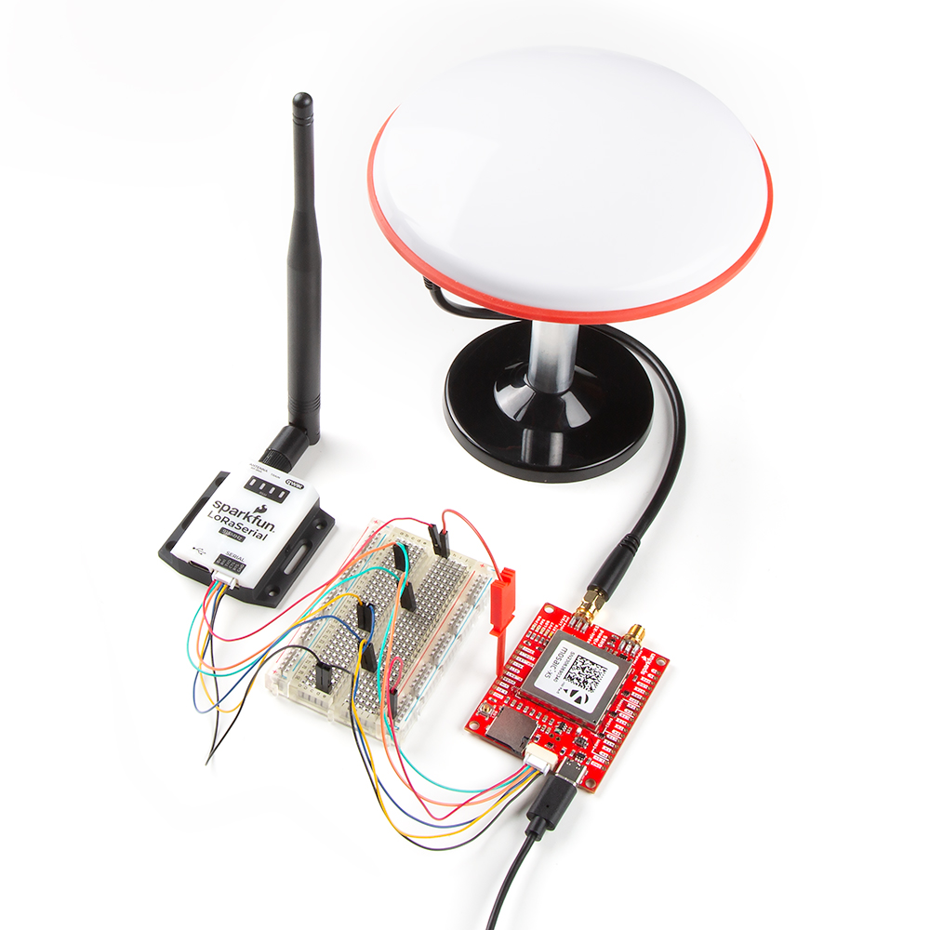
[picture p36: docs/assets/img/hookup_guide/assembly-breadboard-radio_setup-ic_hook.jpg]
jumper pin modification setup
		
		<figcaption markdown>The same IC-hook modification. The setup is viewed from a different angle w/ the GPS antenna inside the picture frame.</figcaption>
		</figure>

		</div>

		</div>

<!-- !!! tip "Connecting to a PixHawk4"
	The Septentrio mosaic-X5 GNSS receiver module, is supported on the PixHawk4
	https://www.septentrio.com/en/company/news/septentrio-gps/gnss-now-supports-px4-autopilot
	https://customersupport.septentrio.com/s/article/How-to-connect-mosaic-go-with-PX4-autopilot
	https://github.com/septentrio-gnss/Septentrio-PX4-Autopilot
	https://docs.px4.io/main/en/gps_compass/septentrio_mosaic-go.html

	https://customersupport.septentrio.com/s/article/How-to-connect-latest-AsteRx-OEM-receivers-with-Pixhawk-4-using-Robotics-Interface-board
 -->

## Breakout Pins
The [PTH](https://en.wikipedia.org/wiki/Through-hole_technology "Plated Through Holes") pins on the Tri-band GNSS RTK board are broken out into 0.1"-spaced pins on the outer edges of the board.

??? note "New to soldering?"
	If you have never soldered before or need a quick refresher, check out our [How to Solder: Through-Hole Soldering](https://learn.sparkfun.com/tutorials/how-to-solder-through-hole-soldering) guide.

	<div class="grid cards" markdown align="center">

	-   <a href="https://learn.sparkfun.com/tutorials/5">
		<figure markdown>
		Tutorial thumbnail
		</figure>

		---
		
		**How to Solder: Through-Hole Soldering**</a>

	</div>

<div class="grid" markdown>

<div markdown>

=== "Headers"

	When selecting headers, be sure you are aware of the functionality you require.

	<figure markdown>
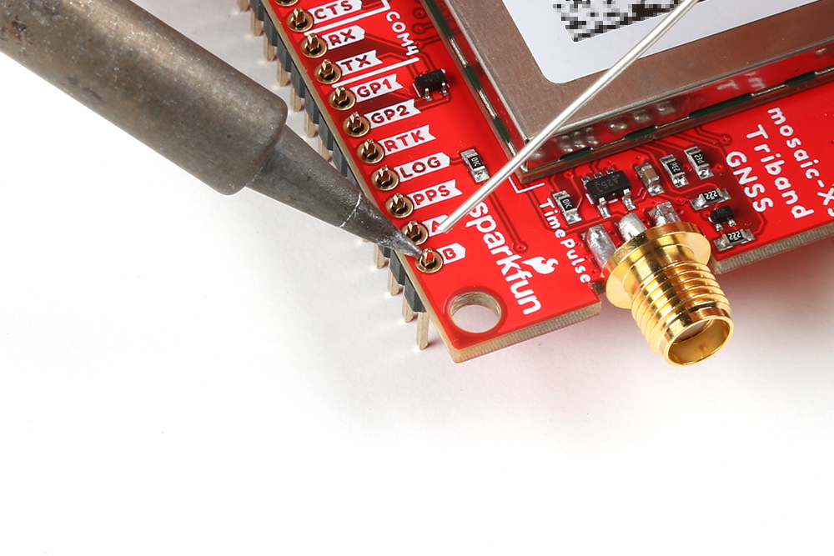
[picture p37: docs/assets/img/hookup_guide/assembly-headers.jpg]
Soldering headers
	
	<figcaption markdown>Soldering headers to the Tri-band GNSS RTK breakout board.</figcaption>
	</figure>

</div>

<div markdown>

=== "Hookup Wires"

	For a more permanent connection, users can solder wires directly to the board.

	<figure markdown>
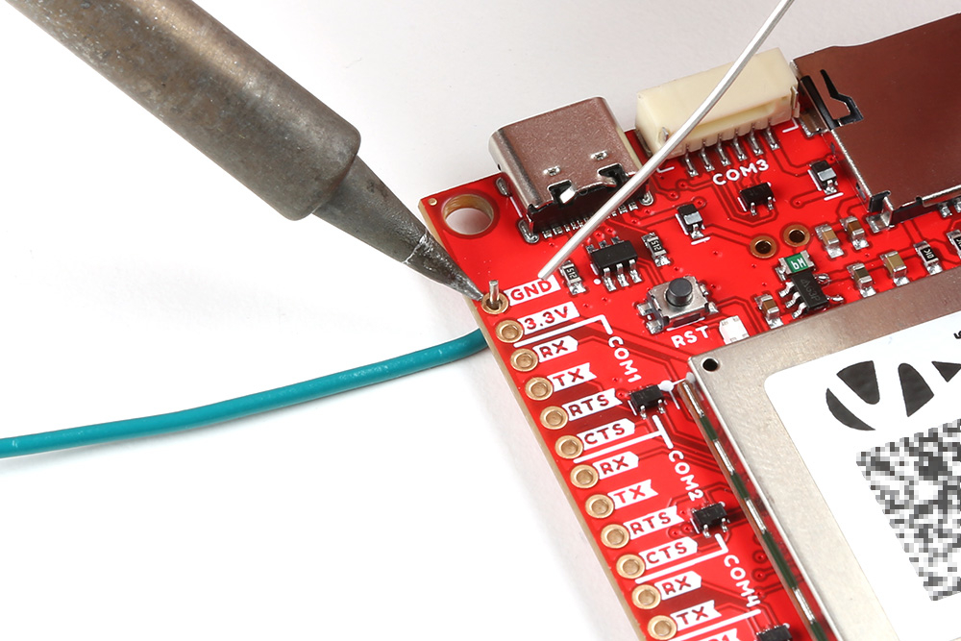
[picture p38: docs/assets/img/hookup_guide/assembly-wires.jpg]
Soldering wires
	
	<figcaption markdown>Soldering wires to the Tri-band GNSS RTK breakout board.</figcaption>
	</figure>

</div>

</div>

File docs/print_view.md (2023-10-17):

---
hide:
  - navigation
  - toc
icon: material/printer
---

--8<-- "./docs/introduction.md:5"

# Hardware Overview
--8<-- "./docs/hardware_overview.md:37"

# Hardware Assembly
--8<-- "./docs/hardware_assembly.md:37"

# Software Overview
--8<-- "./docs/software_overview.md:29"

## RxTools
--8<-- "./docs/rxtools.md:35"

## Web Interface
--8<-- "./docs/web_interface.md:35"

# Troubleshooting Tips
--8<-- "./docs/troubleshooting_tips.md:5"

# Resources
--8<-- "./docs/resources.md"

## Background Resources
--8<-- "./docs/background.md:5"

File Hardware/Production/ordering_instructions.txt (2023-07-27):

panel size, 149x116mm
PCB thickness, 1.6mm
number of layers, 4
controlled impedance, JLC7628
material, TG155
soldermask color, Red
silkscreen color, White
oz copper, 1oz
finish, ENIG
stencils, top
pcs per panel, 4
min trace width, 0.1778mm / 0.0070in
min drill size, 0.3048mm / 0.0120in
filename to layer stackup 1/2/3/4: GTL, GL2, GL3, GBL

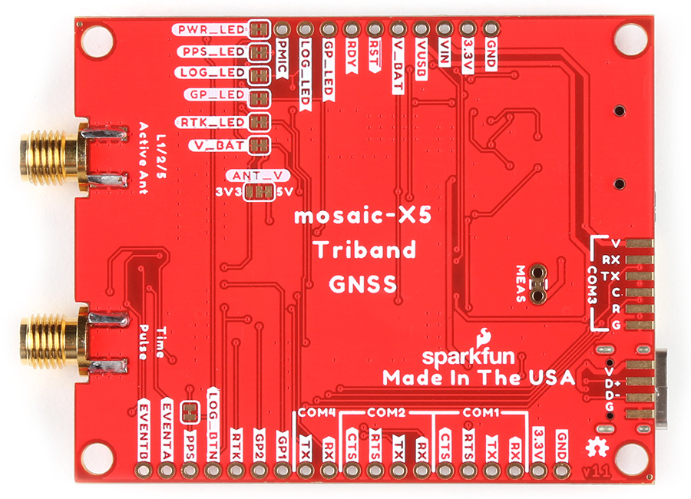
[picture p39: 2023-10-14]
docs/assets/img/hookup_guide/bottom.jpg

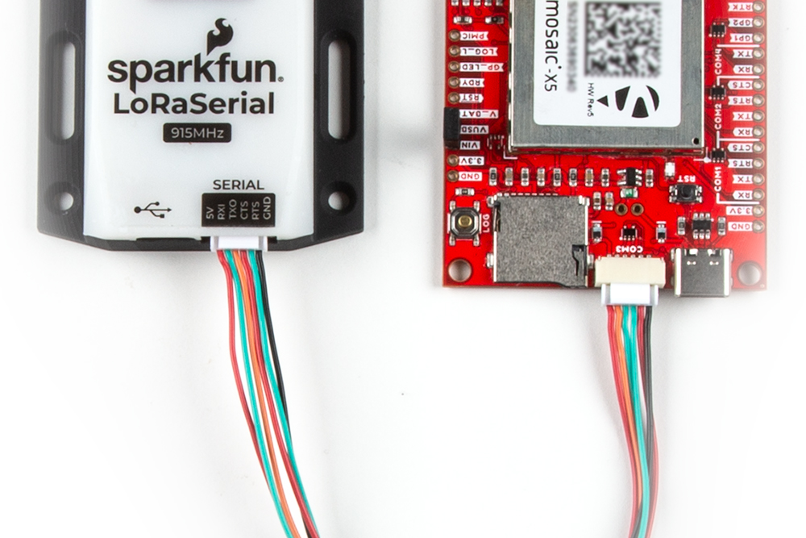
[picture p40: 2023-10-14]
docs/assets/img/hookup_guide/assembly-jst-uart-jumper.jpg

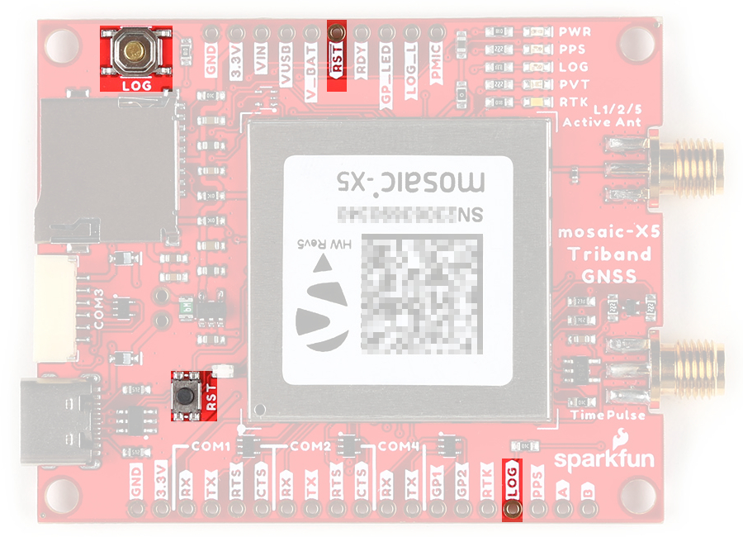
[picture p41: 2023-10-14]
docs/assets/img/hookup_guide/buttons2.jpg

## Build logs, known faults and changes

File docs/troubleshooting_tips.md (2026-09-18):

---
icon: sfe
---

!!! warning "Need Help?"
	If you need technical assistance or more information on a product that is not working as you expected, we recommend heading on over to the [SparkFun Technical Assistance](https://www.sparkfun.com/technical_assistanc) page for some initial troubleshooting.

	<article style="text-align: center;" markdown>
	[SparkFun Technical Assistance Page](https://www.sparkfun.com/technical_assistance){ .md-button .md-button--primary }
	</article>
	
	If you can't find what you need there, the [SparkFun Forums](https://community.sparkfun.com/) is a great place to search product forums and ask questions.
	
	!!! info "Account Registration Required"
		If this is your first visit to our forum, you'll need to create a [Forum Account](https://community.sparkfun.com/signup) to post questions.

## Electrostatic Discharge
The mosaic-X5 module is sensitive to [ESD](https://en.wikipedia.org/wiki/Electrostatic_discharge "Electrostatic Discharge"). Use a proper grounding system to make sure that the working surface and the components are at the same electric potential.

!!! warning "ESD Precaution"
	As recommended by the manufacturer, we highly recommend that users take the necessary precautions to avoid damaging their module.

	<div class="grid cards" markdown>

	<div markdown>

	<article class="video-500px" style="margin: auto;" markdown>
	<iframe src="https://www.youtube.com/embed/hrL5J6Q5gX8?si=jOPBat8rzMnL7Uz4&amp;start=26;&amp;end=35;" title="Septentrio: Getting Started Video (playback starts at ESD warning)" frameborder="0" allow="accelerometer; autoplay; clipboard-write; encrypted-media; gyroscope; picture-in-picture" allowfullscreen></iframe>
	</article>

	</div>

	-   - The Tri-band GNSS RTK breakout board features ESD protection on the USB-C connector and breakout's I/O:

			- USB data lines
			- I/O PTH pads
			- JST connector's pins
		- The mosaic-X5 module features internal ESD protection to the `ANT_1` antenna input.

	</div>

## USB Driver
A USB driver is only required for Windows PCs *(see the [USB Driver](../software_overview/#usb-driver) section)*.

## GPS Antenna

### Power Input
!!! danger "Active Antenna"
	Never inject an external DC voltage into the SMA connector for the GPS antenna, as it may damage the mosaic-X5 module. For instance, when using a splitter to distribute the antenna signal to several GNSS receivers, make sure that no more than one output of the splitter passes DC. Use [DC-blocks](https://en.wikipedia.org/wiki/DC_block) otherwise.

A 3 - 5.5V DC voltage can be applied to the main antenna from the `VANT` pin, obviating the need for an external antenna supply or [bias-tee](https://en.wikipedia.org/wiki/Bias_tee).

### Supported Frequency Bands
For the best performance, we recommend users choose a compatible L1/L2/L5 (tri-band) GNSS antenna and utilize a low-loss cable. Utilizing an antenna that doesn't match all the supported frequency bands of the mosaic-X5, will result in reduced performance and capabilities.

## Data Logging
For data logging issues, here are some simple troubleshooting tips:

* Make sure that your SD card is formatted to a `FAT32` file system.
	* The `FAT32` file system also limits the maximum capacity of the card to less than **32GB** *(i.e. a 256GB SD card will not work)*.
* Make sure that the mosaic-X5 module has a configured data stream output.
* Use the mosaic-X5 web page to verify that the SD card is mounted as a storage drive.

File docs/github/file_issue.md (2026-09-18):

# Did we make a mistake?

Spot something wrong? Please let us know. 

<!-- Technical Assistance Box -->
!!! warning "Need Help?"
	If you need technical assistance or more information on a product that is not working as you expected, we recommend heading on over to the [SparkFun Technical Assistance](https://www.sparkfun.com/technical_assistanc) page for some initial troubleshooting. This **Submit Issues** page is not where users should seek assistance.

	<article style="text-align: center;" markdown>
	[SparkFun Technical Assistance Page](https://www.sparkfun.com/technical_assistance){ .md-button .md-button--primary }
	</article>
	
	If you can't find what you need there, the [SparkFun Forums](https://community.sparkfun.com/) is a great place to search the product forums and ask questions.
	
	!!! info "Account Registration Required"
		For your first visit to our forum, you'll need to create a [Forum Account](https://community.sparkfun.com/signup) to post questions.

## :material-file-document-multiple:&nbsp;Discrepancies in the Documentation

All of our documentation can be modified by you! Please help us make it better.

* The documentation files for these pages are contained in the [`docs` folder](https://github.com/sparkfun/SparkFun_GNSS_mosaic-X5/tree/main/docs) of the [SparkFun mosaic-X5 (Tri-band + RTK) GNSS Breakout repository](https://github.com/sparkfun/SparkFun_GNSS_mosaic-X5).

### 🔍 Spot something wrong?

If a section of the documentation is incorrect, please [open an issue](https://github.com/sparkfun/SparkFun_GNSS_mosaic-X5/issues) and let us know.

### Do you have a suggested correction?

Please, refer to the [Contribute](../contribute/#improve-our-documentation) page.

<!--
1. With a GitHub account, [fork this repository](https://github.com/sparkfun/SparkFun_GNSS_mosaic-X5/fork).
2. Add your correction(s) or improvement(s) to the markdown file(s)
3. File a pull request with your changes, and enjoy making the ~~words~~ ~~worlds~~ world a better place.
	* Once received, the documentation specialist will automatically be notified.
	* We will review your suggested improvement(s) to make sure they are correct and fit within our documentation standards. -->

## :material-cog:&nbsp;Problems in the Hardware Design

All of our designs are open-source! Please help us make it better.

* Our board design files are contained in the [`Hardware` folder](https://github.com/sparkfun/SparkFun_GNSS_mosaic-X5/tree/main/Hardware) of the [SparkFun mosaic-X5 (Tri-band + RTK) GNSS Breakout repository](https://github.com/sparkfun/SparkFun_GNSS_mosaic-X5).

### Does something not make sense? 🤔

If part of the design is confusing, please [open an issue](https://github.com/sparkfun/SparkFun_GNSS_mosaic-X5/issues) and let us know.

### Did we forget to include an important function of the board? 🤦

If part of the board's functionality is missing, please [open an issue](https://github.com/sparkfun/SparkFun_GNSS_mosaic-X5/issues) and file a feature request.

!!! tip "Design Considerations"
	Please keep in mind that we may intentionally exclude certain functions of the board to meet our product design requirements.
	
	* *For example, our Qwiic Micro boards are intended to fit on a small board layout and only use I^2^C communication; therefore, we may not have the SPI and interrupt pins available for users.*

### Do you wish to contribute directly to improving the board design?

Please, refer to the [Contribute](../contribute/#improve-our-hardware-design) page.

<!-- 1. With a GitHub account, [fork this repository](https://github.com/sparkfun/SparkFun_GNSS_mosaic-X5/fork).
2. Add your design augmentation(s)
3. File a pull request with your changes, and enjoy making the ~~words~~ ~~worlds~~ world a better place.
	1. Once received, the engineer in charge of the original design will automatically be notified.
	2. We will review your suggested improvement(s) to verify that they are within our board design standards and meet our product design requirements.
	3. If approved, we will flag these changes for our next board revision. Congrats! 🍻

		!!! info
			Even if your suggestion is accepted, these changes may not be immediately available for purchase. We may have to cycle through our current product inventory first. -->

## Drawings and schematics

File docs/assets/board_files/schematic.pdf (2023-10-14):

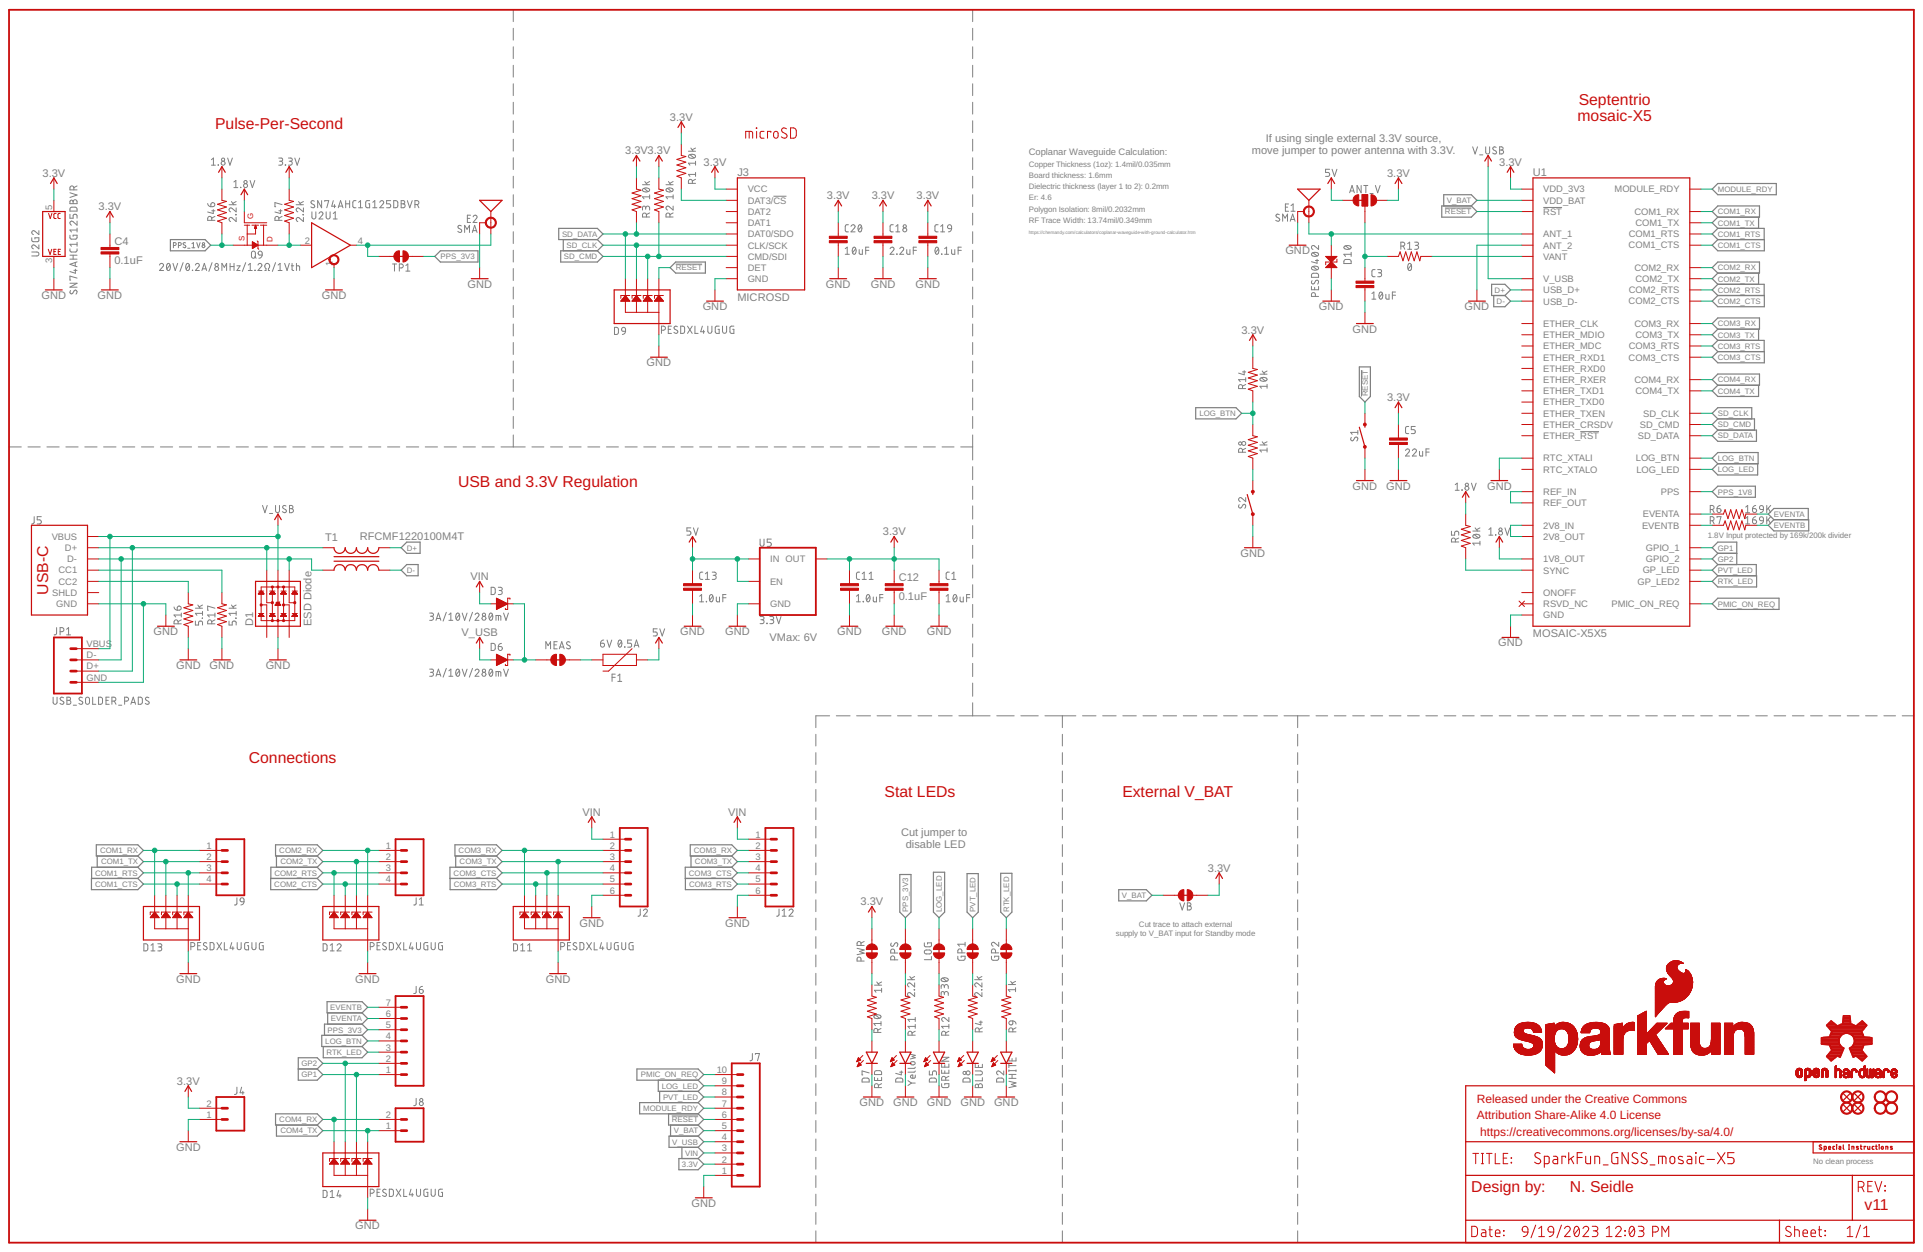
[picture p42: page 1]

If using single external 3.3V source, move jumper to power antenna with 3.3V. GND

Er: 4.6 Copper Thickness (1oz): 1.4mil/0.035mm
Board thickness: 1.6mm
Dielectric thickness (layer 1 to 2): 0.2mm

VCC
DAT3/CS CMD/SDI DAT0/SDO
DAT2 DAT1 CLK/SCK DET

https://chemandy.com/calculators/coplanar-waveguide-with-ground-calculator.htm

Cut trace to attach external supply to V_BAT input for Standby mode

Released under the Creative Commons Attribution Share-Alike 4.0 License

https://creativecommons.org/licenses/by-sa/4.0/ Design by:

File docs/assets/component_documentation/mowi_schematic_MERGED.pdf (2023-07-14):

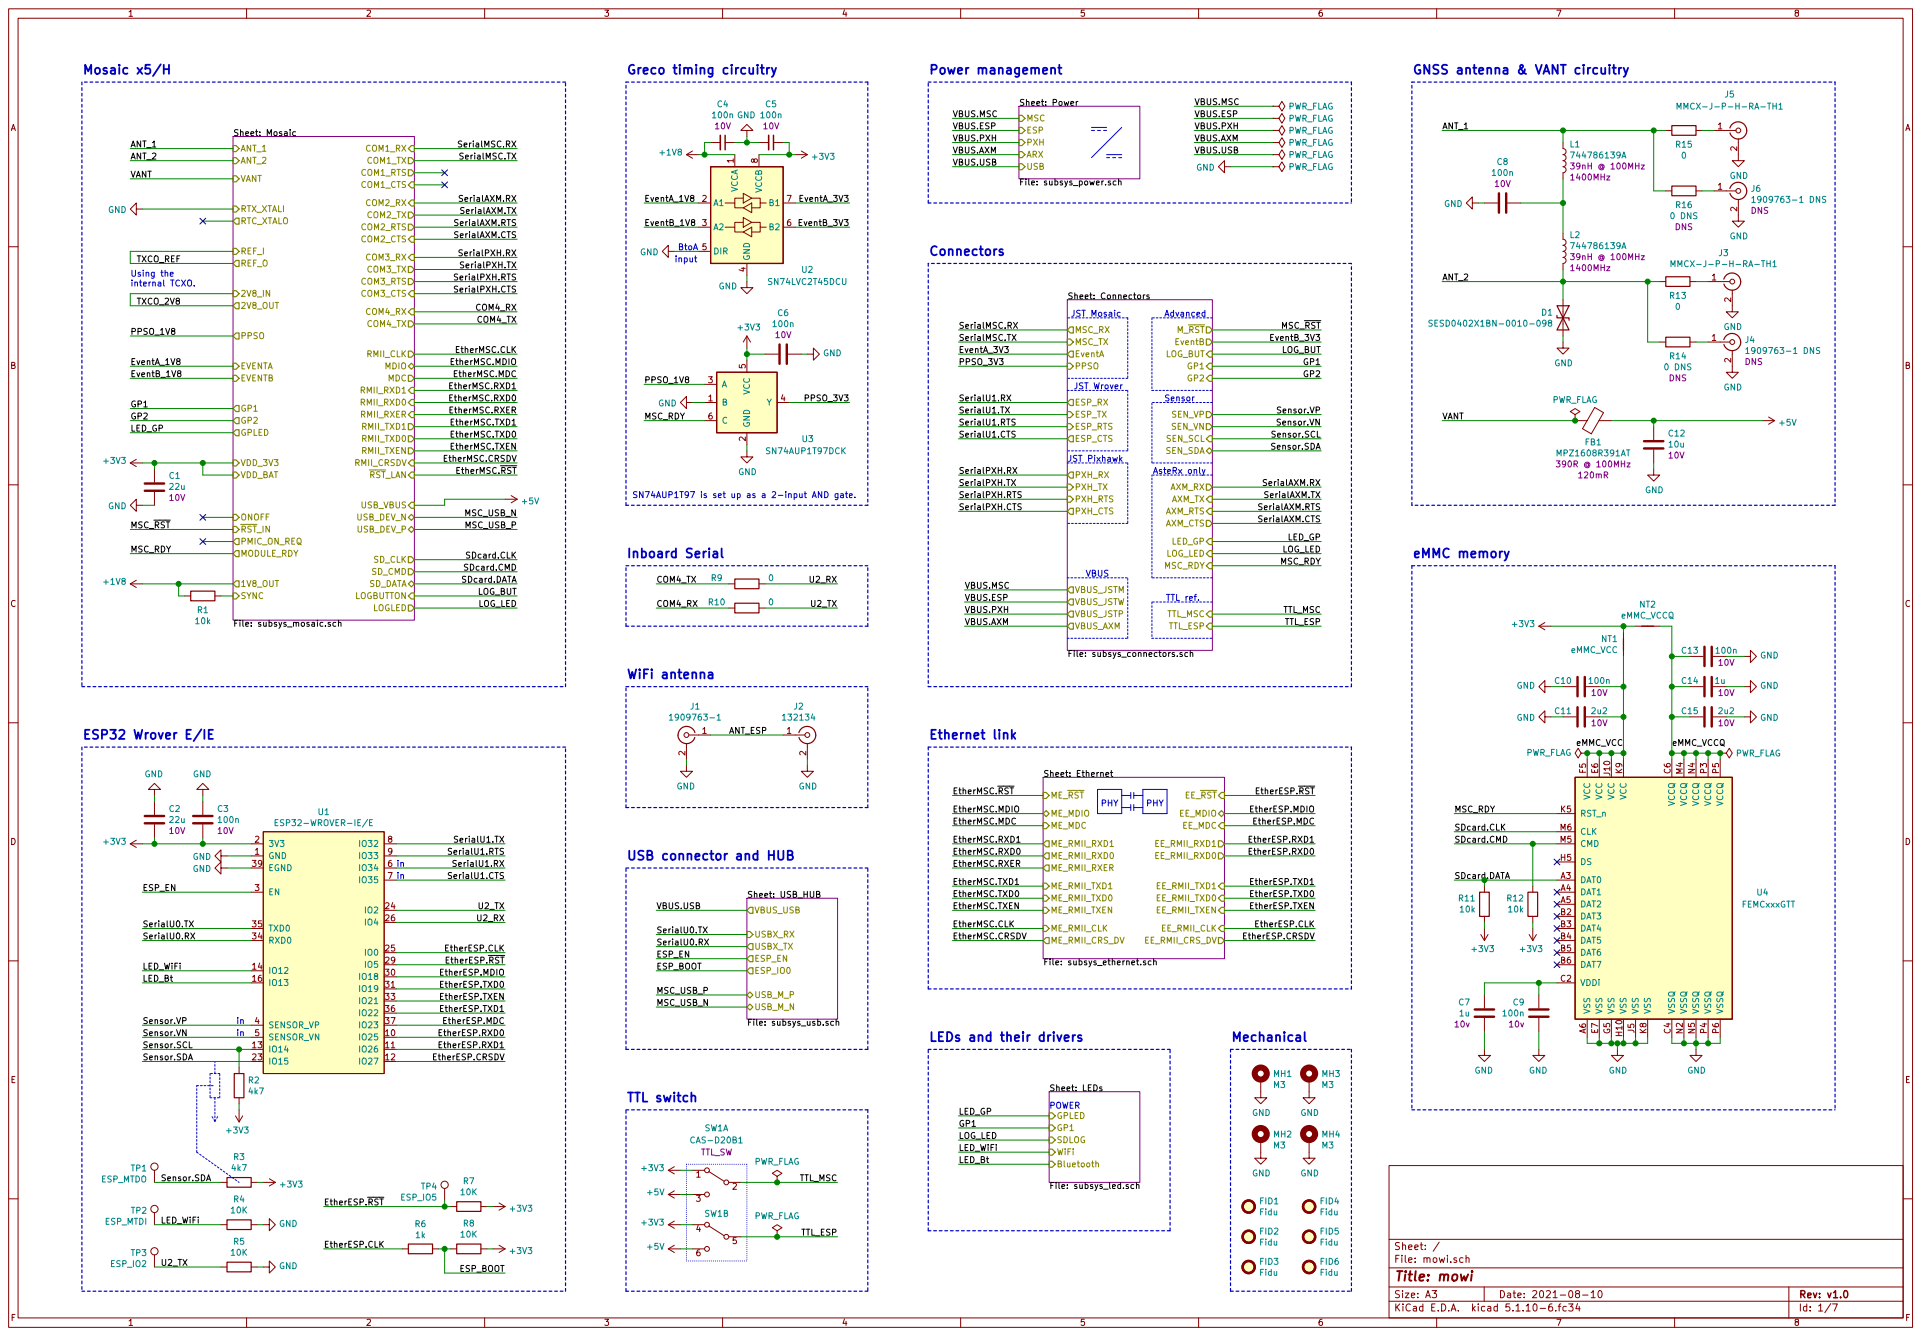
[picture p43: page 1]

Sheet: Mosaic File: subsys_mosaic.sch VDD_3V3 VDD_BAT REF_I 2V8_IN
VANT ANT_2 ANT_1 RTX_XTALI ONOFF RST_IN
COM4_TX COM3_RTS COM3_TX COM2_RTS COM2_TX COM1_RTS COM1_TX

GNSS antenna & VANT circuitry

Sheet: Power File: subsys_power.sch MSC

8 U2 SN74LVC2T45DCU
Advanced AsteRx only VBUS

J3 MMCX-J-P-H-RA-TH1 GND GND

SN74AUP1T97 is set up as a 2-input AND gate.
ESP_BOOT COM4_TX

TTL_MSC
TTL_ESP
Sheet: Ethernet File: subsys_ethernet.sch ME_RMII_TXEN ME_RMII_TXD0 ME_RMII_TXD1 ME_RMII_CLK
EtherESP.RST EtherESP.CRSDV

USB connector and HUB

EtherESP.RST EtherESP.MDC
EtherESP.MDIO

Sensor.VP
Sensor.SCL Sensor.VN

EtherESP.RXD1 EtherESP.RXD0 EtherESP.CRSDV

LEDs and their drivers

Sheet: LEDs File: subsys_led.sch Bluetooth WiFi GP1 GPLED

Id: 1/7 Title: mowi File: mowi.sch Sheet: /

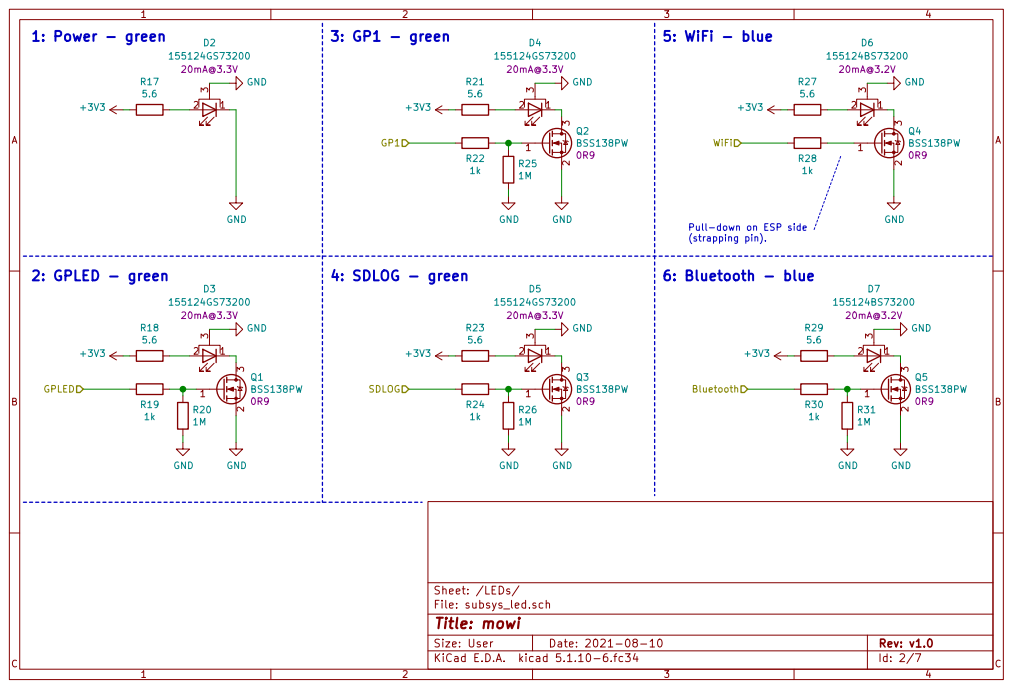
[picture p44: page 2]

Pull-down on ESP side
(strapping pin).

File: subsys_led.sch Sheet: /LEDs/ R19

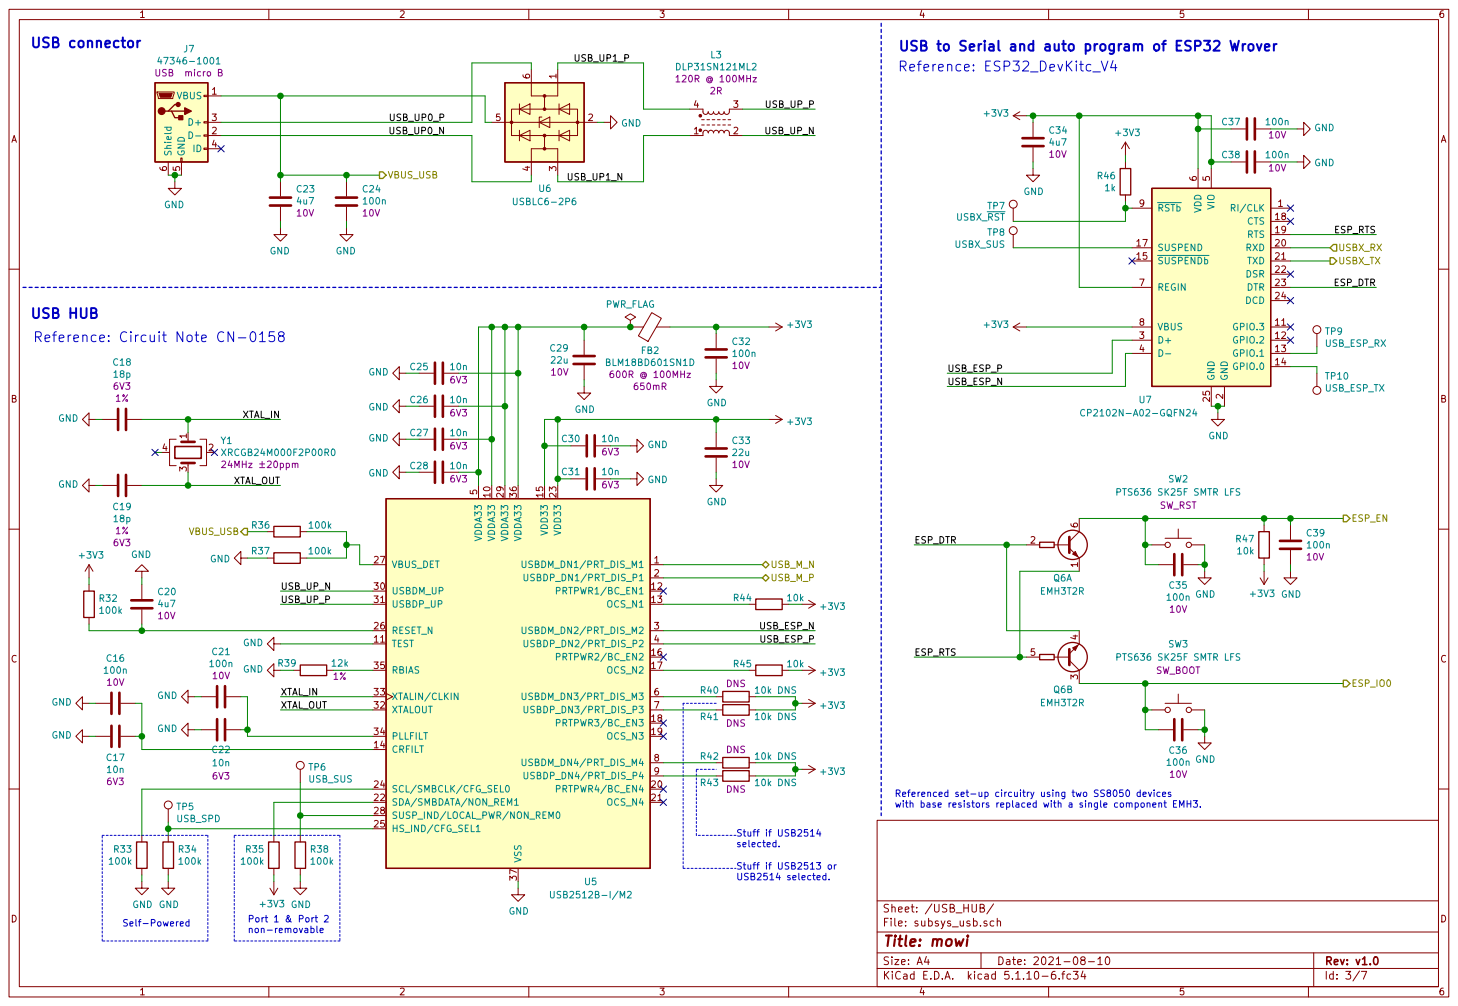
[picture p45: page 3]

non-removable Reference: Circuit Note CN-0158

6 REGIN 7 VBUS 8 RSTb 9U7 CP2102N-A02-GQFN24 GND

2 RXD 20 TXD 21 DSR 22 DTR 23 DCD 24 GND 25 D+ 3 D- 4 VIO

Referenced set-up circuitry using two SS8050 devices
with base resistors replaced with a single component EMH3.

Stuff if USB2513 or USB2514 selected.

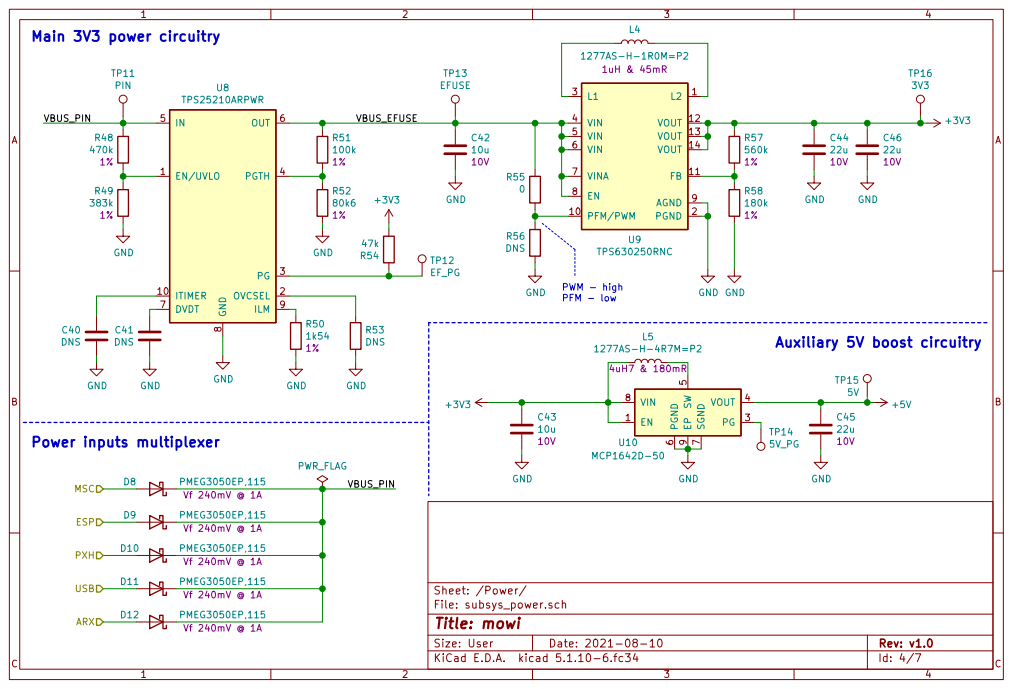
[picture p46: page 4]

PWM - high PFM - low Power inputs multiplexer

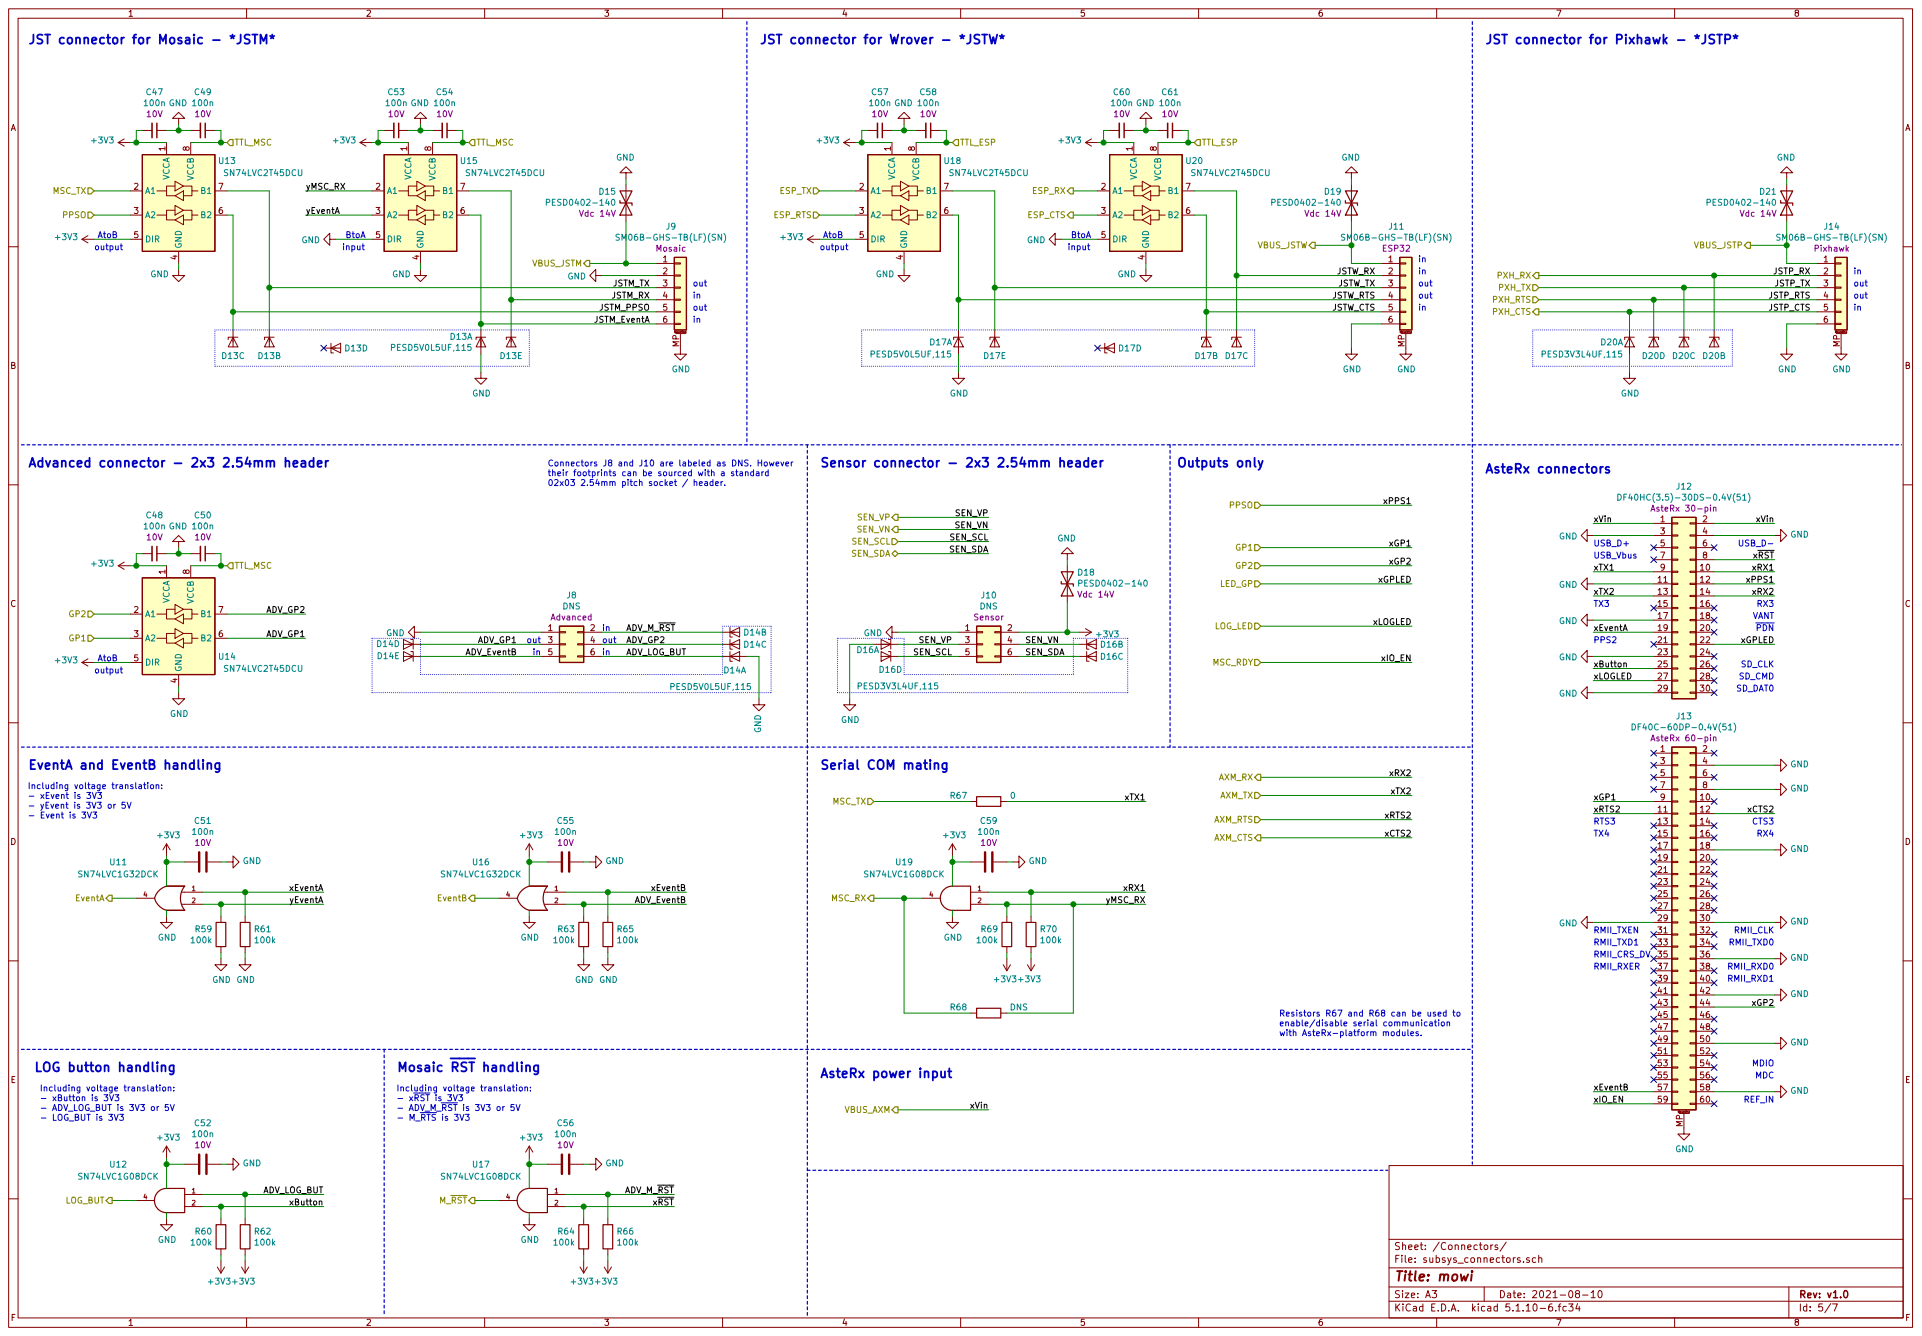
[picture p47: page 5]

JST connector for Mosaic - *JSTM*

JST connector for Pixhawk - *JSTP*

J14 SM06B-GHS-TB(LF)(SN) Pixhawk

02x03 2.54mm pitch socket / header. BtoA
input

out LOG button handling

AsteRx 60-pin GND GND

in Advanced connector - 2x3 2.54mm header AtoB

Connectors J8 and J10 are labeled as DNS. However
their footprints can be sourced with a standard

EventA and EventB handling

Including voltage translation: - xEvent is 3V3

enable/disable serial communication with AsteRx-platform modules.

Including voltage translation: - xButton is 3V3

Including voltage translation: - xRST is 3V3

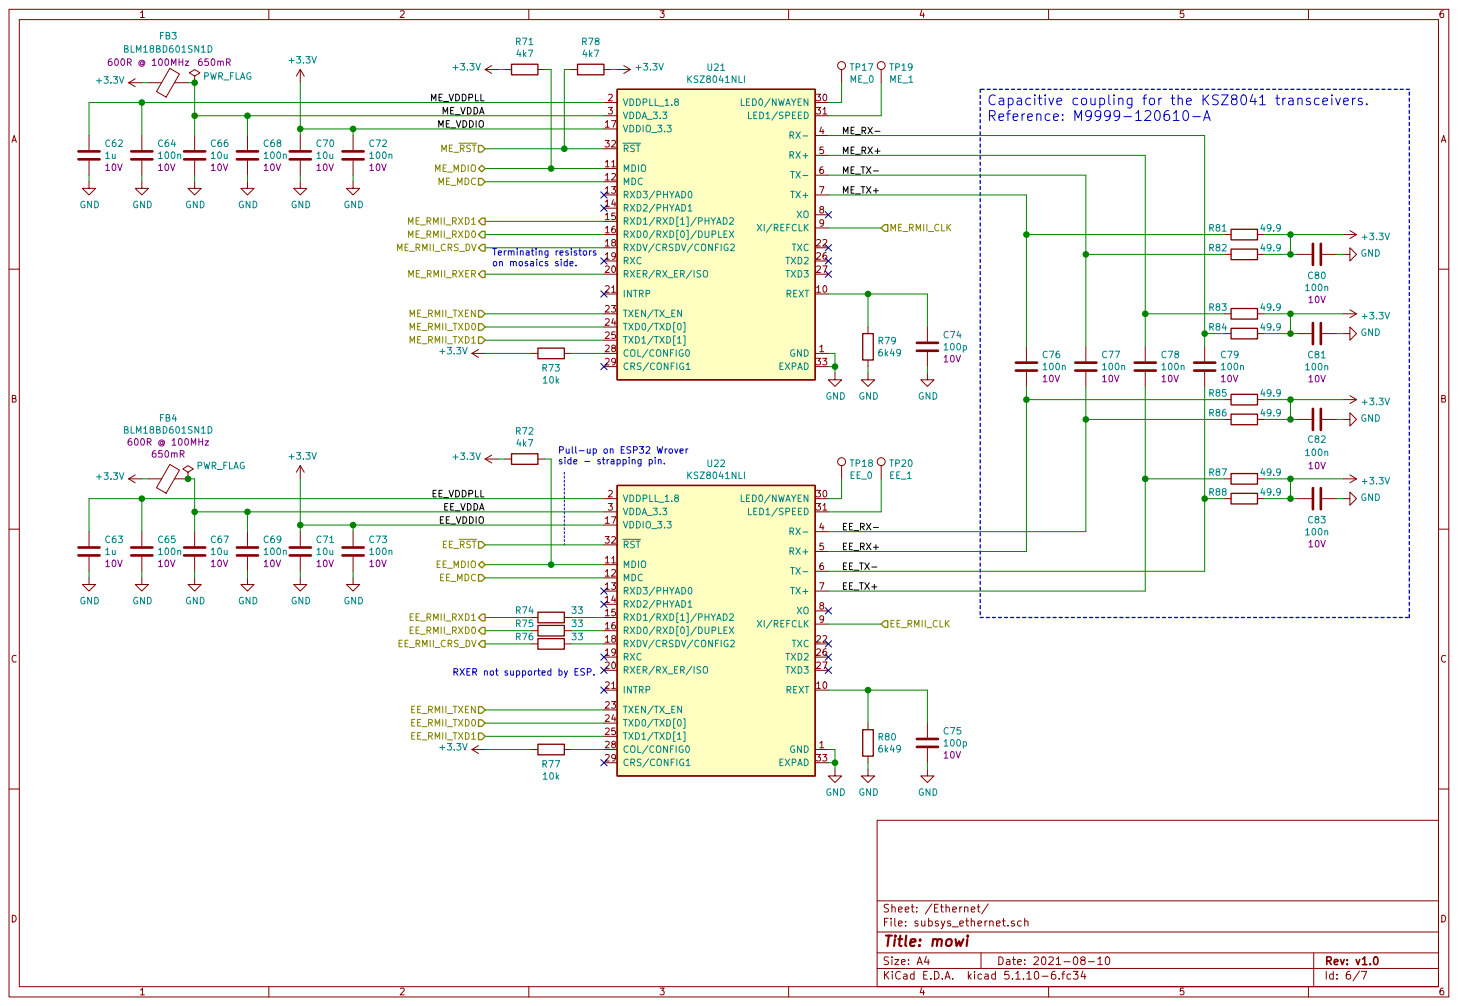
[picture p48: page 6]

EE_RST ME_MDC ME_RMII_CRS_DV ME_RMII_TXD0 ME_RMII_RXD1 ME_RMII_RXD0 ME_RMII_RXER ME_RST ME_RMII_TXEN ME_RMII_TXD1 EE_RMII_CRS_DV
Terminating resistors on mosaics side. RXER not supported by ESP.

Capacitive coupling for the KSZ8041 transceivers.
Reference: M9999-120610-A

EE_RX- EE_RX+ EE_TX- ME_TX- Pull-up on ESP32 Wrover

File: subsys_ethernet.sch Sheet: /Ethernet/ GND

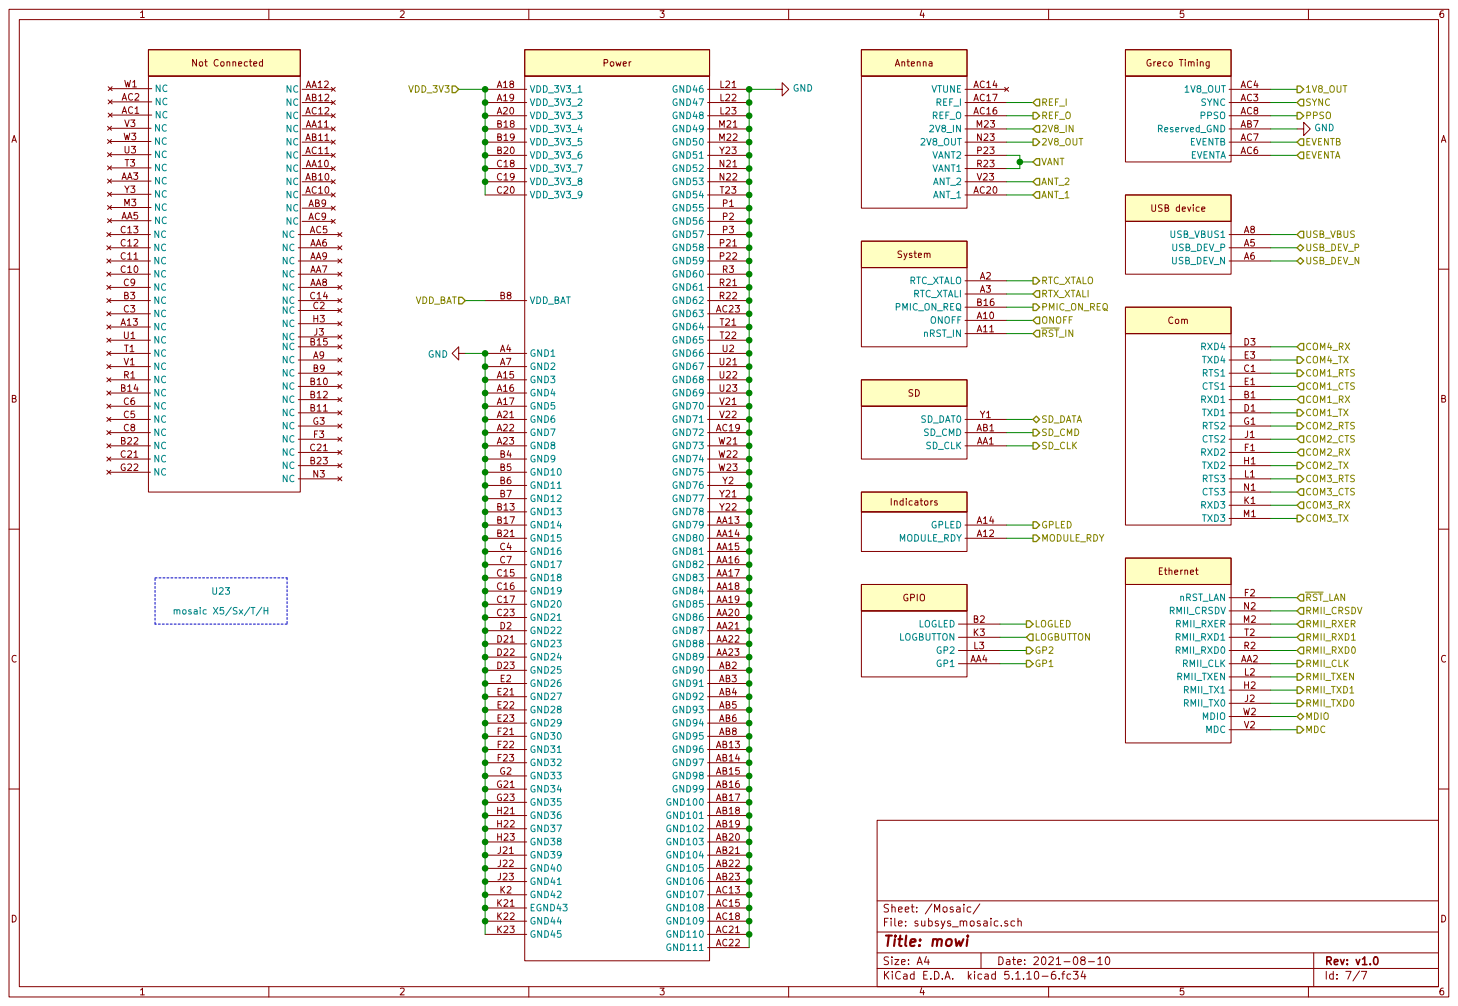
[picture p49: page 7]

File: subsys_mosaic.sch Sheet: /Mosaic/
Id: 7/7 Title: mowi

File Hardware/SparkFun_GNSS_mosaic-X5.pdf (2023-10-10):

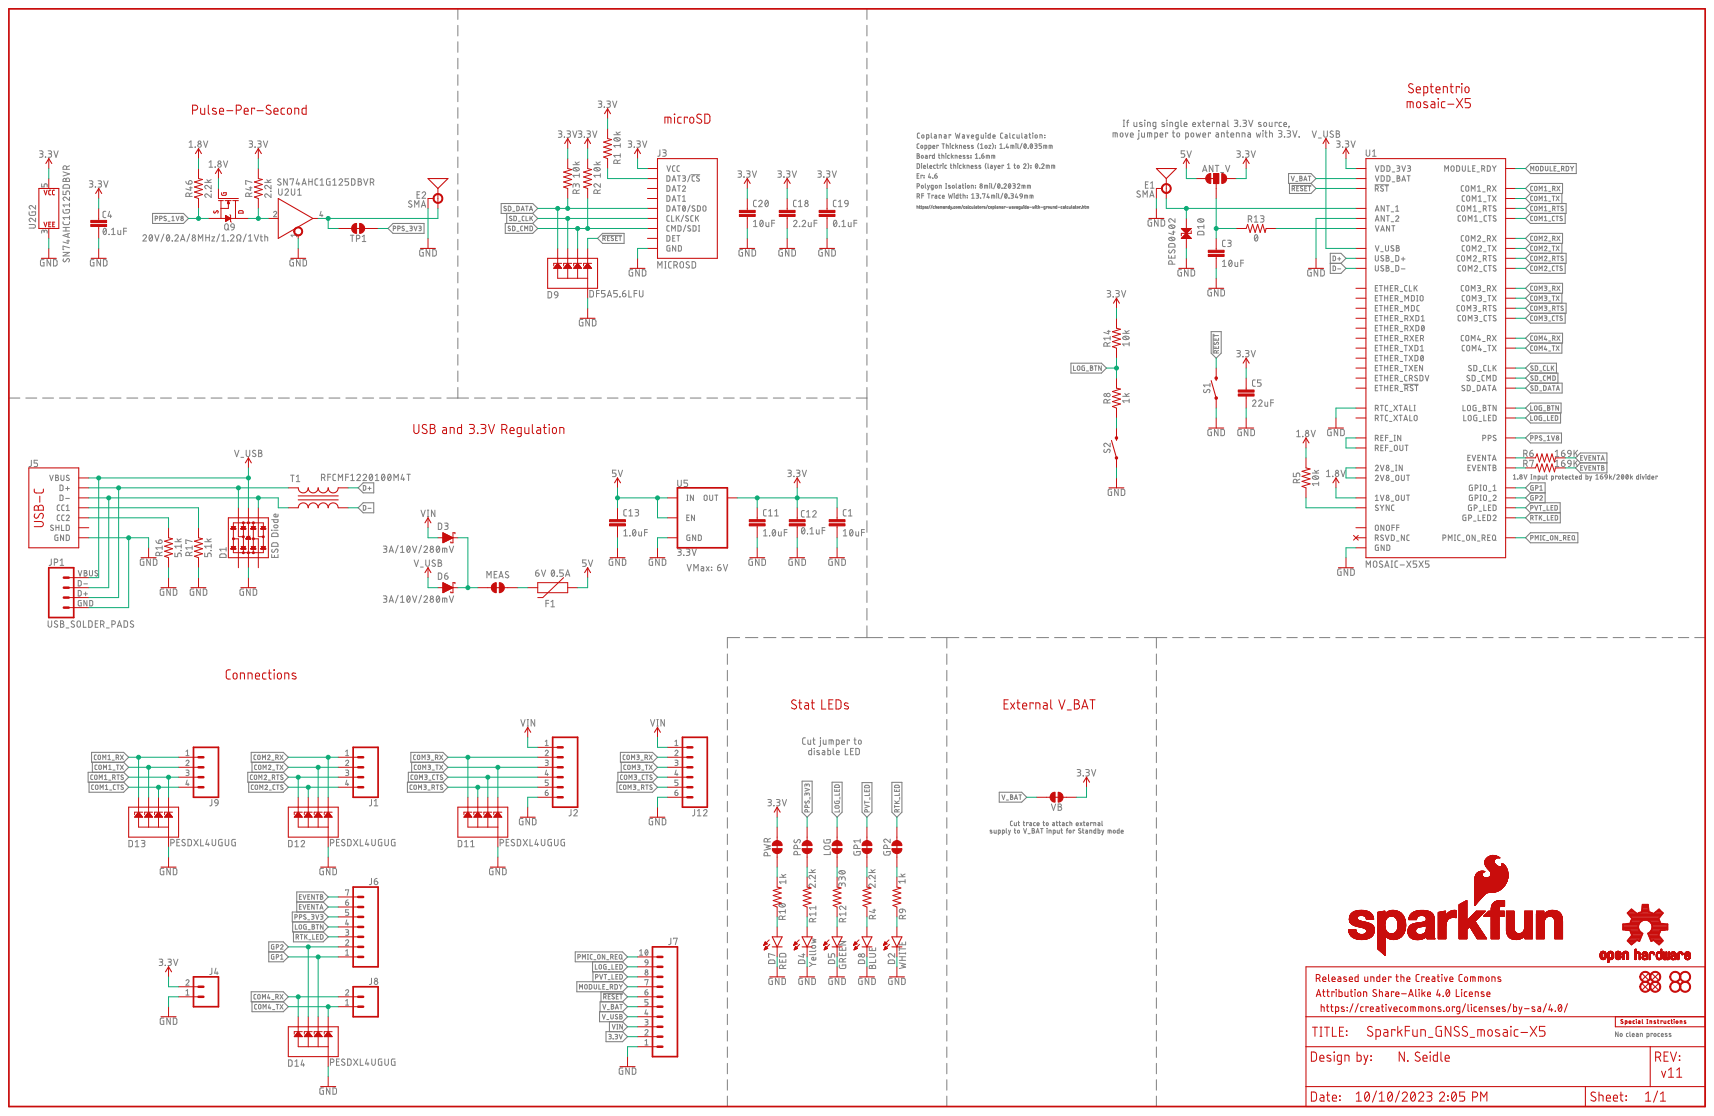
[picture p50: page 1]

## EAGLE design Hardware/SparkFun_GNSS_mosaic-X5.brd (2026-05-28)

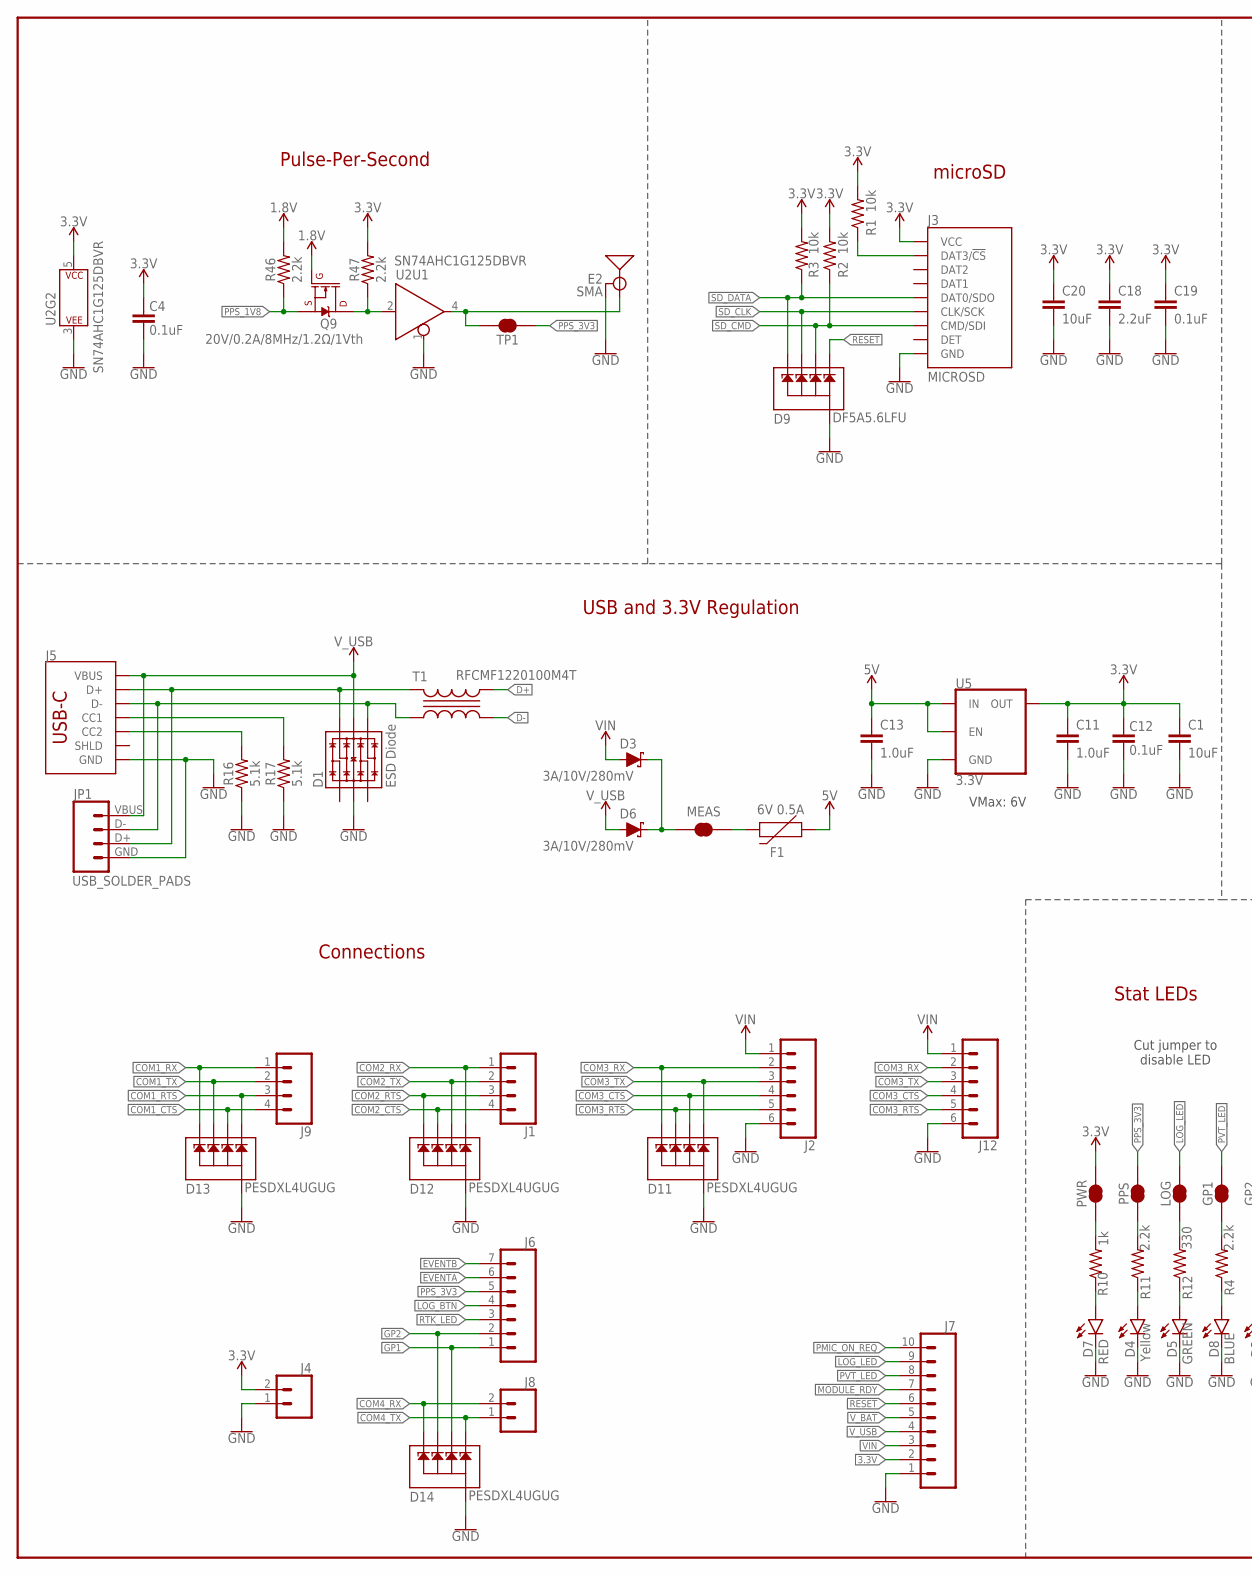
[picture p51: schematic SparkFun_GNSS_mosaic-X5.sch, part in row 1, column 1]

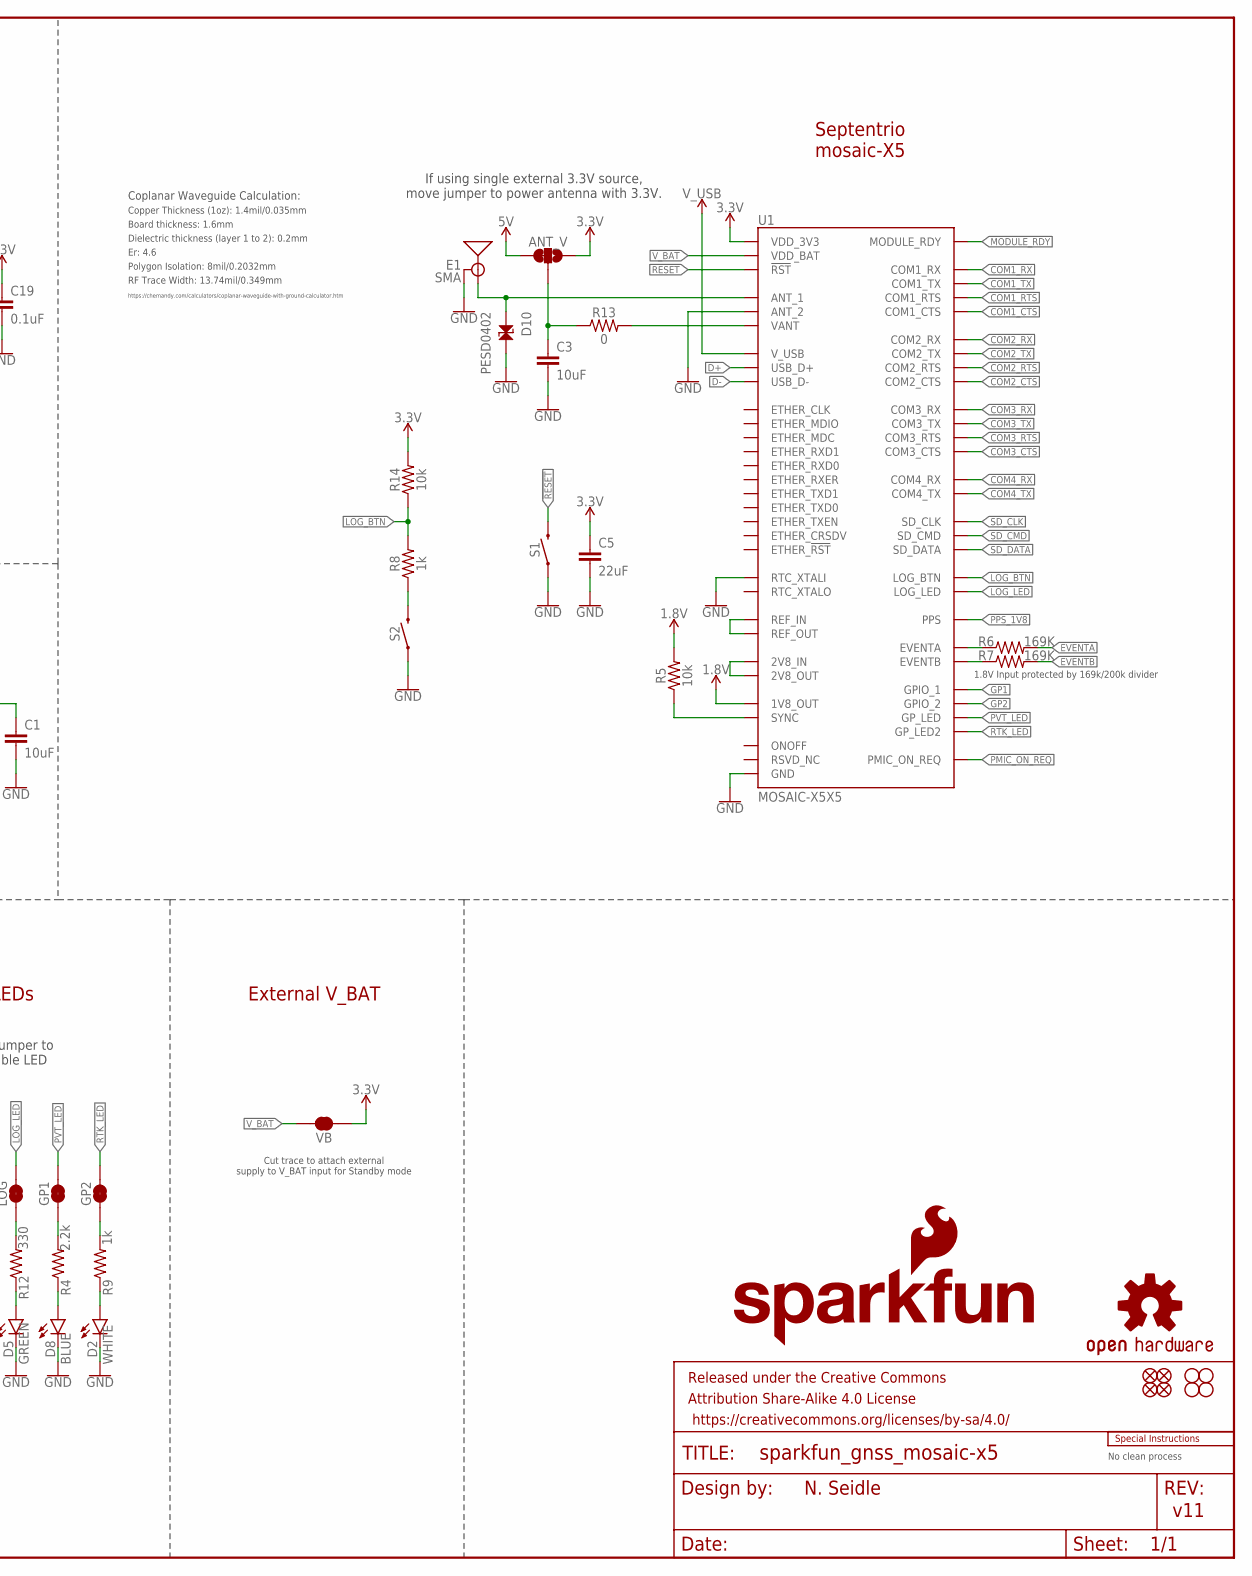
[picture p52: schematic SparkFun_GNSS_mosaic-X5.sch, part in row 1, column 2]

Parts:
ANT_V: JUMPER-SMT_3_1-NC_TRACE_SILK; SMT-JUMPER_3_1-NC_TRACE_SILK
C1, C3, C20: 10uF; 0603
C4, C12, C19: 0.1uF; 0603
C5: 22uF; 0603
C11, C13: 1.0uF; 0603
C18: 2.2uF; 0603
D1: ESD Diode; SOT-23-6
D2: WHITE; LED-0603
D3, D6: 3A/10V/280mV; SOD-323
D4: Yellow; LED-0603
D5: GREEN; LED-0603
D7: RED; LED-0603
D8: BLUE; LED-0603
D9: DF5A5.6LFU; SOT353
D10: PESD0402; 0402-TIGHT
D11, D12, D13, D14: PESDXL4UGUG; SOT353
E1, E2: SMA; SMA-EDGE
F1: 6V 0.5A; 0805
FRAME2: FRAME-LEDGER; CREATIVE_COMMONS
GP1, GP2: JUMPER-SMT_2_NC_TRACE_SILK; SMT-JUMPER_2_NC_TRACE_SILK
H1, H2, H3, H4: STAND-OFF
J1, J9: CONN_041X04_NO_SILK_NO_POP; 1X04_NO_SILK
J2: CONN_06JST-SMD-LOCKING; JST-6-SMD-1.25MM-LOCKING
J3: MICROSD; MICROSD-EXTERNALPIN
J4, J8: CONN_021X02_NO_SILK; 1X02_NO_SILK
J5: USB Female Type C Connector; USB-C-16P_4LAYER-PADS
J6: CONN_07NO_SILK; 1X07_NO_SILK
J7: CONN_10NO_SILK_PTH_FEMALE; 1X10_NO_SILK
J12: CONN_06PAD; 1X06_SOLDER_PADS
JP1: USB_SOLDER_PADS; USB-SOLDER-PADS
JP21, JP61, JP71, JP81: FIDUCIALUFIDUCIAL; FIDUCIAL-MICRO
LOG: JUMPER-SMT_2_NC_TRACE_SILK; SMT-JUMPER_2_NC_TRACE_SILK
LOGO2: OSHW-LOGOMINI; OSHW-LOGO-MINI
LOGO4: SFE_LOGO_NAME_FLAME10_MM; SFE_LOGO_NAME_FLAME_10MM
MEAS: JUMPER-COMBO_2_NC_TRACE; COMBO-JUMPER_2_NC_TRACE
PPS: JUMPER-SMT_2_NC_TRACE_SILK; SMT-JUMPER_2_NC_TRACE_SILK
PWR: JUMPER-SMT_2_NC_TRACE_SILK; SMT-JUMPER_2_NC_TRACE_SILK
Q9: 20V/0.2A/8MHz/1.2Ω/1Vth; SOT-416FL
R1, R2, R3, R5, R14: 10k; 0603
R4, R11, R46, R47: 2.2k; 0603
R6, R7: 169K; 0603
R8, R9, R10: 1k; 0603
R12: 330; 0603
R13: 0; 0603
R16, R17: 5.1k; 0603
S1: MOMENTARY-SWITCH-SPST-SMD-4.6X2.8MM; TACTILE_SWITCH_SMD_4.6X2.8MM
S2: MOMENTARY-SWITCH-SPST-SMD-5.2-TALL-REDUNDANT; TACTILE_SWITCH_SMD_5.2MM
T1: RFCMF1220100M4T
TP1: JUMPER-SMT_2_NC_TRACE_SILK; SMT-JUMPER_2_NC_TRACE_SILK
U1: MOSAIC-X5X5; MOSAIC_LGA
U2: SN74AHC1G125DBVR; SOT23-5
U5: 3.3V; SOT23-5
U$2: SPECIAL_INSTRUCTIONS-ORDERING; ORDERING_INSTRUCTIONS
VB: JUMPER-SMT_2_NC_TRACE_SILK; SMT-JUMPER_2_NC_TRACE_SILK

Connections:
1.8V: Q9.1 (G), R5.2, R46.2, U1.AC4 (1V8_OUT)
3.3V: ANT_V.1, C1.1, C4.2, C5.1, C11.1, C12.2, C18.1, C19.1, C20.1, J3.4 (VCC), J4.2, J7.2, PWR.2, R1.2, R2.2, R3.2, R14.2, R47.2, U1.A18 (VDD_3V3), U1.A19 (VDD_3V3), U1.A20 (VDD_3V3), U1.B18 (VDD_3V3), U1.B19 (VDD_3V3), U1.B20 (VDD_3V3), U1.C18 (VDD_3V3), U1.C19 (VDD_3V3), U1.C20 (VDD_3V3), U2.5 (P$V+), U5.5 (OUT), VB.1
5V: ANT_V.3, C13.1, F1.1, U5.1 (IN), U5.3 (EN)
!RESET!: D9.3, J7.6, S1.3 (2), S1.4 (2), U1.A11 (!RST!)
ANT_V: ANT_V.2, C3.1, R13.1
CC1: J5.A5 (CC1), R17.2
CC2: J5.B5 (CC2), R16.2
COM1_CTS: D13.4, J9.4, U1.E1 (COM1_CTS)
COM1_RTS: D13.3, J9.3, U1.C1 (COM1_RTS)
COM1_RX: D13.1, J9.1, U1.B1 (COM1_RX)
COM1_TX: D13.5, J9.2, U1.D1 (COM1_TX)
COM2_CTS: D12.5, J1.4, U1.J1 (COM2_CTS)
COM2_RTS: D12.1, J1.3, U1.G1 (COM2_RTS)
COM2_RX: D12.3, J1.1, U1.F1 (COM2_RX)
COM2_TX: D12.4, J1.2, U1.H1 (COM2_TX)
COM3_CTS: D11.4, J2.4, J12.4, U1.N1 (COM3_CTS)
COM3_RTS: D11.5, J2.5, J12.5, U1.L1 (COM3_RTS)
COM3_RX: D11.1, J2.2, J12.2, U1.K1 (COM3_RX)
COM3_TX: D11.3, J2.3, J12.3, U1.M1 (COM3_TX)
COM4_RX: D14.1, J8.2, U1.D3 (COM4_RX)
COM4_TX: D14.3, J8.1, U1.E3 (COM4_TX)
D+: T1.B2, U1.A5 (USB_D+)
D-: T1.A2, U1.A6 (USB_D-)
EVENTA: J6.6, R6.2
EVENTB: J6.7, R7.2
GND: C1.2, C3.2, C4.1, C5.2, C11.2, C12.1, C13.2, C18.2, C19.2, C20.2, D1.2 (VSS), D2.C, D4.C, D5.C, D7.C, D8.C, D9.2, D10.2, D11.2, D12.2, D13.2, D14.2, E1.GND@0 (GND), E1.GND@1 (GND), E1.GND@2 (GND), E1.GND@3 (GND), E2.GND@0 (GND), E2.GND@1 (GND), E2.GND@2 (GND), E2.GND@3 (GND), J2.6, J3.6 (GND), J3.10 (GND), J3.11 (GND), J3.12 (GND), J3.13 (GND), J4.1, J5.GND, J5.GND2 (GND), J7.1, J12.6, JP1.GND (4), R16.1, R17.1, S1.1, S1.2 (1), S2.1, S2.2 (1), U1.A3 (RTC_XTALI), U1.A4 (GND), U1.A7 (GND), U1.A15 (GND), U1.A16 (GND), U1.A17 (GND), U1.A21 (GND), U1.A22 (GND), U1.A23 (GND), U1.AA13 (GND), U1.AA14 (GND), U1.AA15 (GND), U1.AA16 (GND), U1.AA17 (GND), U1.AA18 (GND), U1.AA19 (GND), U1.AA20 (GND), U1.AA21 (GND), U1.AA22 (GND), U1.AA23 (GND), U1.AB2 (GND), U1.AB3 (GND), U1.AB4 (GND), U1.AB5 (GND), U1.AB6 (GND), U1.AB7 (GND), U1.AB8 (GND), U1.AB13 (GND), U1.AB14 (GND), U1.AB15 (GND), U1.AB16 (GND), U1.AB17 (GND), U1.AB18 (GND), U1.AB19 (GND), U1.AB20 (GND), U1.AB21 (GND), U1.AB22 (GND), U1.AB23 (GND), U1.AC13 (GND), U1.AC15 (GND), U1.AC18 (GND), U1.AC19 (GND), U1.AC21 (GND), U1.AC22 (GND), U1.AC23 (GND), U1.B4 (GND), U1.B5 (GND), U1.B6 (GND), U1.B7 (GND), U1.B13 (GND), U1.B17 (GND), U1.B21 (GND), U1.C4 (GND), U1.C7 (GND), U1.C15 (GND), U1.C16 (GND), U1.C17 (GND), U1.C23 (GND), U1.D2 (GND), U1.D21 (GND), U1.D22 (GND), U1.D23 (GND), U1.E2 (GND), U1.E21 (GND), U1.E22 (GND), U1.E23 (GND), U1.F21 (GND), U1.F22 (GND), U1.F23 (GND), U1.G2 (GND), U1.G21 (GND), U1.G23 (GND), U1.H21 (GND), U1.H22 (GND), U1.H23 (GND), U1.J21 (GND), U1.J22 (GND), U1.J23 (GND), U1.K2 (GND), U1.K21 (GND), U1.K22 (GND), U1.K23 (GND), U1.L21 (GND), U1.L22 (GND), U1.L23 (GND), U1.M21 (GND), U1.M22 (GND), U1.N21 (GND), U1.N22 (GND), U1.P1 (GND), U1.P2 (GND), U1.P3 (GND), U1.P21 (GND), U1.P22 (GND), U1.R3 (GND), U1.R21 (GND), U1.R22 (GND), U1.T21 (GND), U1.T22 (GND), U1.T23 (GND), U1.U2 (GND), U1.U21 (GND), U1.U22 (GND), U1.U23 (GND), U1.V21 (GND), U1.V22 (GND), U1.V23 (ANT_2), U1.W21 (GND), U1.W22 (GND), U1.W23 (GND), U1.Y2 (GND), U1.Y21 (GND), U1.Y22 (GND), U1.Y23 (GND), U2.1 (!EN), U2.3 (P$V-), U5.2 (GND)
GP1: D14.4, J6.1, U1.AA4 (GPIO_1)
GP2: D14.5, J6.2, U1.L3 (GPIO_2)
GPS_ANT1: D10.1, E1.SIG (SIGNAL), U1.AC20 (ANT_1)
LOG_BTN: J6.4, R8.2, R14.1, U1.K3 (LOG_BTN)
LOG_LED: J7.9, LOG.2, U1.B2 (LOG_LED)
MEAS: D3.C, D6.C, MEAS.2, MEAS.4 (2)
MODULE_RDY: J7.7, U1.A12 (MODULE_RDY)
unnamed: R8.1, S2.3 (2), S2.4 (2)
unnamed: D4.A, R11.1
unnamed: PPS.1, R11.2
unnamed: F1.2, MEAS.1, MEAS.3 (1)
unnamed: J3.2 (DAT3/!CS!), R1.1
unnamed: R6.1, U1.AC6 (EVENTA)
unnamed: R7.1, U1.AC7 (EVENTB)
unnamed: D2.A, R9.1
unnamed: GP2.1, R9.2
unnamed: U1.AC16 (REF_OUT), U1.AC17 (REF_IN)
unnamed: D8.A, R4.1
unnamed: GP1.1, R4.2
unnamed: D7.A, R10.1
unnamed: U1.M23 (2V8_IN), U1.N23 (2V8_OUT)
unnamed: D5.A, R12.1
unnamed: LOG.1, R12.2
unnamed: PWR.1, R10.2
unnamed: R5.1, U1.AC3 (SYNC)
PMIC_ON_REQ: J7.10, U1.B16 (PMIC_ON_REQ)
PPS: E2.SIG (SIGNAL), TP1.2, U2.4 (Y)
PPS_1V8: Q9.2 (S), R46.1, U1.AC8 (PPS)
PPS_3: Q9.3 (D), R47.1, U2.2 (A)
PPS_3V3: J6.5, PPS.2, TP1.1
PVT_LED: GP1.2, J7.8, U1.A14 (GP_LED)
RTK_LED: GP2.2, J6.3, U1.M3 (GP_LED2)
SD_CLK: D9.5, J3.5 (CLK/SCK), U1.AA1 (SD_CLK)
SD_CMD: D9.4, J3.3 (CMD/SDI), R2.1, U1.AB1 (SD_CMD)
SD_DATA: D9.1, J3.7 (DAT0/SDO), R3.1, U1.Y1 (SD_DATA)
USB_D+: D1.6 (IO4), J5.A6 (D+), J5.B6 (D+), JP1.D+ (3), T1.B1
USB_D-: D1.4 (IO3), J5.A7 (D-), J5.B7 (D-), JP1.D- (2), T1.A1
VANT: R13.2, U1.P23 (VANT), U1.R23 (VANT)
VIN: D3.A, J2.1, J7.3, J12.1
V_BAT: J7.5, U1.B8 (VDD_BAT), VB.2
V_USB: D1.5 (VCC), D6.A, J5.VBUS1 (VBUS), J5.VBUS2 (VBUS), J7.4, JP1.VBUS (1), U1.A8 (V_USB)

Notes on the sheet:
v11
Board thickness: 1.6mm
Er: 4.6
Copper Thickness (1oz): 1.4mil/0.035mm
RF Trace Width: 13.74mil/0.349mm
Polygon Isolation: 8mil/0.2032mm
No clean process
Dielectric thickness (layer 1 to 2): 0.2mm
https://chemandy.com/calculators/coplanar-waveguide-with-ground-calculator.htm
Coplanar Waveguide Calculation:
USB and 3.3V Regulation
N. Seidle
Cut jumper to disable LED
Stat LEDs
Connections
microSD
Pulse-Per-Second
External V_BAT
Cut trace to attach external supply to V_BAT input for Standby mode
Septentrio mosaic-X5
1.8V Input protected by 169k/200k divider
VMax: 6V
If using single external 3.3V source, move jumper to power antenna with 3.3V.

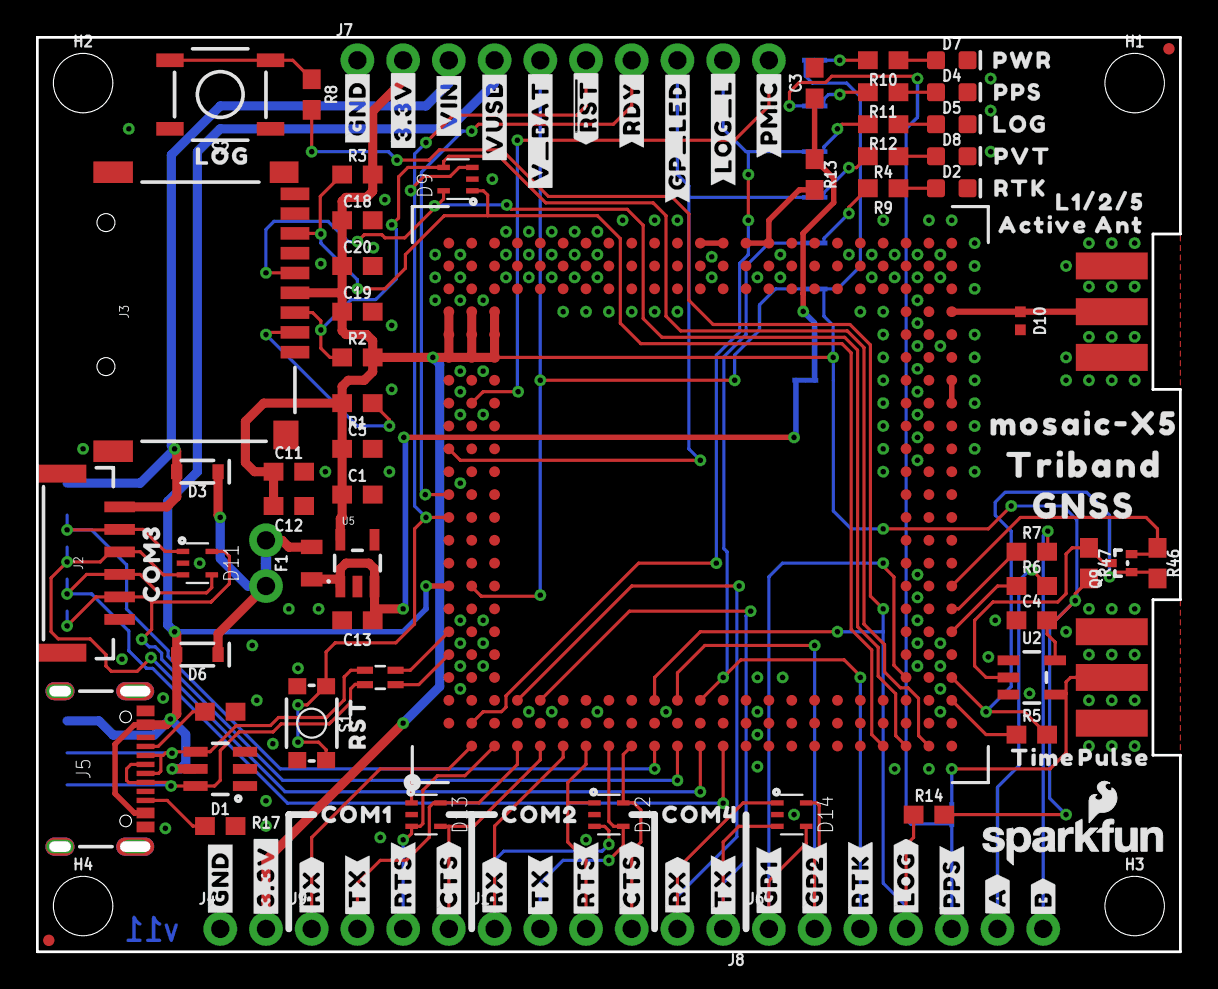
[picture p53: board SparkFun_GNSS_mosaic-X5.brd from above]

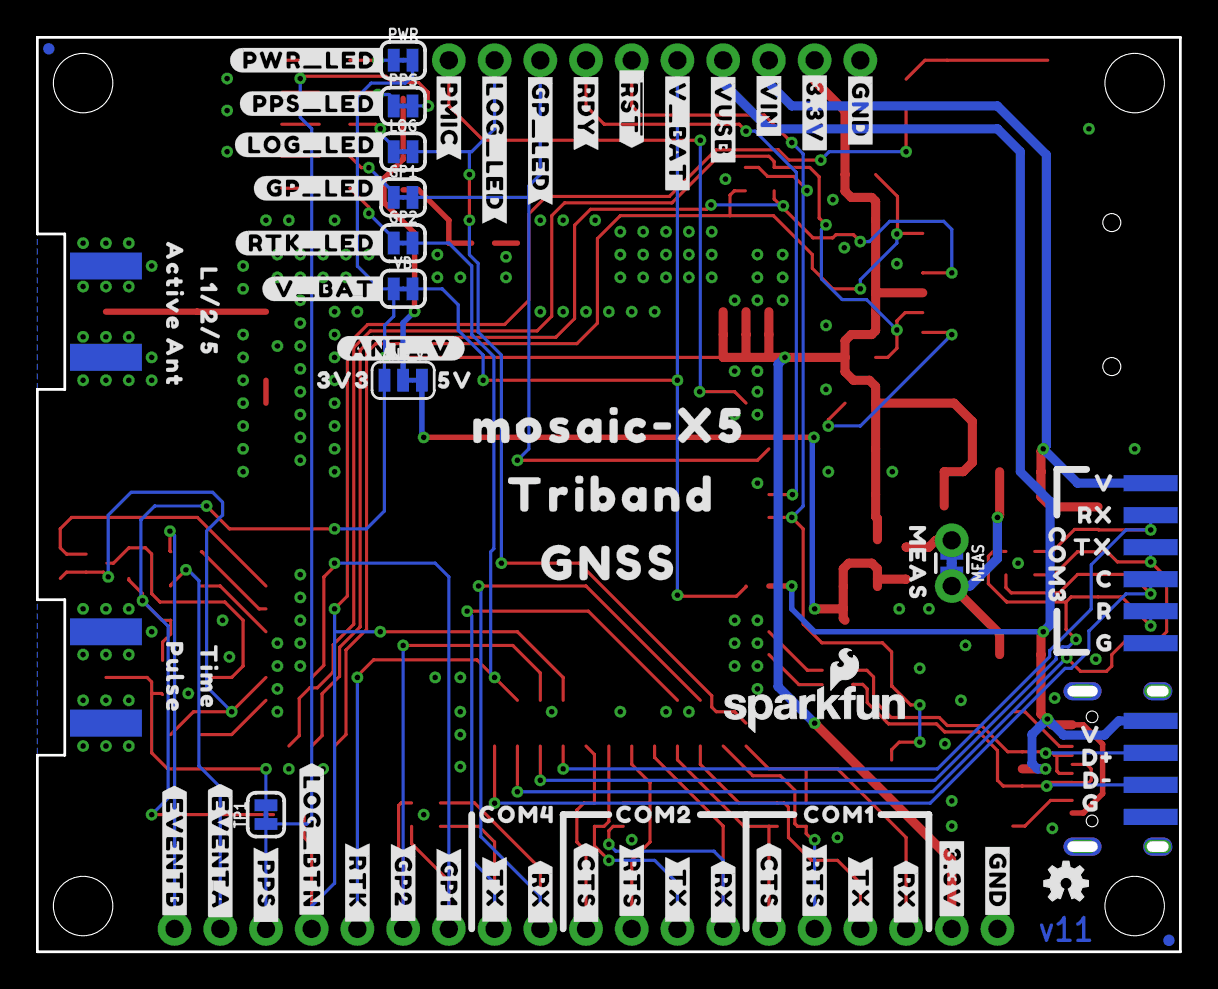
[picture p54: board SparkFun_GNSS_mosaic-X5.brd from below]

Board: 4 copper layers, 63.5 x 50.8 mm, 192 parts (75 on the bottom side), 67 nets.

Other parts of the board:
LOGO1: SFE_LOGO_NAME_FLAME10_MM; SFE_LOGO_NAME_FLAME_10MM
U$1: V0
U$3: GNSS_1
U$4: TRIBAND_2
U$5: MEAS0
U$6, U$135: _ACTIVE_ANT1
U$7: #RTK#0
U$8: C4
U$9: D#2
U$10: D#3
U$11: G0
U$12: R5
U$13: RST0
U$14: RX7
U$15: TX6
U$16: V8
U$17: #EVENTA#0
U$18, U$82: COM30
U$19: MOSAIC#X50
U$20: MOSAIC#X5_0
U$21, U$136: TIME0
U$22: G1
U$23: 3V30
U$24: 5V0
U$25, U$137: PULSE1
U$26: #ANT_V#0
U$27: #RTK_LED#0
U$28: RTK0
U$29: PVT0
U$30: #GP1_#0
U$31: LOG0
U$33: #GP2_#0
U$34: #PPS_#0
U$35: #LOG_BTN#0
U$36: #LOG_L#0
U$37: #RDY#0
U$38: #GP_LED#0
U$39: #LOG_LED#0
U$40: #PMIC#0
U$41, U$42: #RTS#0
U$43: #RTK_#0
U$44: #EVENTB#0
U$69, U$134: L1#2#50
U$79: LOG2
U$80: PPS0
U$81: PWR3
U$83, U$99: COM20
U$84, U$109: COM10
U$85, U$108: COM40
U$87, U$93, U$110, U$114: #3#3V#1
U$88, U$100: #CTS#4
U$89, U$95, U$113, U$117: #GND#0
U$90, U$101: #RTS#5
U$91, U$102, U$111: #RX#2
U$92, U$103, U$112: #TX#3
U$94, U$104: #CTS_#4
U$97, U$106, U$115: #RX_#2
U$98, U$107, U$116: #TX_#3
U$118: ##RST##2
U$119: #GP_LED#4
U$121: #PMIC#6
U$122: #RDY#3
U$123, U$130: #VIN#1
U$124, U$131: #VUSB#0
U$125, U$132: #V_BAT#7
U$133: #_#RST##2
U$138: GNSS1
U$140: TRIBAND2
U$141: #LOG_LED#2
U$142: #PPS_LED#1
U$143: #GP_LED#3
U$144: #PWR_LED#0
U$145: #V_BAT#4
U$146: #A#8
U$147: #B#10
U$150: #GP1#0
U$152: #GP2#1
U$154: #LOG#4
U$156: #PPS#6

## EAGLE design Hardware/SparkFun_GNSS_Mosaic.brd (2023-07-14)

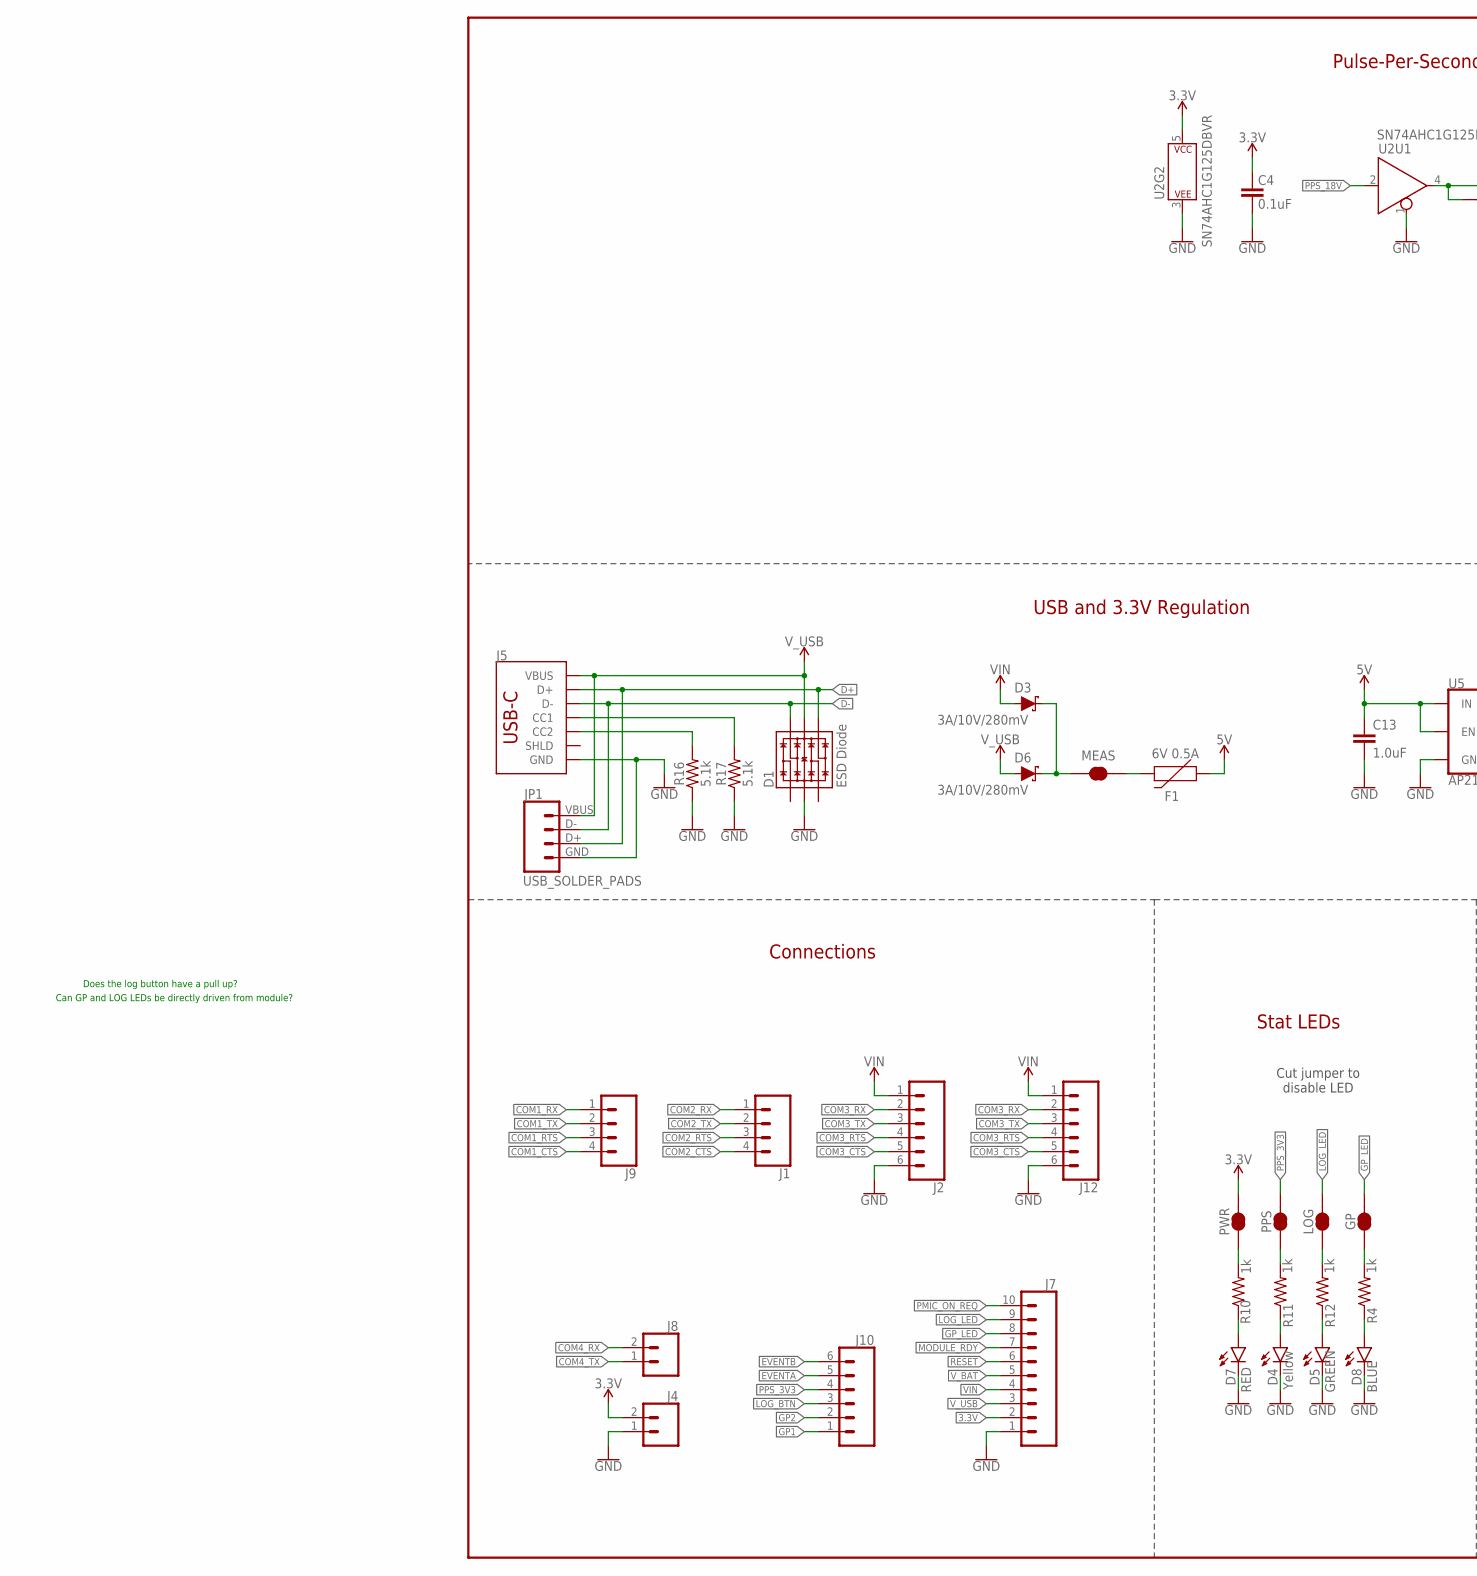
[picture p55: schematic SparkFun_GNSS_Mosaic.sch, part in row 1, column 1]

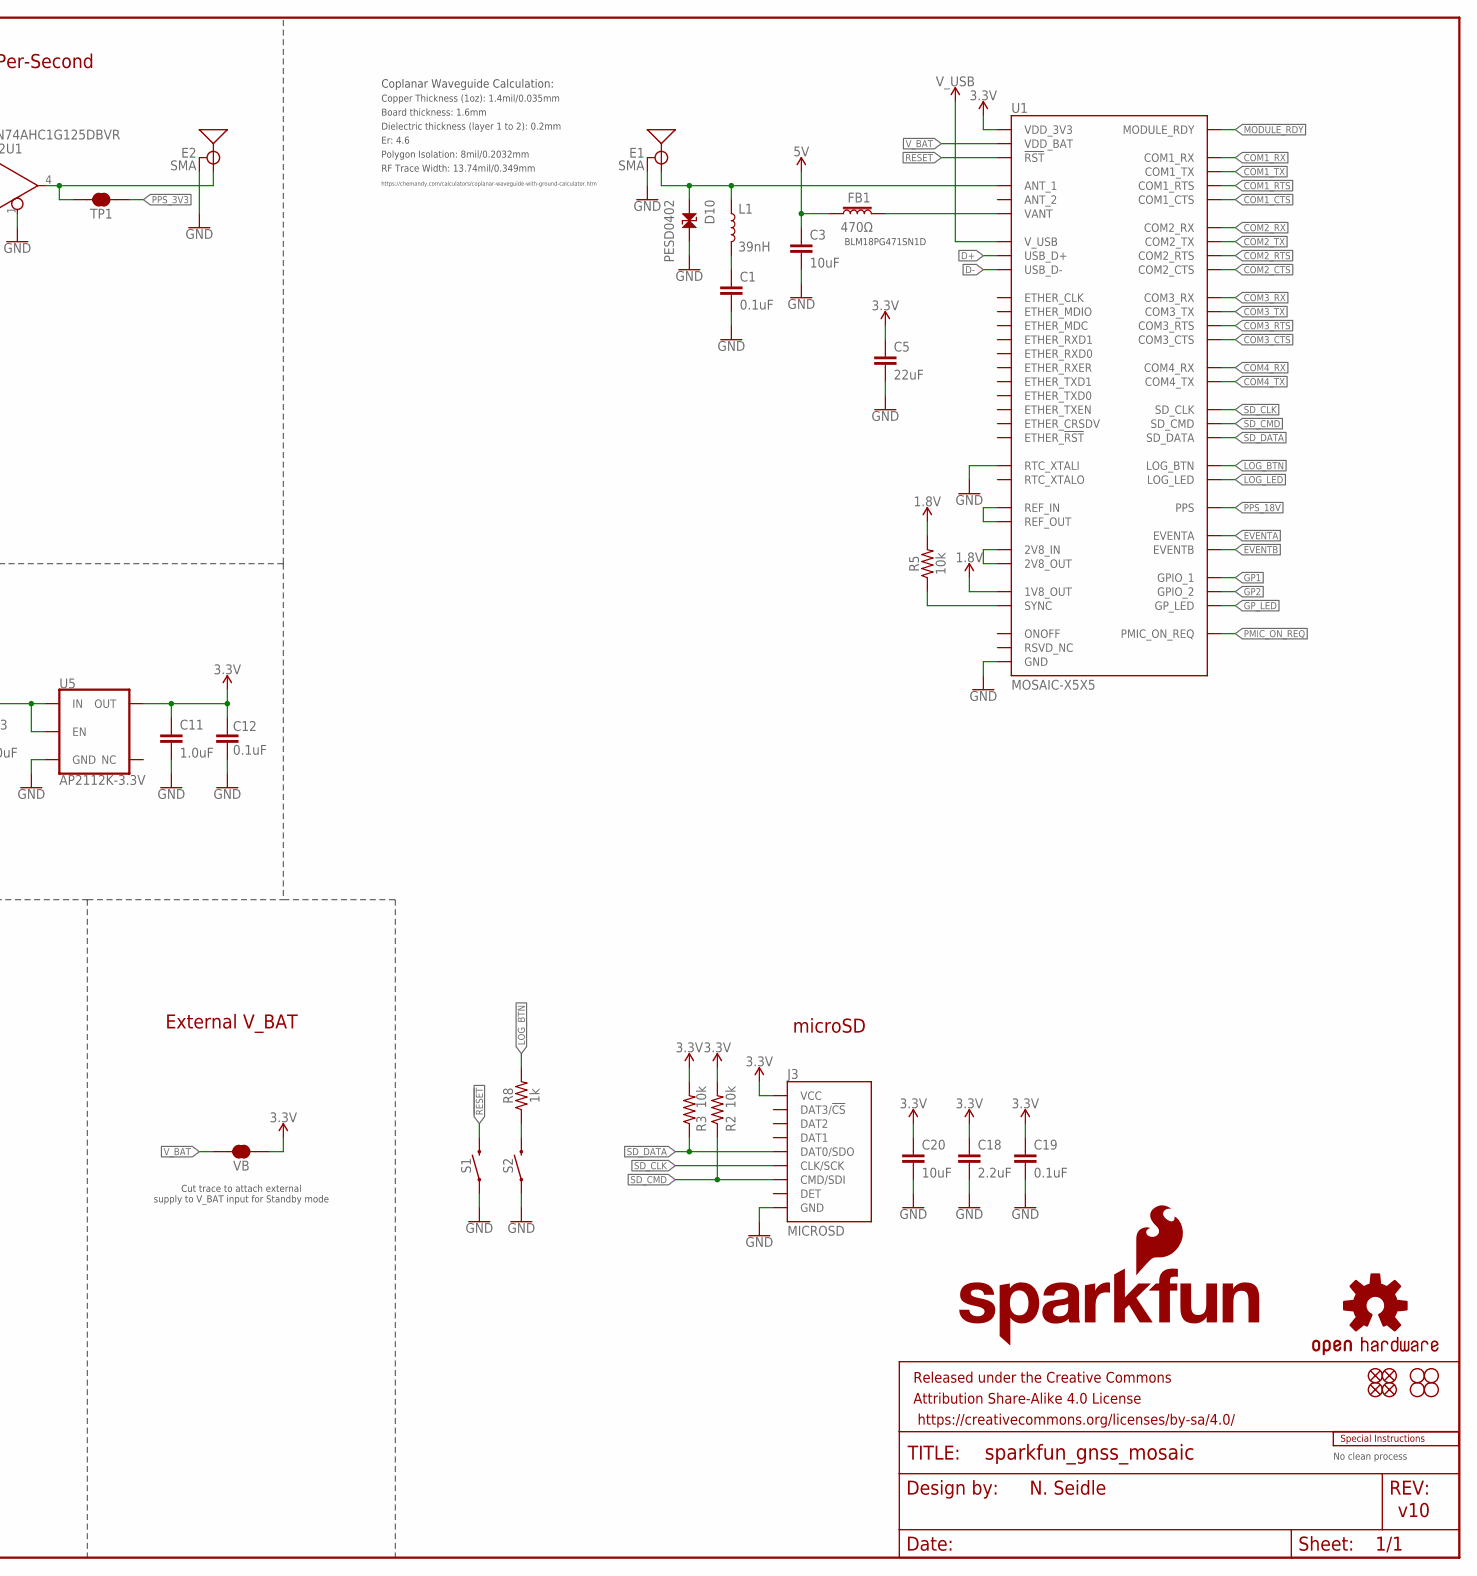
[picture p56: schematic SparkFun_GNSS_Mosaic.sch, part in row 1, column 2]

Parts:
C1, C4, C12, C19: 0.1uF; 0603
C3, C20: 10uF; 0603
C5: 22uF; 0603
C11, C13: 1.0uF; 0603
C18: 2.2uF; 0603
D1: ESD Diode; SOT-23-6
D3, D6: 3A/10V/280mV; SOD-323
D4: Yellow; LED-0603
D5: GREEN; LED-0603
D7: RED; LED-0603
D8: BLUE; LED-0603
D10: PESD0402; 0402-TIGHT
E1, E2: SMA; SMA-EDGE
F1: 6V 0.5A; 0805
FB1: 470Ω; 0603
FRAME2: FRAME-LEDGER; CREATIVE_COMMONS
GP: JUMPER-SMT_2_NC_TRACE_SILK; SMT-JUMPER_2_NC_TRACE_SILK
H1, H2, H3, H4: STAND-OFF
J1, J9: CONN_041X04_NO_SILK_NO_POP; 1X04_NO_SILK
J2: CONN_06JST-SMD-LOCKING; JST-6-SMD-1.25MM-LOCKING
J3: MICROSD; MICROSD-EXTERNALPIN
J4, J8: CONN_021X02_NO_SILK; 1X02_NO_SILK
J5: USB Female Type C Connector; USB-C-16P_4LAYER-PADS
J7: CONN_10NO_SILK_PTH_FEMALE; 1X10_NO_SILK
J10: CONN_06NO_SILK_FEMALE_PTH; 1X06_NO_SILK
J12: CONN_06PAD; 1X06_SOLDER_PADS
JP1: USB_SOLDER_PADS; USB-SOLDER-PADS
JP21, JP61, JP71, JP81: FIDUCIALUFIDUCIAL; FIDUCIAL-MICRO
L1: 39nH; 0603
LOG: JUMPER-SMT_2_NC_TRACE_SILK; SMT-JUMPER_2_NC_TRACE_SILK
LOGO2: OSHW-LOGOMINI; OSHW-LOGO-MINI
LOGO4: SFE_LOGO_NAME_FLAME10_MM; SFE_LOGO_NAME_FLAME_10MM
MEAS: JUMPER-COMBO_2_NC_TRACE; COMBO-JUMPER_2_NC_TRACE
PPS: JUMPER-SMT_2_NC_TRACE_SILK; SMT-JUMPER_2_NC_TRACE_SILK
PWR: JUMPER-SMT_2_NC_TRACE_SILK; SMT-JUMPER_2_NC_TRACE_SILK
R2, R3, R5: 10k; 0603
R4, R8, R10, R11, R12: 1k; 0603
R16, R17: 5.1k; 0603
S1: MOMENTARY-SWITCH-SPST-SMD-4.6X2.8MM; TACTILE_SWITCH_SMD_4.6X2.8MM
S2: MOMENTARY-SWITCH-SPST-SMD-5.2-TALL-REDUNDANT; TACTILE_SWITCH_SMD_5.2MM
TP1: JUMPER-SMT_2_NC_TRACE_SILK; SMT-JUMPER_2_NC_TRACE_SILK
U1: MOSAIC-X5X5; MOSAIC-X5
U2: SN74AHC1G125DBVR; SOT23-5
U5: AP2112K-3.3V; SOT23-5
U$2: SPECIAL_INSTRUCTIONS-ORDERING; ORDERING_INSTRUCTIONS
VB: JUMPER-SMT_2_NC_TRACE_SILK; SMT-JUMPER_2_NC_TRACE_SILK

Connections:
1.8V: R5.2, U1.AC4 (1V8_OUT)
3.3V: C4.2, C5.1, C11.1, C12.2, C18.1, C19.1, C20.1, J3.4 (VCC), J4.2, J7.2, PWR.2, R2.2, R3.2, U1.A18 (VDD_3V3), U1.A19 (VDD_3V3), U1.A20 (VDD_3V3), U1.B18 (VDD_3V3), U1.B19 (VDD_3V3), U1.B20 (VDD_3V3), U1.C18 (VDD_3V3), U1.C19 (VDD_3V3), U1.C20 (VDD_3V3), U2.5 (P$V+), U5.5 (OUT), VB.1
5V: C3.1, C13.1, F1.1, FB1.1, U5.1 (IN), U5.3 (EN)
!RESET!: J7.6, S1.3 (2), S1.4 (2), U1.A11 (!RST!)
ANT_VCC: C1.1, L1.2
CC1: J5.A5 (CC1), R17.2
CC2: J5.B5 (CC2), R16.2
COM1_CTS: J9.4, U1.E1 (COM1_CTS)
COM1_RTS: J9.3, U1.C1 (COM1_RTS)
COM1_RX: J9.1, U1.B1 (COM1_RX)
COM1_TX: J9.2, U1.D1 (COM1_TX)
COM2_CTS: J1.4, U1.J1 (COM2_CTS)
COM2_RTS: J1.3, U1.G1 (COM2_RTS)
COM2_RX: J1.1, U1.F1 (COM2_RX)
COM2_TX: J1.2, U1.H1 (COM2_TX)
COM3_CTS: J2.5, J12.5, U1.N1 (COM3_CTS)
COM3_RTS: J2.4, J12.4, U1.L1 (COM3_RTS)
COM3_RX: J2.2, J12.2, U1.K1 (COM3_RX)
COM3_TX: J2.3, J12.3, U1.M1 (COM3_TX)
COM4_RX: J8.2, U1.D3 (COM4_RX)
COM4_TX: J8.1, U1.E3 (COM4_TX)
D+: D1.4 (IO3), J5.A6 (D+), J5.B6 (D+), JP1.D+ (3), U1.A5 (USB_D+)
D-: D1.6 (IO4), J5.A7 (D-), J5.B7 (D-), JP1.D- (2), U1.A6 (USB_D-)
EVENTA: J10.5, U1.AC6 (EVENTA)
EVENTB: J10.6, U1.AC7 (EVENTB)
GND: C1.2, C3.2, C4.1, C5.2, C11.2, C12.1, C13.2, C18.2, C19.2, C20.2, D1.2 (VSS), D4.C, D5.C, D7.C, D8.C, D10.2, E1.GND@0 (GND), E1.GND@1 (GND), E1.GND@2 (GND), E1.GND@3 (GND), E2.GND@0 (GND), E2.GND@1 (GND), E2.GND@2 (GND), E2.GND@3 (GND), J2.6, J3.6 (GND), J3.10 (GND), J3.11 (GND), J3.12 (GND), J3.13 (GND), J4.1, J5.GND, J5.GND2 (GND), J7.1, J12.6, JP1.GND (4), R16.1, R17.1, S1.1, S1.2 (1), S2.1, S2.2 (1), U1.A3 (RTC_XTALI), U1.A4 (GND), U1.A7 (GND), U1.A15 (GND), U1.A16 (GND), U1.A17 (GND), U1.A21 (GND), U1.A22 (GND), U1.A23 (GND), U1.AA13 (GND), U1.AA14 (GND), U1.AA15 (GND), U1.AA16 (GND), U1.AA17 (GND), U1.AA18 (GND), U1.AA19 (GND), U1.AA20 (GND), U1.AA21 (GND), U1.AA22 (GND), U1.AA23 (GND), U1.AB2 (GND), U1.AB3 (GND), U1.AB4 (GND), U1.AB5 (GND), U1.AB6 (GND), U1.AB7 (GND), U1.AB8 (GND), U1.AB13 (GND), U1.AB14 (GND), U1.AB15 (GND), U1.AB16 (GND), U1.AB17 (GND), U1.AB18 (GND), U1.AB19 (GND), U1.AB20 (GND), U1.AB21 (GND), U1.AB22 (GND), U1.AB23 (GND), U1.AC13 (GND), U1.AC15 (GND), U1.AC18 (GND), U1.AC19 (GND), U1.AC21 (GND), U1.AC22 (GND), U1.AC23 (GND), U1.B4 (GND), U1.B5 (GND), U1.B6 (GND), U1.B7 (GND), U1.B13 (GND), U1.B17 (GND), U1.B21 (GND), U1.C4 (GND), U1.C7 (GND), U1.C15 (GND), U1.C16 (GND), U1.C17 (GND), U1.C23 (GND), U1.D2 (GND), U1.D21 (GND), U1.D22 (GND), U1.D23 (GND), U1.E2 (GND), U1.E21 (GND), U1.E22 (GND), U1.E23 (GND), U1.F21 (GND), U1.F22 (GND), U1.F23 (GND), U1.G2 (GND), U1.G21 (GND), U1.G23 (GND), U1.H21 (GND), U1.H22 (GND), U1.H23 (GND), U1.J21 (GND), U1.J22 (GND), U1.J23 (GND), U1.K2 (GND), U1.K21 (GND), U1.K22 (GND), U1.K23 (GND), U1.L21 (GND), U1.L22 (GND), U1.L23 (GND), U1.M21 (GND), U1.M22 (GND), U1.N21 (GND), U1.N22 (GND), U1.P1 (GND), U1.P2 (GND), U1.P3 (GND), U1.P21 (GND), U1.P22 (GND), U1.R3 (GND), U1.R21 (GND), U1.R22 (GND), U1.T21 (GND), U1.T22 (GND), U1.T23 (GND), U1.U2 (GND), U1.U21 (GND), U1.U22 (GND), U1.U23 (GND), U1.V21 (GND), U1.V22 (GND), U1.W21 (GND), U1.W22 (GND), U1.W23 (GND), U1.Y2 (GND), U1.Y21 (GND), U1.Y22 (GND), U1.Y23 (GND), U2.1 (!EN), U2.3 (P$V-), U5.2 (GND)
GP1: J10.1, U1.AA4 (GPIO_1)
GP2: J10.2, U1.L3 (GPIO_2)
GPS_ANT1: D10.1, E1.SIG (SIGNAL), L1.1, U1.AC20 (ANT_1)
GP_LED: GP.2, J7.8, U1.A14 (GP_LED)
LOG_BTN: J10.3, R8.2, U1.K3 (LOG_BTN)
LOG_LED: J7.9, LOG.2, U1.B2 (LOG_LED)
MEAS: D3.C, D6.C, MEAS.2, MEAS.4 (2)
MODULE_RDY: J7.7, U1.A12 (MODULE_RDY)
unnamed: R8.1, S2.3 (2), S2.4 (2)
unnamed: D4.A, R11.1
unnamed: PPS.1, R11.2
unnamed: F1.2, MEAS.1, MEAS.3 (1)
unnamed: U1.AC16 (REF_OUT), U1.AC17 (REF_IN)
unnamed: D8.A, R4.1
unnamed: GP.1, R4.2
unnamed: D7.A, R10.1
unnamed: U1.M23 (2V8_IN), U1.N23 (2V8_OUT)
unnamed: D5.A, R12.1
unnamed: LOG.1, R12.2
unnamed: PWR.1, R10.2
unnamed: R5.1, U1.AC3 (SYNC)
PMIC_ON_REQ: J7.10, U1.B16 (PMIC_ON_REQ)
PPS: E2.SIG (SIGNAL), TP1.2, U2.4 (Y)
PPS_3V3: J10.4, PPS.2, TP1.1
PPS_18V: U1.AC8 (PPS), U2.2 (A)
SD_CLK: J3.5 (CLK/SCK), U1.AA1 (SD_CLK)
SD_CMD: J3.3 (CMD/SDI), R2.1, U1.AB1 (SD_CMD)
SD_DATA: J3.7 (DAT0/SDO), R3.1, U1.Y1 (SD_DATA)
VANT: FB1.2, U1.P23 (VANT), U1.R23 (VANT)
VIN: D3.A, J2.1, J7.4, J12.1
V_BAT: J7.5, U1.B8 (VDD_BAT), VB.2
V_USB: D1.5 (VCC), D6.A, J5.VBUS1 (VBUS), J5.VBUS2 (VBUS), J7.3, JP1.VBUS (1), U1.A8 (V_USB)

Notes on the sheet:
v10
Board thickness: 1.6mm
Er: 4.6
Copper Thickness (1oz): 1.4mil/0.035mm
RF Trace Width: 13.74mil/0.349mm
Polygon Isolation: 8mil/0.2032mm
No clean process
Dielectric thickness (layer 1 to 2): 0.2mm
https://chemandy.com/calculators/coplanar-waveguide-with-ground-calculator.htm
Coplanar Waveguide Calculation:
USB and 3.3V Regulation
N. Seidle
Cut jumper to disable LED
Stat LEDs
Connections
microSD
Can GP and LOG LEDs be directly driven from module?
Does the log button have a pull up?
BLM18PG471SN1D
Pulse-Per-Second
External V_BAT
Cut trace to attach external supply to V_BAT input for Standby mode

Board: 4 copper layers, 169 parts (68 on the bottom side), 58 nets, no tracks yet.

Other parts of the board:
LOGO1: SFE_LOGO_NAME_FLAME10_MM; SFE_LOGO_NAME_FLAME_10MM
U$1: MOSAIC_0
U$3: GNSS_1
U$4: TRIBAND_2
U$5: MEAS0
U$6, U$135: _ACTIVE_ANT1
U$7: #0
U$8: C4
U$9: D#2
U$10: D#3
U$11: G0
U$12: R5
U$13: RST0
U$14: RX7
U$15: TX6
U$16: V8
U$17: #1
U$18, U$82: COM30
U$21, U$136: TIME0
U$25, U$137: PULSE1
U$31: LOG0
U$69, U$134: L1#2#50
U$78: GP1
U$79: LOG2
U$80: PPS0
U$81: PWR3
U$83, U$99: COM20
U$84, U$109: COM10
U$85, U$108: COM40
U$87, U$93, U$110, U$114: #3#3V#1
U$88, U$100: #CTS#4
U$89, U$95, U$113, U$117: #GND#0
U$90, U$101: #RTS#5
U$91, U$102, U$111: #RX#2
U$92, U$103, U$112: #TX#3
U$94, U$104: #CTS_#4
U$96, U$105: #RTS_#5
U$97, U$106, U$115: #RX_#2
U$98, U$107, U$116: #TX_#3
U$118: ##RST##2
U$119: #GP_LED#4
U$120: #LOG#5
U$121: #PMIC#6
U$122: #RDY#3
U$123, U$130: #VIN#1
U$124, U$131: #VUSB#0
U$125, U$132: #V_BAT#7
U$126: #LOG_LED_#5
U$127: #PMIC_#6
U$128: #GP_LED_#4
U$129: #RDY_#3
U$133: #_#RST##2
U$138: GNSS1
U$139: MOSAIC0
U$140: TRIBAND2
U$141: #LOG_LED#2
U$142: #PPS_LED#1
U$143: #GP_LED#3
U$144: #PWR_LED#0
U$145: #V_BAT#4
U$146: #A#8
U$147: #B#10
U$148: #EVENTA_#9
U$149: #EVENTB#11
U$150: #GP1#0
U$151: #GP1_#2
U$152: #GP2#1
U$153: #GP2_#3
U$154: #LOG#4
U$155: #LOG_BTN_#5
U$156: #PPS#6
U$157: #PPS_#7

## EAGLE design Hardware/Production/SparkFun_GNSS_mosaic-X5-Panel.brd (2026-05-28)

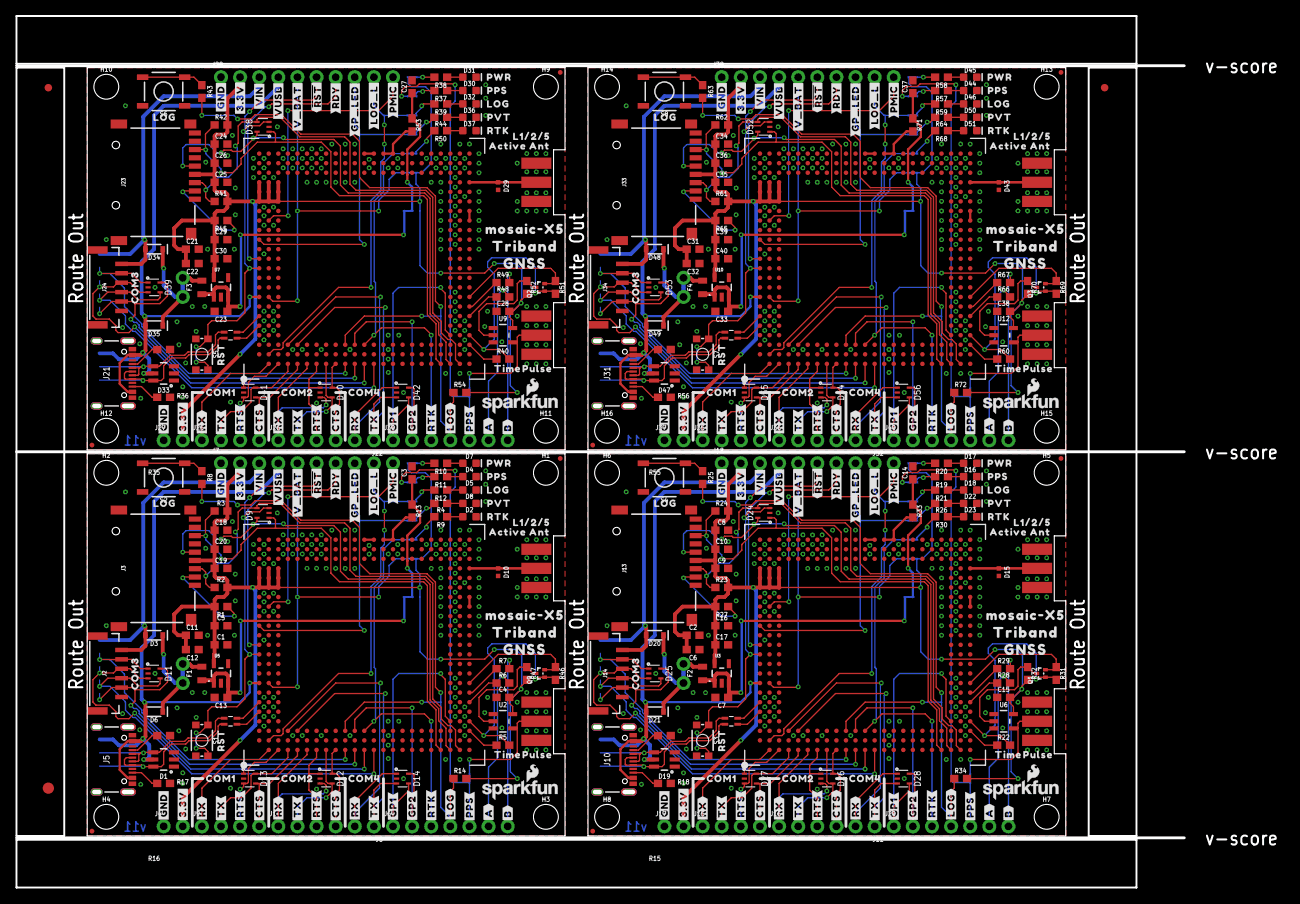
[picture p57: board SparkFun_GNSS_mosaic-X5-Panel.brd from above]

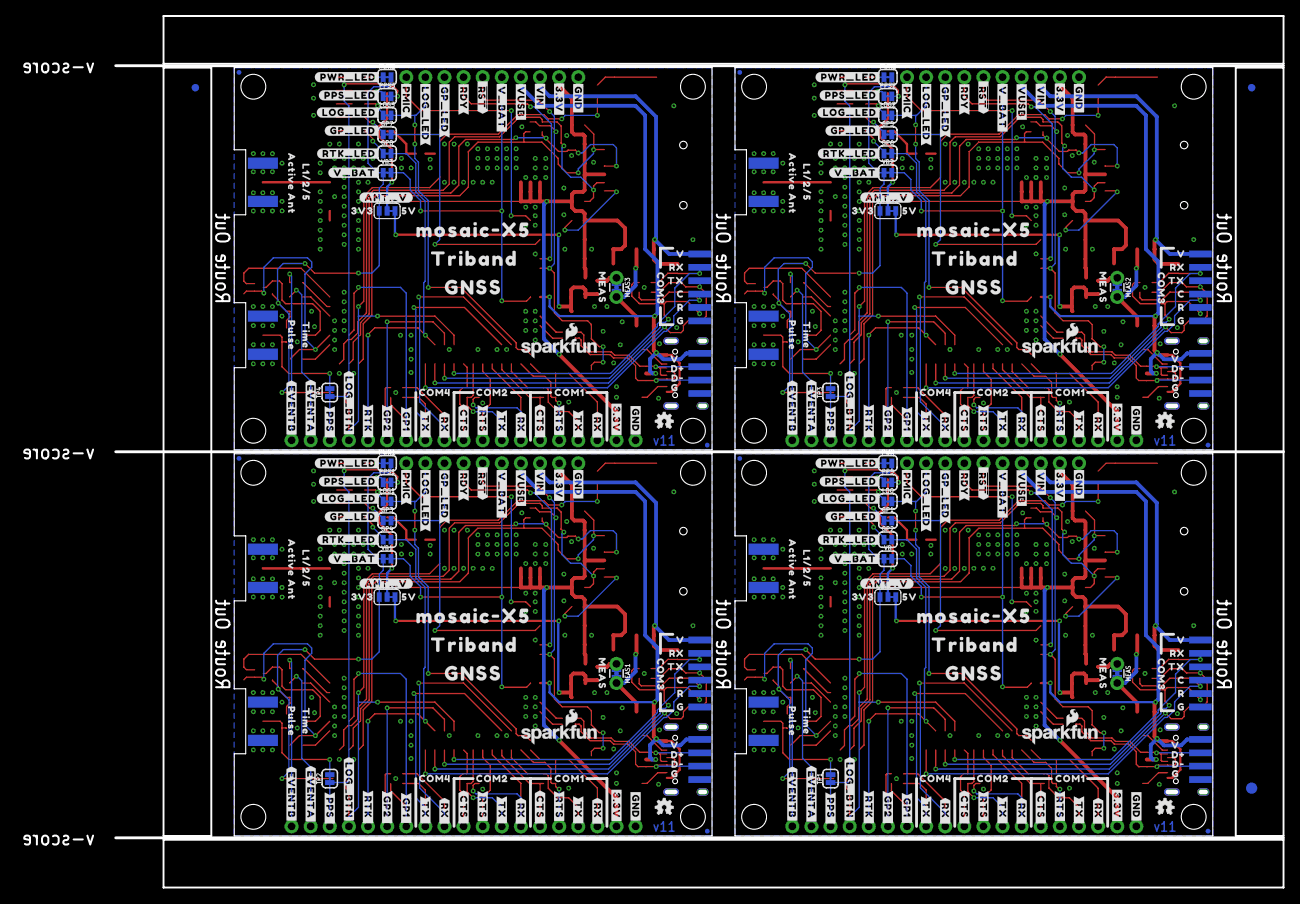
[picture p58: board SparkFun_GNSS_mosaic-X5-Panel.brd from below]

Board: 4 copper layers, 155.2 x 115.8 mm, 766 parts (303 on the bottom side), 268 nets.

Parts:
ANT_V, ANT_V1, ANT_V2, ANT_V3: SMT-JUMPER_3_1-NC_TRACE_SILK
C1, C3, C10, C14, C17, C20, C26, C27, C30, C36, C37, C40: 10uF; 0603
C2, C7, C11, C13, C21, C23, C31, C33: 1.0uF; 0603
C4, C6, C9, C12, C15, C19, C22, C25, C28, C32, C35, C38: 0.1uF; 0603
C5, C16, C29, C39: 22uF; 0603
C8, C18, C24, C34: 2.2uF; 0603
D1, D19, D33, D47: ESD Diode; SOT-23-6
D2, D23, D37, D51: WHITE; LED-0603
D3, D6, D20, D21, D34, D35, D48, D49: 3A/10V/280mV; SOD-323
D4, D16, D30, D44: Yellow; LED-0603
D5, D18, D32, D46: GREEN; LED-0603
D7, D17, D31, D45: RED; LED-0603
D8, D22, D36, D50: BLUE; LED-0603
D9, D11, D12, D13, D14, D24, D25, D26, D27, D28, D38, D39, D40, D41, D42, D52, D53, D54, D55, D56: PESDXL4UGUG; SOT353
D10, D15, D29, D43: PESD0402; 0402-TIGHT
E1, E2, E3, E4, E5, E6, E7, E8: SMA; SMA-EDGE
E$1, E$2, E$3, E$4: FIDUCIAL-1X2
E$5, E$6: FIDUCIAL-1.5X3
F1, F2, F3, F4: 6V 0.5A; 0805
GP1, GP2, GP3, GP4, GP5, GP6, GP7, GP8: JUMPER-SMT_2_NC_TRACE_SILK; SMT-JUMPER_2_NC_TRACE_SILK
H1, H2, H3, H4, H5, H6, H7, H8, H9, H10, H11, H12, H13, H14, H15, H16: STAND-OFF
J1, J9, J15, J16, J25, J26, J35, J36: 1X04_NO_SILK
J2, J14, J24, J34: JST-6-SMD-1.25MM-LOCKING
J3, J13, J23, J33: MICROSD; MICROSD-EXTERNALPIN
J4, J8, J11, J17, J22, J27, J32, J37: 1X02_NO_SILK
J5, J10, J21, J31: USB Female Type C Connector; USB-C-16P_4LAYER-PADS
J6, J20, J30, J40: 1X07_NO_SILK
J7, J18, J28, J38: 1X10_NO_SILK
J12, J19, J29, J39: 1X06_SOLDER_PADS
JP1, JP6, JP11, JP16: USB_SOLDER_PADS; USB-SOLDER-PADS
JP2, JP3, JP4, JP5, JP7, JP8, JP9, JP10, JP12, JP13, JP14, JP15, JP21, JP61, JP71, JP81: FIDUCIALUFIDUCIAL; FIDUCIAL-MICRO
LOG, LOG1, LOG2, LOG3: JUMPER-SMT_2_NC_TRACE_SILK; SMT-JUMPER_2_NC_TRACE_SILK
LOGO1, LOGO3, LOGO4, LOGO6, LOGO7, LOGO9, LOGO10, LOGO12: SFE_LOGO_NAME_FLAME10_MM; SFE_LOGO_NAME_FLAME_10MM
LOGO2, LOGO5, LOGO8, LOGO11: OSHW-LOGOMINI; OSHW-LOGO-MINI
MEAS, MEAS1, MEAS2, MEAS3: JUMPER-COMBO_2_NC_TRACE; COMBO-JUMPER_2_NC_TRACE
PPS, PPS1, PPS2, PPS3: JUMPER-SMT_2_NC_TRACE_SILK; SMT-JUMPER_2_NC_TRACE_SILK
PWR, PWR1, PWR2, PWR3: JUMPER-SMT_2_NC_TRACE_SILK; SMT-JUMPER_2_NC_TRACE_SILK
Q1, Q2, Q3, Q9: 20V/0.2A/8MHz/1.2Ω/1Vth; SOT-416FL
R1, R2, R3, R5, R14, R22, R23, R24, R27, R34, R40, R41, R42, R45, R54, R60, R61, R62, R65, R72: 10k; 0603
R4, R11, R19, R26, R31, R32, R37, R44, R46, R47, R51, R52, R57, R64, R69, R70: 2.2k; 0603
R6, R7, R28, R29, R48, R49, R66, R67: 169K; 0603
R8, R9, R10, R20, R25, R30, R38, R43, R50, R58, R63, R68: 1k; 0603
R12, R21, R39, R59: 330; 0603
R13, R33, R53, R71: 0; 0603
R15, R16, R17, R18, R35, R36, R55, R56: 5.1k; 0603
S1, S3, S5, S7: MOMENTARY-SWITCH-SPST-SMD-4.6X2.8MM; TACTILE_SWITCH_SMD_4.6X2.8MM
S2, S4, S6, S8: MOMENTARY-SWITCH-SPST-SMD-5.2-TALL-REDUNDANT; TACTILE_SWITCH_SMD_5.2MM
T1, T2, T3, T4: RFCMF1220100M4T
TP1, TP2, TP3, TP4: JUMPER-SMT_2_NC_TRACE_SILK; SMT-JUMPER_2_NC_TRACE_SILK
U1, U4, U8, U11: MOSAIC-X5X5; MOSAIC_LGA
U2, U6, U9, U12: SN74AHC1G125DBVR; SOT23-5
U3, U5, U7, U10: 3.3V; SOT23-5
U$1, U$193, U$301, U$409: V0
U$2, U$21, U$136, U$164, U$217, U$272, U$325, U$380: TIME0
U$3, U$179, U$287, U$395: GNSS_1
U$4, U$180, U$288, U$396: TRIBAND_2
U$5, U$181, U$289, U$397: MEAS0
U$6, U$47, U$135, U$163, U$220, U$271, U$328, U$379: _ACTIVE_ANT1
U$7, U$195, U$303, U$411: #RTK#0
U$8, U$182, U$290, U$398: C4
U$9, U$183, U$291, U$399: D#2
U$10, U$184, U$292, U$400: D#3
U$11, U$185, U$293, U$401: G0
U$12, U$186, U$294, U$402: R5
U$13, U$48, U$221, U$329: RST0
U$14, U$187, U$295, U$403: RX7
U$15, U$188, U$296, U$404: TX6
U$16, U$189, U$297, U$405: V8
U$17, U$214, U$322, U$430: #EVENTA#0
U$18, U$53, U$82, U$190, U$226, U$298, U$334, U$406: COM30
U$19, U$191, U$299, U$407: MOSAIC#X50
U$20, U$192, U$300, U$408: MOSAIC#X5_0
U$22, U$194, U$302, U$410: G1
U$23, U$196, U$304, U$412: 3V30
U$24, U$197, U$305, U$413: 5V0
U$25, U$32, U$137, U$165, U$218, U$273, U$326, U$381: PULSE1
U$26, U$198, U$306, U$414: #ANT_V#0
U$27, U$199, U$307, U$415: #RTK_LED#0
U$28, U$200, U$308, U$416: RTK0
U$29, U$201, U$309, U$417: PVT0
U$30, U$202, U$310, U$418: #GP1_#0
U$31, U$49, U$222, U$330: LOG0
U$33, U$203, U$311, U$419: #GP2_#0
U$34, U$204, U$312, U$420: #PPS_#0
U$35, U$205, U$313, U$421: #LOG_BTN#0
U$36, U$206, U$314, U$422: #LOG_L#0
U$37, U$207, U$315, U$423: #RDY#0
U$38, U$208, U$316, U$424: #GP_LED#0
U$39, U$209, U$317, U$425: #LOG_LED#0
U$40, U$210, U$318, U$426: #PMIC#0
U$41, U$42, U$211, U$212, U$319, U$320, U$427, U$428: #RTS#0
U$43, U$213, U$321, U$429: #RTK_#0
U$44, U$215, U$323, U$431: #EVENTB#0
U$46, U$69, U$134, U$162, U$219, U$270, U$327, U$378: L1#2#50
U$50, U$79, U$223, U$331: LOG2
U$51, U$80, U$224, U$332: PPS0
U$52, U$81, U$225, U$333: PWR3
U$54, U$83, U$96, U$99, U$227, U$252, U$335, U$360: COM20
U$55, U$84, U$109, U$120, U$228, U$254, U$336, U$362: COM10
U$56, U$85, U$105, U$108, U$229, U$253, U$337, U$361: COM40
U$57, U$63, U$87, U$93, U$110, U$114, U$126, U$128, U$230, U$236, U$255, U$257, U$338, U$344, U$363, U$365: #3#3V#1
U$58, U$68, U$88, U$100, U$231, U$241, U$339, U$349: #CTS#4
U$59, U$65, U$89, U$95, U$113, U$117, U$127, U$129, U$232, U$238, U$256, U$258, U$340, U$346, U$364, U$366: #GND#0
U$60, U$70, U$90, U$101, U$233, U$242, U$341, U$350: #RTS#5
U$61, U$71, U$76, U$91, U$102, U$111, U$234, U$243, U$248, U$342, U$351, U$356: #RX#2
U$62, U$72, U$77, U$92, U$103, U$112, U$235, U$244, U$249, U$343, U$352, U$357: #TX#3
U$64, U$73, U$94, U$104, U$237, U$245, U$345, U$353: #CTS_#4
U$66, U$74, U$78, U$97, U$106, U$115, U$239, U$246, U$250, U$347, U$354, U$358: #RX_#2
U$67, U$75, U$86, U$98, U$107, U$116, U$240, U$247, U$251, U$348, U$355, U$359: #TX_#3
U$118, U$139, U$259, U$367: ##RST##2
U$119, U$148, U$260, U$368: #GP_LED#4
U$121, U$149, U$261, U$369: #PMIC#6
U$122, U$151, U$262, U$370: #RDY#3
U$123, U$130, U$153, U$158, U$263, U$266, U$371, U$374: #VIN#1
U$124, U$131, U$155, U$159, U$264, U$267, U$372, U$375: #VUSB#0
U$125, U$132, U$157, U$160, U$265, U$268, U$373, U$376: #V_BAT#7
U$133, U$161, U$269, U$377: #_#RST##2
U$138, U$166, U$274, U$382: GNSS1
U$140, U$167, U$275, U$383: TRIBAND2
U$141, U$169, U$277, U$385: #LOG_LED#2
U$142, U$170, U$278, U$386: #PPS_LED#1
U$143, U$168, U$276, U$384: #GP_LED#3
U$144, U$171, U$279, U$387: #PWR_LED#0
U$145, U$172, U$280, U$388: #V_BAT#4
U$146, U$173, U$281, U$389: #A#8
U$147, U$174, U$282, U$390: #B#10
U$150, U$175, U$283, U$391: #GP1#0
U$152, U$176, U$284, U$392: #GP2#1
U$154, U$177, U$285, U$393: #LOG#4
U$156, U$178, U$286, U$394: #PPS#6
VB, VB1, VB2, VB3: JUMPER-SMT_2_NC_TRACE_SILK; SMT-JUMPER_2_NC_TRACE_SILK

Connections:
1.8V: Q9.1, R5.2, R46.2, U1.AC4
1.8V1: Q1.1, R22.2, R31.2, U4.AC4
1.8V2: Q2.1, R40.2, R51.2, U8.AC4
1.8V3: Q3.1, R60.2, R69.2, U11.AC4
3.3V: ANT_V.1, C1.1, C4.2, C5.1, C11.1, C12.2, C18.1, C19.1, C20.1, J3.4, J4.2, J7.2, PWR.2, R1.2, R2.2, R3.2, R14.2, R47.2, U1.A18, U1.A19, U1.A20, U1.B18, U1.B19, U1.B20, U1.C18, U1.C19, U1.C20, U2.5, U5.5, VB.1
3.3V1: ANT_V1.1, C2.1, C6.2, C8.1, C9.1, C10.1, C15.2, C16.1, C17.1, J13.4, J17.2, J18.2, PWR1.2, R23.2, R24.2, R27.2, R32.2, R34.2, U3.5, U4.A18, U4.A19, U4.A20, U4.B18, U4.B19, U4.B20, U4.C18, U4.C19, U4.C20, U6.5, VB1.1
3.3V2: ANT_V2.1, C21.1, C22.2, C24.1, C25.1, C26.1, C28.2, C29.1, C30.1, J23.4, J27.2, J28.2, PWR2.2, R41.2, R42.2, R45.2, R52.2, R54.2, U7.5, U8.A18, U8.A19, U8.A20, U8.B18, U8.B19, U8.B20, U8.C18, U8.C19, U8.C20, U9.5, VB2.1
3.3V3: ANT_V3.1, C31.1, C32.2, C34.1, C35.1, C36.1, C38.2, C39.1, C40.1, J33.4, J37.2, J38.2, PWR3.2, R61.2, R62.2, R65.2, R70.2, R72.2, U10.5, U11.A18, U11.A19, U11.A20, U11.B18, U11.B19, U11.B20, U11.C18, U11.C19, U11.C20, U12.5, VB3.1
5V: ANT_V.3, C13.1, F1.1, U5.1, U5.3
5V1: ANT_V1.3, C7.1, F2.1, U3.1, U3.3
5V2: ANT_V2.3, C23.1, F3.1, U7.1, U7.3
5V3: ANT_V3.3, C33.1, F4.1, U10.1, U10.3
!RESET!: D9.3, J7.6, S1.3, S1.4, U1.A11
!RESET!1: D24.3, J18.6, S3.3, S3.4, U4.A11
!RESET!2: D38.3, J28.6, S5.3, S5.4, U8.A11
!RESET!3: D52.3, J38.6, S7.3, S7.4, U11.A11
ANT_V: ANT_V.2, C3.1, R13.1
ANT_V1: ANT_V1.2, C14.1, R33.1
ANT_V2: ANT_V2.2, C27.1, R53.1
ANT_V3: ANT_V3.2, C37.1, R71.1
CC1: J5.A5, R17.2
CC2: J5.B5, R16.2
CC3: J10.A5, R18.2
CC4: J10.B5, R15.2
CC5: J21.A5, R36.2
CC6: J21.B5, R35.2
CC7: J31.A5, R56.2
CC8: J31.B5, R55.2
COM1_CTS: D13.4, J9.4, U1.E1
COM1_CTS1: D27.4, J15.4, U4.E1
COM1_CTS2: D41.4, J25.4, U8.E1
COM1_CTS3: D55.4, J35.4, U11.E1
COM1_RTS: D13.3, J9.3, U1.C1
COM1_RTS1: D27.3, J15.3, U4.C1
COM1_RTS2: D41.3, J25.3, U8.C1
COM1_RTS3: D55.3, J35.3, U11.C1
COM1_RX: D13.1, J9.1, U1.B1
COM1_RX1: D27.1, J15.1, U4.B1
COM1_RX2: D41.1, J25.1, U8.B1
COM1_RX3: D55.1, J35.1, U11.B1
COM1_TX: D13.5, J9.2, U1.D1
COM1_TX1: D27.5, J15.2, U4.D1
COM1_TX2: D41.5, J25.2, U8.D1
COM1_TX3: D55.5, J35.2, U11.D1
COM2_CTS: D12.5, J1.4, U1.J1
COM2_CTS1: D26.5, J16.4, U4.J1
COM2_CTS2: D40.5, J26.4, U8.J1
COM2_CTS3: D54.5, J36.4, U11.J1
COM2_RTS: D12.1, J1.3, U1.G1
COM2_RTS1: D26.1, J16.3, U4.G1
COM2_RTS2: D40.1, J26.3, U8.G1
COM2_RTS3: D54.1, J36.3, U11.G1
COM2_RX: D12.3, J1.1, U1.F1
COM2_RX1: D26.3, J16.1, U4.F1
COM2_RX2: D40.3, J26.1, U8.F1
COM2_RX3: D54.3, J36.1, U11.F1
COM2_TX: D12.4, J1.2, U1.H1
COM2_TX1: D26.4, J16.2, U4.H1
COM2_TX2: D40.4, J26.2, U8.H1
COM2_TX3: D54.4, J36.2, U11.H1
COM3_CTS: D11.4, J2.4, J12.4, U1.N1
COM3_CTS1: D25.4, J14.4, J19.4, U4.N1
COM3_CTS2: D39.4, J24.4, J29.4, U8.N1
COM3_CTS3: D53.4, J34.4, J39.4, U11.N1
COM3_RTS: D11.5, J2.5, J12.5, U1.L1
COM3_RTS1: D25.5, J14.5, J19.5, U4.L1
COM3_RTS2: D39.5, J24.5, J29.5, U8.L1
COM3_RTS3: D53.5, J34.5, J39.5, U11.L1
COM3_RX: D11.1, J2.2, J12.2, U1.K1
COM3_RX1: D25.1, J14.2, J19.2, U4.K1
COM3_RX2: D39.1, J24.2, J29.2, U8.K1
COM3_RX3: D53.1, J34.2, J39.2, U11.K1
COM3_TX: D11.3, J2.3, J12.3, U1.M1
COM3_TX1: D25.3, J14.3, J19.3, U4.M1
COM3_TX2: D39.3, J24.3, J29.3, U8.M1
COM3_TX3: D53.3, J34.3, J39.3, U11.M1
COM4_RX: D14.1, J8.2, U1.D3
COM4_RX1: D28.1, J11.2, U4.D3
COM4_RX2: D42.1, J22.2, U8.D3
COM4_RX3: D56.1, J32.2, U11.D3
COM4_TX: D14.3, J8.1, U1.E3
COM4_TX1: D28.3, J11.1, U4.E3
COM4_TX2: D42.3, J22.1, U8.E3
COM4_TX3: D56.3, J32.1, U11.E3
D+: T1.B2, U1.A5
D+1: T2.B2, U4.A5
D+2: T3.B2, U8.A5
D+3: T4.B2, U11.A5
D-: T1.A2, U1.A6
D-1: T2.A2, U4.A6
D-2: T3.A2, U8.A6
D-3: T4.A2, U11.A6
EVENTA: J6.6, R6.2
EVENTA1: J20.6, R28.2
EVENTA2: J30.6, R48.2
EVENTA3: J40.6, R66.2
EVENTB: J6.7, R7.2
EVENTB1: J20.7, R29.2
EVENTB2: J30.7, R49.2
EVENTB3: J40.7, R67.2
GND: C1.2, C3.2, C4.1, C5.2, C11.2, C12.1, C13.2, C18.2, C19.2, C20.2, D1.2, D2.C, D4.C, D5.C, D7.C, D8.C, D9.2, D10.2, D11.2, D12.2, D13.2, D14.2, E1.GND@0, E1.GND@1, E1.GND@2, E1.GND@3, E2.GND@0, E2.GND@1, E2.GND@2, E2.GND@3, J2.6, J3.6, J3.10, J3.11, J3.12, J3.13, J4.1, J5.GND, J5.GND2, J7.1, J12.6, JP1.GND, R16.1, R17.1, S1.1, S1.2, S2.1, S2.2, U1.A3, U1.A4, U1.A7, U1.A15, U1.A16, U1.A17, U1.A21, U1.A22, U1.A23, U1.AA13, U1.AA14, U1.AA15, U1.AA16, U1.AA17, U1.AA18, U1.AA19, U1.AA20, U1.AA21, U1.AA22, U1.AA23, U1.AB2, U1.AB3, U1.AB4, U1.AB5, U1.AB6, U1.AB7, U1.AB8, U1.AB13, U1.AB14, U1.AB15, U1.AB16, U1.AB17, U1.AB18, U1.AB19, U1.AB20, U1.AB21, U1.AB22, U1.AB23, U1.AC13, U1.AC15, U1.AC18, U1.AC19, U1.AC21, U1.AC22, U1.AC23, U1.B4, U1.B5, U1.B6, U1.B7, U1.B13, U1.B17, U1.B21, U1.C4, U1.C7, U1.C15, U1.C16, U1.C17, U1.C23, U1.D2, U1.D21, U1.D22, U1.D23, U1.E2, U1.E21, U1.E22, U1.E23, U1.F21, U1.F22, U1.F23, U1.G2, U1.G21, U1.G23, U1.H21, U1.H22, U1.H23, U1.J21, U1.J22, U1.J23, U1.K2, U1.K21, U1.K22, U1.K23, U1.L21, U1.L22, U1.L23, U1.M21, U1.M22, U1.N21, U1.N22, U1.P1, U1.P2, U1.P3, U1.P21, U1.P22, U1.R3, U1.R21, U1.R22, U1.T21, U1.T22, U1.T23, U1.U2, U1.U21, U1.U22, U1.U23, U1.V21, U1.V22, U1.V23, U1.W21, U1.W22, U1.W23, U1.Y2, U1.Y21, U1.Y22, U1.Y23, U2.1, U2.3, U5.2
GND1: C2.2, C6.1, C7.2, C8.2, C9.2, C10.2, C14.2, C15.1, C16.2, C17.2, D15.2, D16.C, D17.C, D18.C, D19.2, D22.C, D23.C, D24.2, D25.2, D26.2, D27.2, D28.2, E3.GND@0, E3.GND@1, E3.GND@2, E3.GND@3, E4.GND@0, E4.GND@1, E4.GND@2, E4.GND@3, J10.GND, J10.GND2, J13.6, J13.10, J13.11, J13.12, J13.13, J14.6, J17.1, J18.1, J19.6, JP6.GND, R15.1, R18.1, S3.1, S3.2, S4.1, S4.2, U3.2, U4.A3, U4.A4, U4.A7, U4.A15, U4.A16, U4.A17, U4.A21, U4.A22, U4.A23, U4.AA13, U4.AA14, U4.AA15, U4.AA16, U4.AA17, U4.AA18, U4.AA19, U4.AA20, U4.AA21, U4.AA22, U4.AA23, U4.AB2, U4.AB3, U4.AB4, U4.AB5, U4.AB6, U4.AB7, U4.AB8, U4.AB13, U4.AB14, U4.AB15, U4.AB16, U4.AB17, U4.AB18, U4.AB19, U4.AB20, U4.AB21, U4.AB22, U4.AB23, U4.AC13, U4.AC15, U4.AC18, U4.AC19, U4.AC21, U4.AC22, U4.AC23, U4.B4, U4.B5, U4.B6, U4.B7, U4.B13, U4.B17, U4.B21, U4.C4, U4.C7, U4.C15, U4.C16, U4.C17, U4.C23, U4.D2, U4.D21, U4.D22, U4.D23, U4.E2, U4.E21, U4.E22, U4.E23, U4.F21, U4.F22, U4.F23, U4.G2, U4.G21, U4.G23, U4.H21, U4.H22, U4.H23, U4.J21, U4.J22, U4.J23, U4.K2, U4.K21, U4.K22, U4.K23, U4.L21, U4.L22, U4.L23, U4.M21, U4.M22, U4.N21, U4.N22, U4.P1, U4.P2, U4.P3, U4.P21, U4.P22, U4.R3, U4.R21, U4.R22, U4.T21, U4.T22, U4.T23, U4.U2, U4.U21, U4.U22, U4.U23, U4.V21, U4.V22, U4.V23, U4.W21, U4.W22, U4.W23, U4.Y2, U4.Y21, U4.Y22, U4.Y23, U6.1, U6.3
GND2: C21.2, C22.1, C23.2, C24.2, C25.2, C26.2, C27.2, C28.1, C29.2, C30.2, D29.2, D30.C, D31.C, D32.C, D33.2, D36.C, D37.C, D38.2, D39.2, D40.2, D41.2, D42.2, E5.GND@0, E5.GND@1, E5.GND@2, E5.GND@3, E6.GND@0, E6.GND@1, E6.GND@2, E6.GND@3, J21.GND, J21.GND2, J23.6, J23.10, J23.11, J23.12, J23.13, J24.6, J27.1, J28.1, J29.6, JP11.GND, R35.1, R36.1, S5.1, S5.2, S6.1, S6.2, U7.2, U8.A3, U8.A4, U8.A7, U8.A15, U8.A16, U8.A17, U8.A21, U8.A22, U8.A23, U8.AA13, U8.AA14, U8.AA15, U8.AA16, U8.AA17, U8.AA18, U8.AA19, U8.AA20, U8.AA21, U8.AA22, U8.AA23, U8.AB2, U8.AB3, U8.AB4, U8.AB5, U8.AB6, U8.AB7, U8.AB8, U8.AB13, U8.AB14, U8.AB15, U8.AB16, U8.AB17, U8.AB18, U8.AB19, U8.AB20, U8.AB21, U8.AB22, U8.AB23, U8.AC13, U8.AC15, U8.AC18, U8.AC19, U8.AC21, U8.AC22, U8.AC23, U8.B4, U8.B5, U8.B6, U8.B7, U8.B13, U8.B17, U8.B21, U8.C4, U8.C7, U8.C15, U8.C16, U8.C17, U8.C23, U8.D2, U8.D21, U8.D22, U8.D23, U8.E2, U8.E21, U8.E22, U8.E23, U8.F21, U8.F22, U8.F23, U8.G2, U8.G21, U8.G23, U8.H21, U8.H22, U8.H23, U8.J21, U8.J22, U8.J23, U8.K2, U8.K21, U8.K22, U8.K23, U8.L21, U8.L22, U8.L23, U8.M21, U8.M22, U8.N21, U8.N22, U8.P1, U8.P2, U8.P3, U8.P21, U8.P22, U8.R3, U8.R21, U8.R22, U8.T21, U8.T22, U8.T23, U8.U2, U8.U21, U8.U22, U8.U23, U8.V21, U8.V22, U8.V23, U8.W21, U8.W22, U8.W23, U8.Y2, U8.Y21, U8.Y22, U8.Y23, U9.1, U9.3
GND3: C31.2, C32.1, C33.2, C34.2, C35.2, C36.2, C37.2, C38.1, C39.2, C40.2, D43.2, D44.C, D45.C, D46.C, D47.2, D50.C, D51.C, D52.2, D53.2, D54.2, D55.2, D56.2, E7.GND@0, E7.GND@1, E7.GND@2, E7.GND@3, E8.GND@0, E8.GND@1, E8.GND@2, E8.GND@3, J31.GND, J31.GND2, J33.6, J33.10, J33.11, J33.12, J33.13, J34.6, J37.1, J38.1, J39.6, JP16.GND, R55.1, R56.1, S7.1, S7.2, S8.1, S8.2, U10.2, U11.A3, U11.A4, U11.A7, U11.A15, U11.A16, U11.A17, U11.A21, U11.A22, U11.A23, U11.AA13, U11.AA14, U11.AA15, U11.AA16, U11.AA17, U11.AA18, U11.AA19, U11.AA20, U11.AA21, U11.AA22, U11.AA23, U11.AB2, U11.AB3, U11.AB4, U11.AB5, U11.AB6, U11.AB7, U11.AB8, U11.AB13, U11.AB14, U11.AB15, U11.AB16, U11.AB17, U11.AB18, U11.AB19, U11.AB20, U11.AB21, U11.AB22, U11.AB23, U11.AC13, U11.AC15, U11.AC18, U11.AC19, U11.AC21, U11.AC22, U11.AC23, U11.B4, U11.B5, U11.B6, U11.B7, U11.B13, U11.B17, U11.B21, U11.C4, U11.C7, U11.C15, U11.C16, U11.C17, U11.C23, U11.D2, U11.D21, U11.D22, U11.D23, U11.E2, U11.E21, U11.E22, U11.E23, U11.F21, U11.F22, U11.F23, U11.G2, U11.G21, U11.G23, U11.H21, U11.H22, U11.H23, U11.J21, U11.J22, U11.J23, U11.K2, U11.K21, U11.K22, U11.K23, U11.L21, U11.L22, U11.L23, U11.M21, U11.M22, U11.N21, U11.N22, U11.P1, U11.P2, U11.P3, U11.P21, U11.P22, U11.R3, U11.R21, U11.R22, U11.T21, U11.T22, U11.T23, U11.U2, U11.U21, U11.U22, U11.U23, U11.V21, U11.V22, U11.V23, U11.W21, U11.W22, U11.W23, U11.Y2, U11.Y21, U11.Y22, U11.Y23, U12.1, U12.3
GP1: D14.4, J6.1, U1.AA4
GP2: D14.5, J6.2, U1.L3
GP3: D28.4, J20.1, U4.AA4
GP4: D28.5, J20.2, U4.L3
GP5: D42.4, J30.1, U8.AA4
GP6: D42.5, J30.2, U8.L3
GP7: D56.4, J40.1, U11.AA4
GP8: D56.5, J40.2, U11.L3
GPS_ANT1: D10.1, E1.SIG, U1.AC20
GPS_ANT2: D15.1, E3.SIG, U4.AC20
GPS_ANT3: D29.1, E5.SIG, U8.AC20
GPS_ANT4: D43.1, E7.SIG, U11.AC20
LOG_BTN: J6.4, R8.2, R14.1, U1.K3
LOG_BTN1: J20.4, R25.2, R34.1, U4.K3
LOG_BTN2: J30.4, R43.2, R54.1, U8.K3
LOG_BTN3: J40.4, R63.2, R72.1, U11.K3
LOG_LED: J7.9, LOG.2, U1.B2
LOG_LED1: J18.9, LOG1.2, U4.B2
LOG_LED2: J28.9, LOG2.2, U8.B2
LOG_LED3: J38.9, LOG3.2, U11.B2
MEAS: D3.C, D6.C, MEAS.2, MEAS.4
MEAS1: D20.C, D21.C, MEAS1.2, MEAS1.4
MEAS2: D34.C, D35.C, MEAS2.2, MEAS2.4
MEAS3: D48.C, D49.C, MEAS3.2, MEAS3.4
MODULE_RDY: J7.7, U1.A12
MODULE_RDY1: J18.7, U4.A12
MODULE_RDY2: J28.7, U8.A12
MODULE_RDY3: J38.7, U11.A12
unnamed: R8.1, S2.3, S2.4
unnamed: D4.A, R11.1
unnamed: PPS.1, R11.2
unnamed: F1.2, MEAS.1, MEAS.3
unnamed: J3.2, R1.1
unnamed: R6.1, U1.AC6
unnamed: R7.1, U1.AC7
unnamed: D2.A, R9.1
unnamed: GP2.1, R9.2
unnamed: U1.AC16, U1.AC17
unnamed: D8.A, R4.1
unnamed: GP1.1, R4.2
unnamed: D16.A, R19.1
unnamed: D7.A, R10.1
unnamed: U1.M23, U1.N23
unnamed: D5.A, R12.1
unnamed: LOG.1, R12.2
unnamed: PPS1.1, R19.2
unnamed: D17.A, R20.1
unnamed: PWR.1, R10.2
unnamed: D18.A, R21.1
unnamed: LOG1.1, R21.2
unnamed: PWR1.1, R20.2
unnamed: U4.AC16, U4.AC17
unnamed: U4.M23, U4.N23
unnamed: R5.1, U1.AC3
unnamed: R22.1, U4.AC3
unnamed: R25.1, S4.3, S4.4
unnamed: D22.A, R26.1
unnamed: GP3.1, R26.2
unnamed: F2.2, MEAS1.1, MEAS1.3
unnamed: J13.2, R27.1
unnamed: R28.1, U4.AC6
unnamed: R29.1, U4.AC7
unnamed: D23.A, R30.1
unnamed: GP4.1, R30.2
unnamed: D30.A, R37.1
unnamed: PPS2.1, R37.2
unnamed: D31.A, R38.1
unnamed: D32.A, R39.1
unnamed: LOG2.1, R39.2
unnamed: PWR2.1, R38.2
unnamed: U8.AC16, U8.AC17
unnamed: U8.M23, U8.N23
unnamed: R40.1, U8.AC3
unnamed: R43.1, S6.3, S6.4
unnamed: D36.A, R44.1
unnamed: GP5.1, R44.2
unnamed: F3.2, MEAS2.1, MEAS2.3
unnamed: J23.2, R45.1
unnamed: R48.1, U8.AC6
unnamed: R49.1, U8.AC7
unnamed: D37.A, R50.1
unnamed: GP6.1, R50.2
unnamed: D44.A, R57.1
unnamed: PPS3.1, R57.2
unnamed: D45.A, R58.1
unnamed: D46.A, R59.1
unnamed: LOG3.1, R59.2
unnamed: PWR3.1, R58.2
unnamed: U11.AC16, U11.AC17
unnamed: U11.M23, U11.N23
unnamed: R60.1, U11.AC3
unnamed: R63.1, S8.3, S8.4
unnamed: D50.A, R64.1
unnamed: GP7.1, R64.2
unnamed: F4.2, MEAS3.1, MEAS3.3
unnamed: J33.2, R65.1
unnamed: R66.1, U11.AC6
unnamed: R67.1, U11.AC7
unnamed: D51.A, R68.1
unnamed: GP8.1, R68.2
PMIC_ON_REQ: J7.10, U1.B16
PMIC_ON_REQ1: J18.10, U4.B16
PMIC_ON_REQ2: J28.10, U8.B16
PMIC_ON_REQ3: J38.10, U11.B16
PPS: E2.SIG, TP1.2, U2.4
PPS1: E4.SIG, TP2.2, U6.4
PPS2: E6.SIG, TP3.2, U9.4
PPS3: E8.SIG, TP4.2, U12.4
PPS_1: Q1.3, R32.1, U6.2
PPS_1V1: Q1.2, R31.1, U4.AC8
PPS_1V2: Q2.2, R51.1, U8.AC8
PPS_1V3: Q3.2, R69.1, U11.AC8
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

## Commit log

2023-07-17 Route board.
    [SparkFun_GNSS_mosaic-X5.brd, SparkFun_GNSS_mosaic-X5.sch]
2023-07-19 Add jumper to ant voltage. Add production panel.
    [SparkFun_GNSS_mosaic-X5-Panel.brd, SparkFun_GNSS_mosaic-X5.brd, SparkFun_GNSS_mosaic-X5.sch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]
2023-07-19 Add production files.
    [SparkFun_GNSS_mosaic-X5-Panel.GBO, SparkFun_GNSS_mosaic-X5-Panel.GBP, SparkFun_GNSS_mosaic-X5-Panel.GBS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]
2023-07-26 Fixed tCream on mosaic pin 1.
    [SparkFun_GNSS_mosaic-X5.brd, SparkFun_GNSS_mosaic-X5.sch]
2023-07-26 Adding production files
    [SparkFun_GNSS_mosaic-X5-Panel.GBL, SparkFun_GNSS_mosaic-X5-Panel.GBO, SparkFun_GNSS_mosaic-X5-Panel.GBS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]
2023-07-27 Add ESD and USB choke.
    [SparkFun_GNSS_mosaic-X5-Panel.GBL, SparkFun_GNSS_mosaic-X5-Panel.GBO, SparkFun_GNSS_mosaic-X5-Panel.GBS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]
2023-07-27 Add prod_IDs
    [SparkFun_GNSS_mosaic-X5.brd, SparkFun_GNSS_mosaic-X5.sch]
2023-08-23 Fix 1.8V net, fix silk, add more ESD protection, add LOG pullup.
    [SparkFun_GNSS_mosaic-X5.brd, SparkFun_GNSS_mosaic-X5.sch]
2023-08-23 Add v11 panel.
    [SparkFun_GNSS_mosaic-X5-Panel.brd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]
2023-08-23 Swap CTS/RTS on COM3 JST connector.
    [SparkFun_GNSS_mosaic-X5-Panel.GBL, SparkFun_GNSS_mosaic-X5-Panel.GBO, SparkFun_GNSS_mosaic-X5-Panel.GBP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]
2023-08-23 Update panel files with CTS/RTS
    [SparkFun_GNSS_mosaic-X5-Panel.GBL, SparkFun_GNSS_mosaic-X5-Panel.GBO, SparkFun_GNSS_mosaic-X5-Panel.GBP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]
2023-08-23 Update board measurements.
    [SparkFun_GNSS_mosaic-X5-Panel.brd, SparkFun_GNSS_mosaic-X5.brd, SparkFun_GNSS_mosaic-X5.sch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]
2023-10-03 Add DNP text to SD ESD
    [SparkFun_GNSS_mosaic-X5.sch]
2023-10-10 Change ESD diode on microSD interface.
    [SparkFun_GNSS_mosaic-X5.brd, SparkFun_GNSS_mosaic-X5.sch]
2023-10-17 Update print_view.md
    Add in software sections
2024-02-06 Update LICENSE.md
    Fix carriage returns
2024-02-06 Update LICENSE.md
    Remove carriage returns
2024-02-12 Update README.md
    Move Documentation section higher (mimic RTK mosaic-X5)
    Add badges for MkDocs Material and build
2024-02-12 Update extra.css
    Fix content tab aesthetic for titles including:
    - code blocks
    - keyboard buttons
2024-03-06 Update introduction.md
    Replace soldering station (retired)
    Fix typo
2025-09-10 Update copyright year to 2025
    Changed the copyright year from 2023 to 2025 in LICENSE.md and mkdocs.yml to reflect the current year.
2025-09-10 Add branding SVG icons
    Added multiple SVG logo files for various brands (Arduino, Espressif, Fugro, Hexagon, KiCad, Python, Quectel, Raspberry Pi, Septentrio, SiTime, SparkFun, u-blox)
2025-09-18 Add note for USB silkscreen
    A notice for an error on the silkscreen on the test pads of the USB interface
2025-09-18 Update extra.css
    Sets the width of the QR code images that are rendered for better conformity, when printing out the document
2026-05-28 Remove "Made in the USA" silk - for foreign PCB manufacture
    [SparkFun_GNSS_mosaic-X5-Panel.brd, SparkFun_GNSS_mosaic-X5.brd]
2026-09-18 Add Arduino library

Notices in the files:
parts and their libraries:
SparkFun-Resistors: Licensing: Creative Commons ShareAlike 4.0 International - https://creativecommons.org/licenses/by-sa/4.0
